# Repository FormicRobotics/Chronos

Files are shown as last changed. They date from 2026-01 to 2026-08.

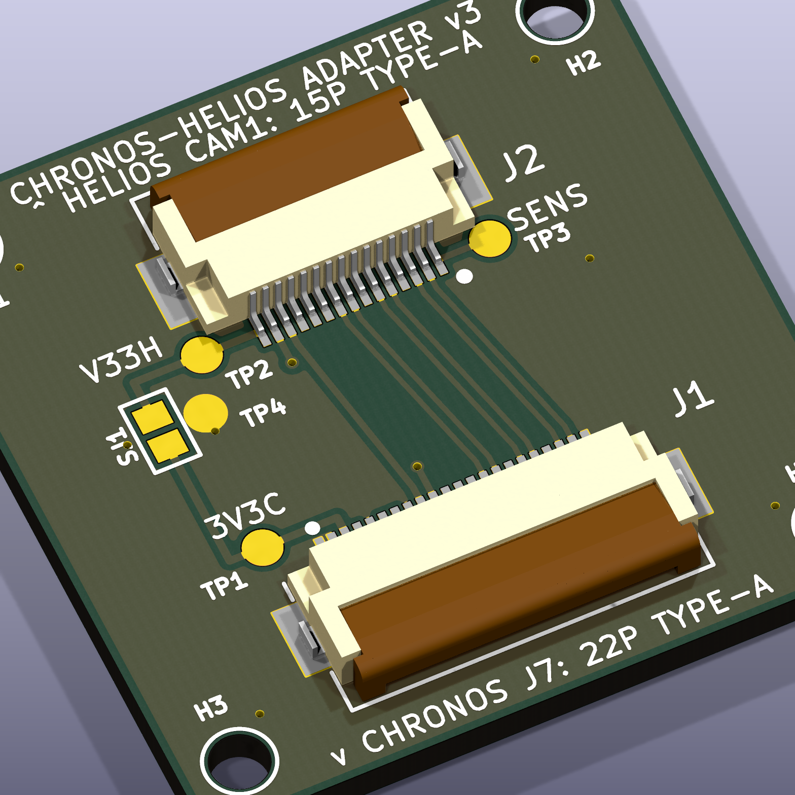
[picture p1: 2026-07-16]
hardware/adapter_chronos_helios/render_3d.png

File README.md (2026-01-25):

<p align="center">
  
  
  
  
</p>

<h1 align="center">⏱️ Chronos</h1>

<p align="center">
  <strong>Multi-Camera MIPI Synchronization System</strong><br>
  <em>Sub-microsecond synchronized capture for computer vision</em>
</p>

<p align="center">
  <a href="#-features">Features</a> •
  <a href="#-architecture">Architecture</a> •
  <a href="#-quick-start">Quick Start</a> •
  <a href="#-documentation">Documentation</a> •
  <a href="#-hardware">Hardware</a>
</p>

---

## ✨ Features

<table>
<tr>
<td width="50%">

### 🎯 Precision Synchronization
- **< 100ns** inter-camera trigger skew
- Hardware-triggered global shutter capture
- PLL-based timing generation
- Per-camera delay calibration

</td>
<td width="50%">

### 🚀 Zero-Copy GPU Pipeline
- Direct DMA to CUDA memory
- NvBuffer + EGL interop
- Triple-buffered capture
- No CPU memcpy overhead

</td>
</tr>
<tr>
<td width="50%">

### 📷 4-Camera Aggregation
- Single CSI-2 port for all cameras
- FPGA virtual channel multiplexing
- 1280×800 @ 120fps per camera
- 10-bit RAW global shutter

</td>
<td width="50%">

### 🔄 Integrated IMU
- BMI088 6-axis IMU
- Synchronized with cameras
- SPI @ 10MHz
- Timestamp correlation

</td>
</tr>
</table>

---

## 🏗️ Architecture

```
┌─────────────────────────────────────────────────────────────────────────┐
│                           CHRONOS SYSTEM                                 │
├─────────────────────────────────────────────────────────────────────────┤
│                                                                          │
│   ┌─────────┐ ┌─────────┐ ┌─────────┐ ┌─────────┐                       │
│   │  CAM 0  │ │  CAM 1  │ │  CAM 2  │ │  CAM 3  │     4× OV9281         │
│   │ OV9281  │ │ OV9281  │ │ OV9281  │ │ OV9281  │     Global Shutter    │
│   └────┬────┘ └────┬────┘ └────┬────┘ └────┬────┘                       │
│        │ CSI-2     │           │           │                             │
│        └───────────┴─────┬─────┴───────────┘                             │
│                          ▼                                               │
│   ┌──────────────────────────────────────────────┐                      │
│   │           CrossLink-NX FPGA                   │     Virtual Channel  │
│   │  ┌────────┐  ┌────────┐  ┌────────────────┐  │     Aggregation      │
│   │  │ 4× RX  │→ │ Buffer │→ │ TX + VC Tag    │  │                      │
│   │  └────────┘  └────────┘  └───────┬────────┘  │                      │
│   │  ┌─────────────────────────────┐ │           │                      │
│   │  │    Trigger Generator (PLL)  │─┼──────────────→ FSIN + IMU        │
│   │  └─────────────────────────────┘ │           │                      │
│   └──────────────────────────────────┼───────────┘                      │
│                                      │ Single 2-lane CSI-2              │
│                                      ▼                                   │
│   ┌──────────────────────────────────────────────────────────────┐      │
│   │                    Jetson Orin NX                             │      │
│   │  ┌─────────┐  ┌─────────┐  ┌─────────┐  ┌─────────────────┐  │      │
│   │  │  NVCSI  │→ │   VI    │→ │ Driver  │→ │   GPU Memory    │  │      │
│   │  │  D-PHY  │  │  DMA    │  │ Demux   │  │   (Zero-Copy)   │  │      │
│   │  └─────────┘  └─────────┘  └─────────┘  └─────────────────┘  │      │
│   └──────────────────────────────────────────────────────────────┘      │
│                                                                          │
└─────────────────────────────────────────────────────────────────────────┘
```

---

## 🚀 Quick Start

### Prerequisites

- NVIDIA Jetson Orin NX with JetPack 5.x
- Chronos PCB (CrossLink-NX FPGA board)
- 4× OV9281 camera modules
- CUDA Toolkit, CMake 3.18+

### Build & Install

```bash
# Clone the repository
git clone https://github.com/your-org/chronos.git
cd chronos

# Build kernel drivers
cd drivers
make all
sudo make install

# Build user-space applications
cd ../app
mkdir build && cd build
cmake ..
make -j$(nproc)
sudo make install
```

### Run Demo

```bash
# Load drivers
sudo modprobe ov9281
sudo modprobe chronos_csi

# Run synchronized capture demo
chronos_demo --rate 60 --exposure 5000

# Run synchronization validation
sync_test -n 1000 -r 120
```

### Example Output

```
Chronos Demo - 4-Camera Synchronized Capture
=============================================
Frame Rate: 60 fps
Exposure: 5000 us

FPS: 60.0  Sync: 1234
  IMU: Accel[  0.02,  -0.01,   9.81] m/s²  Gyro[  0.00,   0.00,   0.00] rad/s
  Frame Sync: Cam0:1234 Cam1:1234 Cam2:1234 Cam3:1234 [SYNC OK]
```

---

## 📁 Project Structure

```
chronos/
├── 📂 fpga/                    # FPGA Firmware
│   ├── 📂 rtl/                 # SystemVerilog sources
│   │   ├── chronos_top.sv      # Top-level module
│   │   ├── csi2_rx.sv          # CSI-2 receivers (×4)
│   │   ├── csi2_tx.sv          # CSI-2 transmitter
│   │   ├── frame_buffer.sv     # SRAM line buffers
│   │   ├── tx_arbiter.sv       # VC multiplexer
│   │   ├── trigger_generator.sv # Sync pulse generator
│   │   └── config_regs.sv      # I2C register bank
│   └── 📂 constraints/         # Timing/pin constraints
│
├── 📂 drivers/                 # Linux Kernel Modules
│   ├── 📂 ov9281/              # OV9281 V4L2 driver
│   ├── 📂 chronos_csi/         # CSI demux driver
│   ├── 📂 imu/                 # BMI088 IIO driver
│   └── chronos-orin-nx.dts     # Device tree overlay
│
├── 📂 app/                     # User-Space Applications
│   └── 📂 src/
│       ├── chronos_capture.h   # Capture library API
│       ├── chronos_capture.c   # Library implementation
│       ├── demo_app.cpp        # Demo application
│       └── sync_test.cpp       # Sync validation tool
│
└── 📂 docs/                    # Documentation
    ├── architecture.md         # System design
    ├── api_reference.md        # API documentation
    └── user_guide.md           # User manual
```

---

## 📖 Documentation

| Document | Description |
|---|---|
| [📐 Architecture](docs/architecture.md) | System design, block diagrams, data flow |
| [📚 API Reference](docs/api_reference.md) | Complete C API documentation |
| [📘 User Guide](docs/user_guide.md) | Installation, usage, troubleshooting |
| [🤝 Contributing](CONTRIBUTING.md) | Development guidelines |

---

## 🔧 Hardware Specifications

| Component | Specification |
|---|---|
| **FPGA** | Lattice CrossLink-NX (LIFCL-40) |
| **Cameras** | 4× OV9281 (1280×800, global shutter) |
| **Interface** | MIPI CSI-2, 2-lane @ 800 Mbps/lane |
| **Output** | Single 2-lane CSI-2 (4 virtual channels) |
| **Sync Accuracy** | < 100 ns trigger skew |
| **Frame Rate** | 1–120 fps (configurable) |
| **IMU** | BMI088 / ICM-42688-P (6-axis) |
| **Power** | ~2.5W total |
| **Temperature** | -10°C to +55°C (commercial) |

---

## 📊 Performance

<table>
<tr>
<th>Metric</th>
<th>Value</th>
<th>Notes</th>
</tr>
<tr>
<td>Inter-camera sync</td>
<td><strong>< 100 ns</strong></td>
<td>99th percentile</td>
</tr>
<tr>
<td>Capture-to-GPU latency</td>
<td><strong>< 5 ms</strong></td>
<td>Zero-copy path</td>
</tr>
<tr>
<td>Max frame rate</td>
<td><strong>120 fps</strong></td>
<td>All 4 cameras</td>
</tr>
<tr>
<td>Aggregate throughput</td>
<td><strong>1.2 Gbps</strong></td>
<td>4× RAW10 streams</td>
</tr>
<tr>
<td>Frame drop rate</td>
<td><strong>< 0.01%</strong></td>
<td>Triple-buffered</td>
</tr>
</table>

---

## 🛠️ API Example

```c
#include <chronos_capture.h>

int main() {
    // Initialize
    chronos_init();
    
    // Configure synchronized capture
    chronos_config_t config = {
        .frame_rate = 60,
        .exposure_us = 5000,
        .external_trigger = true,
        .enable_imu = true,
    };
    chronos_configure(&config);
    
    // Capture loop
    chronos_start_capture();
    while (running) {
        chronos_sync_frame_set_t frames;
        
        if (chronos_get_frame_set(&frames, 1000) == CHRONOS_OK) {
            // Get CUDA pointer (zero-copy!)
            void *gpu_ptr;
            chronos_get_cuda_ptr(&frames.frames[0], &gpu_ptr);
            
            // Run your CUDA kernels here...
            
            chronos_release_frame_set(&frames);
        }
    }
    
    chronos_shutdown();
    return 0;
}
```

---

## 📜 License

| Component | License |
|---|---|
| FPGA Firmware | Proprietary |
| Linux Drivers | GPL v2 |
| User Applications | MIT |

---

## 👥 Authors

**Umit Kayacik** — *Senior Electronics Engineer*

---

<p align="center">
  <em>Built with ❤️ for computer vision applications</em>
</p>

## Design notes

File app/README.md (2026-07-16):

# 📱 Chronos Applications

<p align="center">
  
  
  
</p>

## Overview

User-space capture library and demo applications for the Chronos multi-camera system.

Capture uses plain V4L2 MMAP buffers: every delivered frame exposes a CPU
pointer directly into the driver's buffer, and buffers are only re-queued when
the consumer releases the frame set (so held frames are never overwritten).
An optional CUDA path copies frames into device memory on demand
(`chronos_get_cuda_ptr()`); there is no EGL/NvBuffer dependency.

## 📁 Contents

```
app/
├── src/
│   ├── chronos_capture.h       # Library API header
│   ├── chronos_capture.c       # Library implementation
│   ├── demo_app.cpp            # 4-camera demo with IMU
│   └── sync_test.cpp           # Synchronization validator
│
└── CMakeLists.txt              # Build configuration
```

## 🏗️ Building

### Prerequisites

- CMake 3.18+
- JetPack 5.x or 6.x (V4L2 camera stack)
- CUDA Toolkit (optional — enables the GPU copy path and the demo app)

### Build Steps

```bash
mkdir build && cd build
cmake ..
make -j$(nproc)
```

CUDA is controlled by the `CHRONOS_WITH_CUDA` option (default `ON`; it is
disabled automatically when no CUDA compiler is found). Without CUDA only
the library and `sync_test` are built — `chronos_demo` needs CUDA for its
processing kernels.

```bash
cmake -DCHRONOS_WITH_CUDA=OFF ..
```

### Install

```bash
sudo make install
```

## 📚 Library API

### Quick Example

```c
#include <chronos_capture.h>

// Initialize
chronos_init();

// Configure
chronos_config_t config = {
    .frame_rate = 30,
    .exposure_us = 5000,
    .external_trigger = true,
};
chronos_configure(&config);

// Capture
chronos_start_capture();
while (running) {
    chronos_sync_frame_set_t frames;
    if (chronos_get_frame_set(&frames, 1000) == CHRONOS_OK) {
        // CPU access (mmap'd V4L2 buffer, valid until release)
        uint16_t *pixels = frames.frames[0].data;

        // Optional GPU access (copies the frame to device memory)
        void *gpu;
        chronos_get_cuda_ptr(&frames.frames[0], &gpu);

        // Process...

        chronos_release_frame_set(&frames);
    }
}
chronos_shutdown();
```

### Key Functions

| Function | Description |
|---|---|
| `chronos_init()` | Initialize capture system |
| `chronos_configure()` | Set capture parameters |
| `chronos_start_capture()` | Begin synchronized capture (enables FSIN trigger) |
| `chronos_get_frame_set()` | Get next frame set (blocking) |
| `chronos_get_cuda_ptr()` | Copy frame to GPU, get device pointer |
| `chronos_release_frame_set()` | Re-queue buffers to the drivers |
| `chronos_get_stats()` | Capture statistics + FPGA STATUS/ERROR registers |
| `chronos_shutdown()` | Cleanup and shutdown |

### Notes

- Frame data (`frames[i].data`) points into the driver's MMAP buffer; honor
  `frames[i].pitch` (bytesperline) when walking rows. The CUDA copy is
  tightly packed (pitch = width × 2 bytes).
- `buffer_count` is fixed at `chronos_init()`; passing a different value to
  `chronos_configure()` afterwards returns an error (0 keeps the current value).
- Exposure is programmed in the sensors by the FPGA; the FSIN pulse width can
  be overridden via `config.fsin_pulse_width_cycles` (0 = default 2000 cycles
  of the 192 MHz FPGA clock, ~10.4 µs).
- If the consumer never releases a frame set, capture stalls gracefully and
  drops are counted in the statistics — held frames are never corrupted.

## 🎮 Demo Application

### Usage

```bash
chronos_demo [options]

Options:
  -r, --rate <fps>      Frame rate (1-120, default: 30)
  -e, --exposure <us>   Exposure time (default: 5000)
  -g, --gain <dB>       Analog gain (default: 0.0)
  -d, --duration <sec>  Run duration (0=infinite)
  -n, --no-imu          Disable IMU display
  -H, --headless        No display output
  -h, --help            Show help
```

When built with OpenCV and not running headless, the demo shows a live 2×2
mosaic of all four cameras.

### Examples

```bash
# Basic 30fps capture (design point)
chronos_demo --rate 30

# Headless benchmark
chronos_demo --rate 30 --headless --duration 60
```

## 🧪 Sync Test

### Usage

```bash
sync_test [options]

Options:
  -n <count>    Number of frames to test (default: 1000)
  -r <fps>      Frame rate (default: 30; 120 = stress mode)
  -v            Verbose output
  -h            Show help
```

The default 30 fps matches the system design point (4 cameras aggregated
onto a 2-lane CSI-2 link). `-r 120` is a stress mode that exceeds the
aggregate TX bandwidth with all four cameras active — expect drops.

### Example Output

```
=== SYNCHRONIZATION TEST RESULTS ===

Inter-Camera Skew (all 4 cameras):
  Mean:       42.1 us
  Max:        89.2 us
  99th %ile:  76.4 us
  RESULT:     PASS (requirement: <100 us)

Frame Interval:
  Expected:   33333.3 us
  Mean:       33334.1 us
  Error:      0.01%
  RESULT:     PASS (requirement: <1% error)

=== OVERALL: ALL TESTS PASSED ===
```

## ⚡ Usage Tips

1. **Release Promptly**: Call `chronos_release_frame_set()` ASAP — buffers are
   not re-queued until then, so holding sets stalls capture
2. **CPU First**: The CPU pointer is free; only call `chronos_get_cuda_ptr()`
   when you actually process on the GPU (it performs a host-to-device copy)
3. **Batch Processing**: Process all 4 frames together in CUDA
4. **Async Mode**: Use callbacks for lowest latency
5. **Triple Buffering**: Default setting prevents drops

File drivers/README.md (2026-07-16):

# Chronos Linux Drivers

Jetson-side kernel modules for the Chronos multi-camera synchronization
system. Target: **NVIDIA Jetson Orin NX**, L4T r35/r36 (kernel 5.10/5.15),
Tegra camera stack. License: GPL v2.

## Architecture (what the Jetson actually sees)

A Lattice CrossLink-NX FPGA aggregates four OV9281 cameras (1280x800 RAW10
monochrome, FSIN hardware-triggered, 30 fps design point) into **one 2-lane
MIPI CSI-2 link** with virtual channels VC0..VC3 (VC = camera index).

- The Jetson **cannot** reach the sensors over I2C — the FPGA owns
  per-camera private SCCB buses and configures the sensors itself. There is
  no I2C mux.
- The ICM-42688-P IMU is wired to the FPGA only. The Jetson has no path
  to it.
- The **only** Jetson-visible control interface is the FPGA I2C slave at
  7-bit address `0x3C` (CTRL, FRAME_RATE, PULSE_WIDTH, CAM_ENABLE, STATUS,
  ERROR, per-camera FRAME_CNT, VERSION `0x10`, ID `0xC405`).

```
4x OV9281 --SCCB/CSI--> CrossLink-NX FPGA --2-lane CSI-2 (VC0..3)--> Jetson NVCSI/VI
                              ^
                              | I2C 0x3C (control only)
                           Jetson i2c2
```

## Components

```
drivers/
├── Makefile                    # Top level: builds chronos_fpga + chronos_csi
├── chronos_fpga/               # FPGA control driver (i2c, "chronos,fpga-ctrl")
│   ├── chronos_fpga.c          # regmap + sysfs + exported in-kernel API
│   ├── chronos_fpga.h          # register map + API for consumers
│   ├── Makefile / Kconfig
├── chronos_csi/                # Aggregated CSI-2 source bridge
│   ├── chronos_csi.c           # V4L2 subdev ("chronos,csi-bridge"), no video nodes
│   ├── Makefile / Kconfig
├── chronos-orin-nx.dts         # DT overlay: FPGA node, bridge, NVCSI, VI (4 VCs)
├── ov9281/                     # NOT USED on Chronos (FPGA owns the sensors)
└── imu/                        # NOT USED on Chronos (IMU is FPGA-attached)
```

### chronos_fpga

I2C driver for the FPGA control interface. Verifies ID/VERSION at probe
(warns on mismatch), exposes sysfs attributes under the device
(`/sys/bus/i2c/devices/<bus>-003c/`):

| Attribute | Access | Meaning |
|---|---|---|
| `trigger_enable` | rw | FSIN trigger generator on/off |
| `frame_rate` | rw | fps, 1..120 (design point 30) |
| `pulse_width` | rw | FSIN pulse width, 16-bit |
| `cam_enable` | rw | camera enable bitmask, bits 3:0 |
| `soft_reset` | wo | write 1 to soft-reset (self-clearing) |
| `status` | ro | decoded: pll_locked + cam_sync bits |
| `error` | ro | decoded: rx_error + buf_overflow bits |
| `frame_count_0..3` | ro | per-camera 16-bit frame counter |
| `version`, `id` | ro | bitstream version / device ID |

It also exports an in-kernel API (`chronos_fpga_trigger_enable`,
`chronos_fpga_set_frame_rate`, `chronos_fpga_read_status`,
`chronos_fpga_get_client`) used by the bridge.

### chronos_csi

A media-controller **V4L2 subdevice** — not a video-node driver. It
represents the FPGA's aggregated CSI-2 source toward NVCSI: fixed
1280x800 `MEDIA_BUS_FMT_Y10_1X10`, one source pad, async-registered so the
Tegra VI/NVCSI graph binds it through the DT endpoint. Its `s_stream`
starts/stops the FPGA FSIN trigger (first stream on / last stream off).
The Tegra VI creates the `/dev/video*` nodes and handles all DMA.

### chronos-orin-nx.dts

Overlay with the real topology: FPGA control node on `i2c2`, one bridge
node whose single source port carries four endpoints (one per VC, all on
the same physical 2-lane link into NVCSI port A), four NVCSI channels and
a VI with `num-channels = <4>` - paired strictly 1:1 (bridge endpoint N ->
NVCSI channel N -> VI port N) with `vc-id = <0..3>` on every endpoint, the
mechanism L4T uses for multi-VC GMSL. Four minimal `tegra-camera-platform`
module entries reference the bridge subdev and size the bandwidth budget.

## Building

Per directory (or use the top-level Makefile which handles the ordering):

```bash
# Cross-compilation environment (or build on the Jetson with
# nvidia-l4t-kernel-headers installed)
export CROSS_COMPILE=aarch64-linux-gnu-
export ARCH=arm64
export KDIR=/path/to/jetson/kernel/build

cd drivers
make            # builds chronos_fpga.ko, then chronos_csi.ko
sudo make install && sudo depmod -a
```

`chronos_csi` uses symbols exported by `chronos_fpga`, so the top-level
Makefile builds `chronos_fpga` first and passes its `Module.symvers` via
`KBUILD_EXTRA_SYMBOLS`.

Compile the overlay:

```bash
dtc -@ -I dts -O dtb -o chronos-orin-nx.dtbo chronos-orin-nx.dts
sudo cp chronos-orin-nx.dtbo /boot/
# then register it via /boot/extlinux/extlinux.conf (FDT/OVERLAYS) or
# /opt/nvidia/jetson-io/jetson-io.py
```

## What works vs. what needs L4T integration

Works with just these modules:

- FPGA register access, sysfs control/status, FSIN trigger start/stop.
- The bridge subdev appearing in the media graph as the CSI source.

Requires L4T-side integration (kernel DT merge on the flashed system):

- **VI/NVCSI channel setup**: the overlay's `vi`/`nvcsi` fragments must
  apply on top of the platform DT; verify the resulting channels with
  `media-ctl -p`. Multi-VC capture needs an L4T release where the VI
  honors `vc-id` (r35+).
- **Argus / nvarguscamerasrc**: needs full per-mode tables (`mode0` etc.)
  in the tegra-camera-platform modules matching the FPGA's timing. The
  entries shipped here are minimal; plain V4L2 capture does not need them.

## Bring-up sequence

```bash
# 1. Load the FPGA control driver and verify the FPGA answers
sudo modprobe chronos_fpga
cat /sys/bus/i2c/devices/2-003c/id        # expect 0xc405
cat /sys/bus/i2c/devices/2-003c/version   # expect 0x10
cat /sys/bus/i2c/devices/2-003c/status    # expect pll_locked=1

# 2. Apply the overlay (reboot) so the bridge/NVCSI/VI graph exists,
#    then load the bridge
sudo modprobe chronos_csi
media-ctl -p                              # bridge entity linked to NVCSI

# 3. Capture per virtual channel (VC n -> /dev/video n)
v4l2-ctl -d /dev/video0 --set-fmt-video=width=1280,height=800,pixelformat=Y10 \
         --stream-mmap --stream-count=30
```

Useful raw I2C checks (bus 2 assumed):

```bash
i2cget -y 2 0x3c 0xf0   # VERSION = 0x10
i2cget -y 2 0x3c 0x20   # STATUS (bit0 = pll_locked)
i2cset -y 2 0x3c 0x00 0x01   # manually enable the FSIN trigger
```

## Not used on this board

- `ov9281/` — full sensor driver; the sensors are unreachable from the
  Jetson and FPGA-configured. Kept as reference only. Do not load.
- `imu/` — Jetson SPI driver for the ICM-42688-P; the IMU is FPGA-attached.
  Kept for a future hardware revision or FPGA proxy. Do not load.
  See `imu/README.md`.

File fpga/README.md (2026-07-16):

# 🔧 Chronos FPGA Firmware

<p align="center">
  
  
  
</p>

## Overview

This directory contains the FPGA firmware for the Chronos multi-camera synchronization system. The design aggregates four MIPI CSI-2 camera streams into a single output using virtual channel multiplexing.

## 📁 Directory Structure

```
fpga/
├── rtl/                        # RTL Source Files
│   ├── chronos_top.sv          # Top-level integration
│   ├── csi2_rx.sv              # CSI-2 receiver (×4 instances)
│   ├── csi2_tx.sv              # CSI-2 transmitter
│   ├── frame_buffer.sv         # SRAM line buffers
│   ├── tx_arbiter.sv           # Virtual channel multiplexer
│   ├── trigger_generator.sv    # Precision sync pulse generator
│   ├── chronos_pll.sv          # Clock generation
│   ├── i2c_slave.sv            # Configuration interface
│   └── config_regs.sv          # Register bank
│
├── constraints/                # Design Constraints
│   └── chronos_pinout.pdc      # Pin assignments & timing
│
└── tb/                         # Testbenches
    └── (simulation files)
```

## 🏗️ Architecture

```
        ┌─────────────────────────────────────────────────────┐
        │              CrossLink-NX FPGA                       │
        │                                                      │
CSI-2   │  ┌────────┐   ┌──────────┐   ┌────────────┐        │  CSI-2
Cam0 ───┼─▶│ RX[0]  │──▶│          │   │            │        │  Output
Cam1 ───┼─▶│ RX[1]  │──▶│  Frame   │──▶│    TX      │────────┼──▶
Cam2 ───┼─▶│ RX[2]  │──▶│  Buffers │   │  Arbiter   │        │  (VC0-3)
Cam3 ───┼─▶│ RX[3]  │──▶│          │   │            │        │
        │  └────────┘   └──────────┘   └────────────┘        │
        │                                                      │
        │  ┌────────────────┐     ┌─────────────────────────┐ │
        │  │    Trigger     │────▶│  To FSIN (×4) + IMU     │ │
        │  │   Generator    │     └─────────────────────────┘ │
        │  └───────┬────────┘                                 │
        │          │                                          │
        │  ┌───────▼────────┐     ┌──────────────┐           │
        │  │  Config Regs   │◀───▶│  I2C Slave   │◀──────────┼── I2C
        │  └────────────────┘     └──────────────┘           │
        │                                                      │
        └─────────────────────────────────────────────────────┘
```

## 🔑 Key Modules

| Module | Description | Resources |
|---|---|---|
| `csi2_rx` | MIPI CSI-2 receiver with D-PHY | Hard IP |
| `frame_buffer` | 4K-entry SRAM FIFO | ~16KB SRAM |
| `tx_arbiter` | Round-robin VC mux | ~500 LUTs |
| `csi2_tx` | MIPI CSI-2 transmitter | Hard IP |
| `trigger_generator` | PLL-based sync pulse | ~200 LUTs |
| `config_regs` | 256-byte register bank | ~300 LUTs |

## 📋 Register Map

| Address | Name | Access | Description |
|---|---|---|---|
| `0x00` | CTRL | R/W | Control (enable, reset) |
| `0x01` | FRAME_RATE | R/W | Target fps (1-120) |
| `0x02-03` | PULSE_WIDTH | R/W | Trigger width |
| `0x04` | CAM_ENABLE | R/W | Camera enable mask |
| `0x10-13` | TRIG_DELAY[0-3] | R/W | Per-camera delays |
| `0x20` | STATUS | R | PLL lock, sync status |
| `0x21` | ERROR | R | Error flags |
| `0x30-37` | FRAME_CNT[0-3] | R | Frame counters |
| `0xF0` | VERSION | R | Firmware version |
| `0xFE-FF` | DEVICE_ID | R | Device ID (0xC405) |

## 🛠️ Building

### Prerequisites

- Lattice Radiant 3.2 or later
- CrossLink-NX device support package

### Build Steps

```bash
# Open project in Radiant GUI
radiantc chronos.rdf

# Or command-line synthesis
radiantc -t "CrossLink-NX" -d "LIFCL-40" \
         -p "QFN72" -s "7" \
         chronos_top.sv

# Generate bitstream
radiantc --bitstream chronos.bit
```

### Programming

```bash
# Program via JTAG
pgrcmd -infile chronos.bit
```

## 📊 Resource Utilization

| Resource | Used | Available | Utilization |
|---|---|---|---|
| LUTs | ~8,000 | 39,000 | 21% |
| Registers | ~4,000 | 39,000 | 10% |
| SRAM | 64 KB | 200 KB | 32% |
| D-PHY | 5 | 8 | 63% |
| PLL | 1 | 4 | 25% |

## ⚡ Timing

- System clock: 192 MHz (12 MHz ref x 16; see chronos_pll.sv)
- MIPI data rate: 800 Mbps/lane
- Trigger skew: < 100 ns (20 cycles)

## 🧪 Simulation

Three self-checking testbenches live in `sim/` (all PASS with Icarus Verilog):

- `tb_chronos_csi2.sv` - CSI-2 datapath loopback (RX -> frame_buffer -> arbiter -> TX)
- `tb_i2c_slave.sv` - I2C master BFM against `i2c_slave` + `config_regs`
- `tb_trigger_generator.sv` - phase-accumulator rate engine (exact fps, clamping)

```powershell
cd sim
powershell -File run_sims.ps1     # requires iverilog/vvp (OSS CAD Suite)
```

## 📝 Notes

- D-PHY IP is hardened in CrossLink-NX (no soft implementation)
- Use Radiant IP Catalog for DPHY_RX and DPHY_TX instantiation
- PLL configuration via IP Catalog (PLL_CORE primitive)

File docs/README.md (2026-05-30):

# 📖 Chronos Documentation

Welcome to the Chronos documentation! This directory contains technical documentation for the multi-camera synchronization system.

## 📚 Available Documents

| Document | Description |
|---|---|
| [🏗️ Architecture](architecture.md) | System design, block diagrams, data flow |
| [📚 API Reference](api_reference.md) | Complete C API documentation with examples |
| [📘 User Guide](user_guide.md) | Installation, configuration, troubleshooting |
| [🔬 Hardware ↔ Firmware Audit](hardware_firmware_audit.md) | Pinout map, mismatches found, fixes applied |

## 🗺️ Quick Navigation

### Getting Started
→ Start with the [User Guide](user_guide.md) for installation and basic usage.

### Understanding the System
→ Read [Architecture](architecture.md) for system design and data flow.

### Programming
→ See [API Reference](api_reference.md) for library functions and examples.

### Development
→ Check [CONTRIBUTING.md](../CONTRIBUTING.md) for coding standards and guidelines.

## 🔗 External Resources

- [NVIDIA Jetson Documentation](https://docs.nvidia.com/jetson/)
- [V4L2 API Documentation](https://www.kernel.org/doc/html/latest/userspace-api/media/v4l/v4l2.html)
- [MIPI CSI-2 Specification](https://www.mipi.org/specifications/csi-2)
- [Lattice Radiant Documentation](https://www.latticesemi.com/Products/DesignSoftwareAndIP/FPGAandLDS/Radiant)

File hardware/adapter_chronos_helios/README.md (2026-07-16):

# Chronos J7 <-> Aerium Helios CAM1 adapter PCB (v3)

Small (28 x 28 mm, 4-layer) adapter that safely connects the Chronos board's
custom 22-pin CSI output (J7) to the Aerium Helios carrier's standard
Raspberry-Pi-style 15-pin CAM1 port. A direct cable between the two is **not**
possible: J7 uses a custom pinout (SDA/SCL order reversed, 3.3V on pins 19/20,
GND on pin 15) that would short Helios 3.3V to GND and put 3.3V on I2C lines.

**v3 change (pin-1 orientation verified on hardware):** with the two boards
face to face and flat cables, **both pin 1s sit on the same absolute side**
(user-verified on the physical boards, 2026-07). The Chronos link mirrors
through its cable as normal facing FH12s do (J7 pin i lands on J1 pad 23-i),
but the Helios CAM1 connector is opposite-handed, so its link maps **straight**
(CAM1 pin j lands on J2 pad j). The two effects nearly cancel: v3 routes all
six CSI conductors as identical straight diagonals on the top layer with
**zero vias**, and only the I2C SDA/SCL swap needs one inner-layer crossing.

Open `chronos_helios_adapter.kicad_pcb` in KiCad 10 (board file is the source
of truth; there is no schematic - the netlist lives in the board).
DRC: 0 errors / 0 unconnected items; only informational "library footprint
mismatch" warnings remain (universal mounting-tab pads, see `drc_report.txt`).

## Connections

```
CHRONOS J7                      ADAPTER                       HELIOS CAM1
(22p custom)  straight 22p   J1 <- remap -> J2     straight 15p   (15p RPi std)
    [J7] ==== Type-A FFC ==== [J1]          [J2] ==== Type-A FFC ==== [CAM1]
              (mirrors i->23-i)              (straight j->j)
```

- **J1** (22P 0.5 mm bottom contact, FH12-22S / XUNPU FPC-05F-22PH20): to
  Chronos J7 with a **straight 22-pin 0.5 mm Type-A (same-side contacts) FFC**.
  Facing receptacles mirror the mapping through the cable (J7 pin i lands on
  J1 pad 23-i); the netlist accounts for this.
- **J2** (15P 0.5 mm bottom contact, FH12-15S / XFCN F0502-B-15-15T-R): to
  Helios CAM1 with a **straight 15-pin 0.5 mm Type-A FFC**. The Helios CAM
  connector is opposite-handed (pin 1 on the same absolute side as J7's, as
  verified on the hardware), so this link maps **straight**: CAM1 pin j lands
  on J2 pad j, baked into the netlist.
- Net result on the board: every CSI net leaves J1 and reaches J2 shifted a
  constant 1.75 mm sideways - all six conductors are equal-length top-layer
  diagonals (no vias, no skew). Only SDA crosses SCL once, on inner layer
  In2.Cu over the solid B.Cu ground plane.

### Signal map

| Function | Chronos J7 | Adapter J1 pad | Adapter J2 pad | Helios CAM1 (15p) |
|---|---|---|---|---|
| CSI D0- / D0+ | 2 / 3 | 21 / 20 | 2 / 3 | 2 / 3 |
| CSI D1- / D1+ | 5 / 6 | 18 / 17 | 5 / 6 | 5 / 6 |
| CSI CLK- / CLK+ | 8 / 9 | 15 / 14 | 8 / 9 | 8 / 9 |
| I2C SDA | 13 | 10 | 14 | 14 |
| I2C SCL | 14 | 9 | 13 | 13 |
| Chronos 3.3V | 19, 20 | 3, 4 | - (TP1 / SJ1 only) | - |
| Helios 3.3V | - | - | 15 (TP2 / SJ1 only) | 15 |
| SENSE (orientation check) | - | - | 1 (TP3 only) | 1 (GND) |
| GND | 1,4,7,10,12,15,18,21,22 | 1,2,5,8,11,13,16,22 | 4,7,10 | 4,7,10 |

The I2C swap (Chronos has SDA=13/SCL=14, RPi standard has SCL=13/SDA=14) is
done on the adapter. The two 3.3V rails are **never** connected to each other:
SJ1 solder jumper stays **OPEN** (each board powers itself). J1 pad 19 is left
unconnected on purpose (safety if a wrong cable type is used), and J2 pad 1
is the SENSE_H net (TP3 only) - in the correct orientation it sees CAM1 GND;
with a wrong/mirror cable it would see CAM1 3.3V harmlessly.

## Bring-up / polarity verification (do this BEFORE full hookup)

FFC orientation mistakes are the only real risk; the board is designed so a
wrong cable type causes no damage and is detectable:

1. **Chronos side**: power Chronos (USB), connect only J7 -> J1 with the 22p
   cable. Measure **TP1 (3V3C)**: must read **3.3 V** (and TP4 = GND beeps to
   Chronos ground). If TP1 does not read 3.3 V, the cable is the wrong
   contact type - swap the 22p cable between Type-A (same-side) and Type-B
   (reverse/opposite-side). Keep this wrong-state power-on brief.
2. **Helios side**: with Chronos disconnected, power Helios, connect CAM1 ->
   J2 with the 15p cable. Measure **TP2 (V33H)**: must read **3.3 V**, and
   **TP3 (SENS)** must beep to ground. If instead TP3 shows 3.3 V and TP2
   reads 0, the cable is the wrong contact type - swap the 15p cable between
   Type-A and Type-B.
3. Only after both checks pass, connect everything together (SJ1 open).

Cables must lie **flat** between the boards (no folds or twists) - a folded
FFC flips the mapping and will show up in the TP checks above.

## Differential pair design (100 ohm, MIPI D-PHY)

Stackup: **4-layer 1.6 mm, JLCPCB JLC04161H-7628** (or equivalent):
L1 signal / L2 GND plane / L3 (SDA crossing only) / L4 GND plane.
Outer prepreg 7628 = 0.21 mm on both sides, Er ~ 4.4/4.6.

- All six CSI conductors run on **L1 over the L2 plane** for their entire
  length: w = 0.20 mm, pair pitch 0.5 mm at the pads (Zdiff ~ 105-117 ohm,
  within the 80-125 ohm D-PHY tolerance), total length ~9.6 mm (~65 ps),
  **zero vias**, and all six diagonals are geometrically identical so
  intra-pair and inter-pair skew are both zero by construction.
- I2C: SCL runs on L1; SDA dives to **In2.Cu (L3)** through two 0.5/0.3 mm
  vias to cross SCL (no impedance requirement at 400 kHz).
- In2.Cu carries nothing else and has no copper pour; In1.Cu and B.Cu are
  solid GND zones stitched with 0.6/0.3 mm vias.

**When ordering choose "Impedance control: JLC04161H-7628"** and keep L2/L4
as the solid GND planes.

## Mechanical

- 4x M2 mounting holes (H1-H4, 2.2 mm NPTH) in the corners, centers 2.3 mm
  from each edge - fits M2 screws + standoffs.
- Both connectors have 3D models assigned (KiCad standard lib FH12 models),
  so the 3D viewer (Alt+3) shows the assembled board.
- Cable exits: J2 opening faces the top edge (toward Helios), J1 opening
  faces the bottom edge (toward Chronos).

## Fabrication at JLCPCB (verified 2026-07)

Ready-to-upload outputs are in `fab/`:

- `chronos_helios_adapter_gerbers.zip` - Gerbers + Excellon drills (upload as-is)
- `jlc_bom.csv` / `jlc_cpl.csv` - BOM and CPL in JLC assembly format

Order options:

- **Layers 4, thickness 1.6 mm**, and set **Impedance Control: yes ->
  JLC04161H-7628**. Layer order in the zip: `.gtl` = L1, `.g1` = L2 (GND),
  `.g2` = L3 (SDA crossing), `.gbl` = L4 (GND).
- Everything is inside standard capabilities (checked against JLC 4-layer
  rules): min track/gap used 0.20/0.15 mm (cap. 0.09/0.09), signal vias
  0.5/0.3 mm and GND vias 0.6/0.3 mm (cap. 0.45/0.2), NPTH 2.2 mm,
  copper-to-edge >= 0.3 mm outer / 0.4 mm inner, silkscreen >= 0.8 mm text.
- LeadFree/HASL either is fine; ENIG is nicer for the 0.5 mm pads but not
  required.

### Connectors (BOM check)

Genuine Hirose FH12 parts are out of stock at LCSC, so the BOM uses
pin-compatible clones (both in stock, JLC "Extended" parts):

- **J1: XUNPU FPC-05F-22PH20, LCSC C2856804** - 22P 0.5 mm bottom-contact,
  hinged-lid ZIF for 0.3 mm FFC (~$0.10/pc, MOQ 5).
- **J2: XFCN F0502-B-15-15T-R, LCSC C2844857** - 15P 0.5 mm bottom-contact,
  hinged-lid ZIF for 0.3 mm FFC (in stock ~2.4k pcs).
- Mounting-tab pads on both footprints are **enlarged to 2.1 x 2.9 mm** to
  cover the tab positions of both the Hirose originals and the clones - so
  either brand solders onto this board.
- If you prefer genuine Hirose (FH12-22S-0.5SH(55) / FH12-15S-0.5SH(55)),
  buy from Mouser/DigiKey and hand-solder; nothing changes on the PCB.
- In the JLC assembly preview, verify the connector **opening faces the board
  edge** (cable exits outward) on both J1 and J2; fix rotation in their tool
  if their part library orientation differs.

TPs, SJ1 and H1-H4 are bare copper/holes - no other parts to source.

### Cables (both plain, no special Aerium cable)

- 1x **22-pin 0.5 mm Type-A** (same-side contacts) FFC, ~50-100 mm.
- 1x **15-pin 0.5 mm Type-A** (same-side contacts) FFC, ~50-100 mm.
- Order one Type-B (reverse) of each as insurance - they cost cents (LCSC
  custom cables, MOQ 1). The TP checks above tell you which type is right
  without risking damage.

## Files

- `chronos_helios_adapter.kicad_pcb` - the board (open in KiCad 10)
- `chronos_helios_adapter.kicad_pro` - project file (incl. CSI_100R netclass)
- `drc_report.txt` - last DRC run (0 errors, footprint-lib warnings only)
- `render_top.png` / `render_3d.png` - previews
- `fab/` - JLCPCB-ready Gerber zip, drills, BOM (`jlc_bom.csv`),
  CPL (`jlc_cpl.csv`)
- `_gen_v3.py` / `_fill_zones.py` - generator scripts used to build the board
- `_check_map.py` - end-to-end J7 -> CAM1 signal-map verification (PASS)

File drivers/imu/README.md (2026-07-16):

# ICM-42688-P IMU driver — NOT used on Chronos R1

On the Chronos board (HW_CHRONOS_R1) the ICM-42688-P IMU (IC1) is wired
**only to the FPGA**:

- SPI (CS / SCLK / SDI / SO) goes to CrossLink-NX pins.
- INT1 goes to FPGA pin Y7.
- FSYNC is driven by the FPGA with the same edge that triggers the cameras.

The Jetson has **no SPI or GPIO path** to this device. This Jetson-side SPI
driver therefore cannot bind to real hardware on Chronos R1, there is no IMU
node in `drivers/chronos-orin-nx.dts`, and the module **must not be loaded**
on this board.

## Why is the code still here?

It is retained for two possible futures:

1. A hardware revision that routes the IMU SPI/INT to the Jetson — this
   driver would then work as-is with a proper `spi` DT node.
2. An FPGA-side SPI master (currently future work in the RTL) that proxies
   IMU samples through the FPGA's I2C register file at 0x3C. In that case
   the register access layer here serves as a reference for the sample
   decoding and FSYNC-tag handling, but the transport would have to be
   rewritten against the `chronos_fpga` driver.

## Building

Excluded from the top-level `drivers/Makefile` on purpose. If you need it
for a future board revision:

```bash
cd drivers/imu
make KDIR=/path/to/kernel/build
```

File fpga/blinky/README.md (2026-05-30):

# Chronos Blinky — FPGA Bring-up Sanity Check

Bu klasör, HW_CHRONOS_R1 kartı üzerindeki Lattice **CrossLink-NX (LIFCL-40)** FPGA
için **mümkün olan en küçük bitstream**'i içerir.  Tek amacı: Radiant toolchain'in
bitstream üretebildiğini, FT2232 üzerinden JTAG ile yüklediğimiz bitstream'in
gerçekten FPGA'da çalıştığını, ve dört yeşil LED'in mantıksal kontrol altında
olduğunu kanıtlamak.

## İçerik

| Dosya | Açıklama |
|---|---|
| `chronos_blinky.sv` | RTL — internal HFOSC + 28-bit sayaç + LED çıkışları |
| `chronos_blinky.pdc` | Pin constraint — 4 LED + GSRN reset |
| `build_blinky.tcl` | Radiant otomatik build scripti |

## Beklenen sonuç

Bitstream yüklendiğinde:
- **D14, D15, D16, D17** yeşil LED'leri bir ikili sayım deseninde yanıp söner
- En hızlısı ~0.4 s, en yavaşı ~3 s'de bir toggle yapar
- **SW4** (GSRN) butonuna basınca sayaç sıfırlanır → tüm LED'ler söner
- Bırakınca sayım yeniden başlar

## Çalıştırma — iki yol

### Yol 1: Otomatik (önerilen)

PowerShell veya cmd:

```powershell
cd C:\Projects\Github\Chronos\fpga\blinky
& "C:\lscc\radiant\<sürüm>\bin\nt64\pnmainc.exe" build_blinky.tcl
```

`<sürüm>` yerine kurulu Radiant sürümünü yaz (örn. `2024.2`).
Script bitince `impl1\chronos_blinky_impl1.bit` üretilmiş olur.

### Yol 2: GUI üzerinden

1. **Radiant Design Tool**'u (Programmer değil) aç.
2. **File → New → Project**:
   - Project name: `chronos_blinky`
   - Location: `C:\Projects\Github\Chronos\fpga\blinky`
   - Implementation: `impl1`
3. Device:
   - Family: **LIFCL (CrossLink-NX)**
   - Device: **LIFCL-40**
   - Package: **CABGA400** (BG400)
   - Speed: any (e.g. `-9`)
   - Operating: Industrial veya Commercial
4. Add Source:
   - `chronos_blinky.sv`
5. Add Constraint:
   - `chronos_blinky.pdc`
6. Sol panelde **Process** sekmesi → şu sırada çalıştır:
   - Synthesize Design
   - Map Design
   - Place & Route Design
   - Export Files → Bitstream File

## Bitstream'i yükleme — KRİTİK ES (Engineering Sample) AYARLARI

Chronos R1 kartındaki LIFCL-40 chip **Engineering Sample** (ES) — JTAG IDCODE
`0x010F1043`.  Radiant Design Tool ise bitstream'i her zaman üretim IDCODE'u
(`0x110F1043`) ile üretir — bu **normaldir**.  Programmer'ı doğru aileye
ayarlarsanız, üretim-IDCODE bitstream'i ES chip'i üzerinde sorunsuz çalışır.

### Programmer ayarları (sırayla)

1. **Radiant Programmer**'ı kapat, tekrar aç. **Detect Cable** → `HW-USBN-2B (FTDI)`,
   Port `FTUSB-0`.
2. Cihaz satırını çift tıkla → **Device Properties** aç.
3. **Device** sekmesinde:
   - **Device Family**: `LIFCL_ENG`        ← **MUTLAKA bu**, asla `LIFCL` değil!
   - **Device**: `LIFCL-40-ES`
4. **General** sekmesinde:
   - **Access Mode**: `Direct Programming`
   - **Operation**: `Fast Configuration`   (SRAM'e yükler, test için ideal)
   - **Port Interface**: `JTAG`            ← **NOT** `Slave SPI`
   - **File Name**: `impl1\chronos_blinky_impl1.bit`
5. **OK** → tabloda satır güncellensin.
6. Üst menü → **Edit → Cable and I/O Port Settings** (veya cable settings ikonu):
   - **TCK Divider**: `8`  (ya da daha yüksek — ES için daha güvenli)
7. **Run → Program** (yeşil ok).

Beklenen log:

```
INFO  - Operation: SRAM Erase, Program, Verify
INFO  - Device1 LIFCL-40-ES: Operation Done.
INFO  - Elapsed Time = ...
INFO  - All Operation Done. No errors.
```

Aynı anda:
- **D17 (kırmızı INITN)** söner
- **D18 (yeşil DONE)** yanar  ← config başarılı sinyali
- **D14..D17 yeşil LED'ler** ikili sayım yapmaya başlar

> Lattice resmi FAQ (FPGA-AN-02048): _"How to solve error in programming ES?
> Use 'LIFCL_ENG' as the device family instead of 'LIFCL'. This solves any
> programming issue. Also, vary the TCK divider to slow down the programming
> speed."_

## Sorun giderme

| Belirti | Olası neden | Çözüm |
|---|---|---|
| `Mismatch to the device ID code. Current: 0x010F1043, Expected: 0x110F1043` | Programmer'da Family `LIFCL` seçili | Family'i **`LIFCL_ENG`** yap |
| `Failed to read the Device's IDCODE` | JTAG TAP stuck | 12 V'yi çek-tak (USB'yi de) → Programmer'ı yeniden aç → Detect Cable |
| `File is invalid for the expected device` | .bit dosyası manuel modifiye edilmiş / yanlış part | Fresh build üret (build_blinky.tcl), patched veya eski .bit kullanma |
| `Programming failed` (uzun süre takılır) | TCK çok hızlı | TCK Divider'ı 8 → 16 → 30 dene |
| DONE LED yanmıyor, INITN açık kalıyor | Bitstream config tamamlanamadı | TCK Divider artır, Port Interface JTAG mı kontrol et, J44 jumper 1-2 pinde mi |
| Tüm LED'ler statik (sayım yok) | OSC_CORE primitive hatası | Radiant log'da synth uyarılarına bak, OSC çalıştığını HFOSC log'unda doğrula |
| `OSC_CORE` undefined | Eski Radiant sürümü | IP Catalog'tan PMI_OSC üret veya OSCA primitive'ini dene |
| Program başarılı ama LED yanmıyor | LED polarite ters / yanlış pin | PDC'de E17/F13/G13/F14 doğru, `IO_TYPE=LVCMOS33` ayarı doğru mu |

## Sonraki adım

Blinky çalıştığında:
1. Tam Chronos tasarımına geç (`fpga/rtl/`)
2. PLL'i Radiant IP Catalog'tan üret (PLL_CORE wrapper)
3. D-PHY hard IP'sini IP Catalog'tan üret
4. PDC SDC clock path'lerini düzelt
5. Sentez → P&R → Bitstream
6. Aynı şekilde yükle

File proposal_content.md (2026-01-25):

PROJECT PROPOSAL
Multi-Camera MIPI Synchronization System
for NVIDIA Jetson Orin NX Platform
Prepared For:
Dov Katz
Prepared By:
Umit Kayacik
Date:
December 11, 2025
Version:
2.0
1. Executive Summary
This proposal outlines the development of a custom PCB system designed to synchronize four MIPI cameras and aggregate their image streams into a single 2-lane MIPI CSI-2 output for delivery to an NVIDIA Jetson Orin NX platform. The system utilizes a Lattice CrossLink-NX FPGA for camera stream aggregation via virtual channels, enabling all four synchronized cameras to share a single CSI port. Hardware-triggered synchronization ensures sub-microsecond accuracy, with zero-copy transfer of synchronized frames directly into GPU memory for computer vision processing.
2. Project Overview
2.1 Objectives
Design and fabricate a custom PCB to interface 4x OV9281 MIPI cameras
Implement hardware-level synchronization via trigger signals
Aggregate 4 camera streams into single 2-lane MIPI output using Lattice CrossLink-NX FPGA
Develop kernel-level driver for zero-copy GPU memory transfer
Integrate IMU with synchronized trigger signal
Design for commercial-grade components to optimize cost for mass production
2.2 System Constraints
Available Jetson Interface: Single 2-lane MIPI CSI-2 port (other ports occupied by existing sensors)
Solution: Lattice CrossLink-NX FPGA for 4-to-1 MIPI virtual channel aggregation
Component Grade: Commercial temperature range (-10°C to +55°C) - no extreme environment requirements
2.3 Camera Specifications
Parameter
Specification
Camera Module
KLT-Z6MF-OV9281 V3.0
Sensor
OmniVision OV9281 (Global Shutter)
Resolution
1MP (1280 x 800)
Interface
MIPI CSI-2 (2-lane per camera)
Quantity
4 units
Cable Length
10-15cm (MIPI direct connection)
3. Technical Architecture
3.1 System Block Diagram
The proposed system architecture:
4x OV9281 Camera Modules → MIPI CSI-2 (2-lane each) → 
Lattice CrossLink-NX FPGA (4:1 aggregation with VC tagging) → 
Single 2-Lane MIPI CSI-2 Output → Jetson Orin NX
Hardware Trigger Generator → Simultaneous sync to all cameras + IMU
3.2 Hardware Design
PCB Design Tool: Altium Designer
3.2.1 Lattice CrossLink-NX FPGA Solution
The CrossLink-NX is selected as the mandatory aggregation solution due to single available CSI port constraint:
Device: Lattice CrossLink-NX (LIFCL-40 or LIFCL-17) - latest generation with improved performance
MIPI D-PHY: Hardened D-PHY IP supporting up to 2.5 Gbps/lane
Input Configuration: 4x CSI-2 RX interfaces (2-lane each) for camera inputs
Output Configuration: 1x CSI-2 TX interface (2-lane) to Jetson Orin NX
Virtual Channel Mapping: Camera 1→VC0, Camera 2→VC1, Camera 3→VC2, Camera 4→VC3
Sync Integration: FPGA generates precision trigger signal distributed to all cameras simultaneously
Future Expansion: FPGA can output additional sync signals for external sensors if needed in V2
3.2.2 MIPI CSI-2 Interface Design
Differential Pair Routing: 100Ω differential impedance with tight length matching (±0.1mm within pairs)
Lane Configuration: Each camera uses 2 data lanes + 1 clock lane (D0±, D1±, CLK±)
Data Rate: Up to 800 Mbps/lane per camera input
ESD Protection: Low-capacitance TVS diodes (<0.5pF) on all MIPI lines
Connectors: Commercial-grade 15-pin FPC connectors
3.2.3 Synchronization Trigger Circuit
Trigger Source: FPGA-generated precision timing signal (CrossLink-NX internal PLL)
Distribution: Low-skew buffer for simultaneous trigger to all 4 cameras and IMU
Camera Interface: OV9281 FSIN (Frame Sync Input) for external trigger mode
Skew Specification: <100ns between all trigger outputs
Frame Rate: Configurable up to 120fps
3.2.4 IMU Integration
Recommended IMU: BMI088 or ICM-42688-P (6-axis, commercial grade)
Sync Method: Same FPGA trigger pulse routed to IMU interrupt pin
Interface: SPI (up to 10 MHz)
3.2.5 Power Management
Camera Power: 1.8V/2.8V/1.2V rails (~150mW per camera)
FPGA Power: 1.0V core, 1.8V I/O, 2.5V PLL
Total Power Budget: ~2.5W for entire board
3.3 Software/Firmware Development
3.3.1 FPGA Firmware
Development Tool: Lattice Radiant Software
CSI-2 RX Controllers: 4x receivers with packet parsing and VC extraction
Frame Buffer: Internal SRAM for line buffering during aggregation
CSI-2 TX Controller: Packet reconstruction with VC tagging
Trigger Generator: Precision timing with configurable frame rate
3.3.2 Kernel Driver Architecture
V4L2 Subdevice Driver: OV9281 sensor control (exposure, gain, trigger mode)
NVCSI Integration: Interface with NVIDIA camera subsystem
VC Demultiplexing: Separate VC0-VC3 streams into /dev/video0-3
Device Tree: Custom DTS overlay for Orin NX
3.3.3 Zero-Copy GPU Memory Transfer
NvBuffer API: DMA-capable memory allocation
CUDA-EGL Interop: Direct mapping to CUDA memory without CPU copy
Buffer Queue: Triple-buffering to prevent frame drops
4. Scope of Work
Requirements Analysis: System requirements and interface specifications
Schematic Design: Complete circuit design with CrossLink-NX FPGA
PCB Layout: High-speed design with proper MIPI impedance control
Fabrication: PCB manufacturing and component procurement
Assembly: Board assembly and hardware testing
FPGA Firmware: CrossLink-NX firmware development
Kernel Driver: Linux driver and zero-copy implementation
Integration & Testing: Full system validation
Documentation: Technical documentation package
5. Deliverables
Complete schematic design files (Altium Designer)
PCB layout files with Gerber outputs
Bill of Materials (BOM)
3x Working prototype boards (assembled and tested)
FPGA firmware source code (Lattice Radiant project)
Kernel driver source code
Sample application demonstrating zero-copy GPU memory access
Technical documentation package
6. Project Timeline Options
6.1 Standard Timeline (10-12 Weeks)
Phase
Task
Duration
1
Requirements & Architecture
Week 1
2
Schematic Design
Weeks 2-3
3
PCB Layout & Review
Weeks 3-4
4
PCB Fabrication & Procurement
Weeks 5-6
5
Assembly & Hardware Testing
Week 7
6
FPGA Firmware + Kernel Driver
Weeks 7-9
7
Integration & Testing
Weeks 10-11
8
Documentation & Delivery
Week 12
6.2 Expedited Timeline (4-5 Weeks)
Accelerated delivery with dedicated priority focus:
Phase
Task
Duration
1
Requirements + Schematic (parallel)
Days 1-5
2
PCB Layout (expedited review)
Days 6-10
3
PCB Fab (express) + FPGA dev (parallel)
Days 11-18
4
Assembly + Driver dev (parallel)
Days 19-25
5
Integration, Testing & Delivery
Days 26-35
Expedited option includes: Express PCB fabrication, parallel development tracks, dedicated priority scheduling, daily progress updates.
7. Budget Estimate
7.1 Development Cost (NRE)
Item
Standard
Expedited
Hardware Design (Schematic + PCB)
$6,000
$10,800
PCB Fabrication (3 boards)
$800
$1,800
Components & Assembly (3 units)
$1,500
$2,200
FPGA Firmware Development
$3,000
$4,800
Kernel Driver & Software
$2,500
$3,800
Integration, Testing & Docs
$1,200
$1,800
TOTAL NRE
$15,000
$25,200
7.2 Mass Production Cost Estimate (Per Board, Excluding Cameras)
Production Volume
Estimated Unit Cost
Prototype (5 units)
~$400/unit
Small batch (10-50 units)
~$150-200/unit
Medium volume (100-500 units)
~$100-120/unit
High volume (1000+ units)
$70-90/unit
Note: Mass production estimates based on commercial-grade components, China-based manufacturing partners. Final pricing depends on component availability and exact BOM. Camera modules (KLT-Z6MF-OV9281) and Jetson Orin NX not included.
8. Assumptions & Clarifications
Single 2-lane MIPI CSI-2 port available on Jetson (CrossLink-NX aggregation required)
Camera-to-board distance: 10-15cm (MIPI direct, no serializer needed)
Commercial-grade components (-10°C to +55°C operating range)
Client provides camera modules and Jetson Orin NX for development
IMU selection finalized during requirements phase
No display output - GPU memory processing for computer vision
Future V2 may include additional sync outputs for external sensors
9. Payment Terms
30% upon project kickoff
30% upon schematic and PCB design approval
40% upon final delivery and acceptance
10. Contact Information
Umit Kayacik
Senior Electronics Engineer
I look forward to working with you on this project. Please don't hesitate to reach out if you have any questions or require additional information.

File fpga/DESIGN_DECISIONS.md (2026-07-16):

# Chronos FPGA - Design Decisions (rebuild)

Decisions locked for the MIPI subsystem rebuild. See `.cursor/plans/chronos_mipi_rebuild_*.plan.md`.

## Sensor / data point
- Sensor: SincereFirst SF-AOV9281 (OV9281 CSP). 1280x800, 10-bit RAW mono, 2 data lanes.
  Connector AXT624124 mates the board AXT524124 socket DIRECTLY (no adapter); FSIN on
  conn pin 16, RESET on pin 21, SCCB/IO at 1.8 V. See docs/sf_aov9281_direct_connect.md.
- XCLK = 27 MHz, GENERATED BY THE FPGA: oscillator X2 -> FPGA L5 (clk_27m), forwarded to
  cam_mclk[3:0] on M3..M6 -> J3..J6 pin 19 (netlist). The module has no oscillator; no
  MCLK => no SCCB response. The OV9281 PLL init must target a 27 MHz input (not 24 MHz).
- SCCB address per port (SID strap, netlist): cam0/2 = 0x60 (SID=GND), cam1/3 = 0x10
  (SID pulled to VCCIO6). chronos_top sets DEV_ADDR per ov9281_init instance.
- Link rate: 800 Mbps/lane (GEAR=8 -> byte clock 100 MHz). Confirmed by datasheet (up to 120fps).
- Design fps target: CONFIRMED 30 fps per camera (4 cams @ 30 fps). Comfortable on the 2-lane TX
  (~1.6 Gbps aggregate, see bandwidth note). The RTL is rate-agnostic; the ceiling is the 2-lane TX,
  not the fabric.
- Frame rate is set by the FPGA FSIN trigger, NOT by the sensor free-running. All 4 cameras run in
  external-trigger (slave) mode and expose on each FSIN pulse, so the FPGA's trigger period defines the
  synchronized 30 fps. Defaults are wired for this:
    * `config_regs` powers up `frame_rate = 30` (REG 0x01) and `pulse_width = 2000` cyc (~10.4 us @192 MHz).
    * `trigger_generator` resets to 30 fps. Rate engine is a PHASE ACCUMULATOR (adds fps per clk, fires
      on wrap of CLK_FREQ_HZ) - exact average rate, no runtime divider. Single physical FSIN pin
      (R9) fanned out on the PCB to all cameras + IMU + sync header.

## System clock (12 MHz ref -> PLL)
- clk_sys = 192 MHz, NOT 200: with FEEDBK_PATH=CLKOP the CLKOP frequency must be an integer
  multiple of the 12 MHz phase-detector frequency, and 200/12 is not an integer (dividing the PD
  below 10 MHz is out of spec). 192 = 12 x 16; VCO = 192 x 6 = 1152 MHz (in the 800-1600 range).
  The original CLKFB_DIV=50/CLKOP_DIV=3 set implied VCO=1800 MHz - the PLL could never lock.
- Everything that counts cycles is parameterized: trigger_generator/ov9281_init/i2c_master take
  CLK_HZ=192_000_000 from chronos_top; csi2_tx REF_CLOCK_FREQ=192 (regenerate D-PHY TX CM/CN/CO
  for a 192 MHz CLKREF in the IP Catalog).
  => 30 fps needs no RTL change; the OV9281 init table just has to put the sensor in external-trigger
  mode with VTS large enough for the 30 fps exposure window.

## Bandwidth ceiling (hard limit)
- Input at 120fps: 4 x 2 lanes x 800 Mbps = 6.4 Gbps.
- TX to Jetson = 2 lanes; D-PHY ~2.5 Gbps/lane => ~5 Gbps ceiling.
- => 4 cams @ 120fps simultaneously does NOT fit a 2-lane TX. Chosen design point 4 cams @ 30 fps
  (~1.6 Gbps total) sits comfortably below the ceiling with ample margin. Not a firmware bug; a physical
  link limit that the 30 fps target avoids entirely.

## D-PHY allocation (2 hard blocks available)
- Cameras (4x RX): SOFT MIPI D-PHY (lscc_mipi_dphy_soft_rx, GDDR/ECLK based). Uniform, no hard-DPHY
  scarcity. 800 Mbps/lane, GEAR=8.
- TX to Jetson (1x): HARD MIPI D-PHY (lscc DPHY primitive). Highest, most timing-critical link.
- Leaves 1 hard D-PHY spare.
- ACTION (hardware): confirm camera pin pairs are on soft-DPHY-capable (true LVDS/generic-DDR) banks
  and the TX pair on a hard-DPHY site, against the LIFCL-40 datasheet. The PDC currently tags all as
  MIPI_DPHY (hard); soft camera lanes must use the soft I/O type the IP emits (LVDS + IDDRX4).

## Camera configuration ownership
- FPGA-driven OV9281 init over per-camera SCCB (I2C master in fabric), triggered after cam reset release.
- Rationale: each camera has its own dedicated I2C bus to the FPGA (cam_scl/sda[3:0]); the Jetson host
  bus is separate (host_i2c). FPGA owning camera init keeps cameras streaming independent of host driver
  bring-up. Init table lives in `ov9281_init_rom` (editable).

## Word alignment (soft RX)
- The soft RX IP does not provide SoT/byte-enable; IDDRX4 ALIGNWD is tied low. Therefore fabric must do
  per-lane byte alignment by detecting the CSI-2 sync byte 0xB8 across bit offsets, then lock the offset.
  Implemented in `csi2_rx` / `dphy_word_aligner`.

## Toolchain note
- Build in Radiant 2.0 SP1 (ES silicon). The design is SystemVerilog; use Synplify Pro synthesis in
  Radiant 2.0 SP1 (LSE in 2.0 SP1 lacks full SV). The Lattice MIPI IP RTL is Verilog and works with both.

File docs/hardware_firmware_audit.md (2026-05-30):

# Chronos R1 — Hardware vs. Firmware Audit

This document is the result of a deep, schematic-driven review of the
`HW_CHRONOS_R1` board against the firmware/driver/application source tree.
It records both the **board facts** (extracted from `hardware/Chronos.net`,
the Altium netlist) and the **firmware deviations** that were found and
fixed.

The intent is that anyone bringing the board up — synth-fitting the FPGA,
flashing JetPack, or wiring host code — has a single sheet of paper that
maps every important hardware net to the corresponding piece of source.

---

## 1. Board summary (HW_CHRONOS_R1)

| Block | Reference designator | Part number | Notes |
|---|---|---|---|
| FPGA aggregator | **U3** | **Lattice LIFCL-40 BG400** (`LIFCL-40-BG400`) | 40 k LUT, 5 MIPI D-PHY pairs available, single 12 MHz reference clock route through JP2 |
| IMU | **IC1** | **TDK InvenSense ICM-42688-P** | 14-pin LGA, SPI 4-wire, 1.8 V VDD/VDDIO, FSYNC tagged |
| USB bridge | U1 | FTDI FT2232HL | Provides JTAG (ch A) + UART (ch B) toward FPGA; X1 = 12 MHz crystal |
| Config flash | U6 | Macronix MX25L12833F | 16 MiB SPI NOR for FPGA bitstream |
| Quad buffer | U5 | TI SN74LVC125A | Quad 3-state, used to fan FSIN out to four cameras |
| Dual buffer | U9 | TI SN74LVC2G125 | Fans FSIN out to IMU + external sync header |
| Cam connectors | J3..J6 | Panasonic AXT524124 | 24-pin board-to-board, one per camera |
| Jetson CSI FFC | J7 | Hirose FH12-22S-0.5SH | 22-pin, 2-lane MIPI + sideband |
| Ext-sync header | P1 | Würth 620003111 21 | 3-pin, accepts external FSIN |
| Crystals | X2..X5 | 27 MHz, ASE3-27.000 | **One per camera, drives the camera's own MCLK directly — NOT routed to the FPGA** |
| Power rails on board | — | LT3508 ×2, NCP110AMX280, NCP110AMX120, TLV73310, BD00IC0WHFV | Generates +12V, +5V, +3V3, +2V8, +1V8, +1V8 LDO, +1V2, +1V0 LDO, +1V0 FPGA core |

### Critical signal map (FPGA U3 ⇄ board)

Derived directly from the netlist `Chronos.net`.

| Function | FPGA pin | Net |
|---|---|---|
| 12 MHz reference (FT_OSCO → JP2 → FPGA) | **L13** | `12MHZ` |
| Global reset / SW4 button | **G19** | `GSRN` |
| Camera-0 MIPI clock pair | **A2 / B1** | `CAM0_CLK_P / CAM0_CLK_N` |
| Camera-0 MIPI D0 pair | **B2 / C1** | `CAM0_0_P / CAM0_0_N` |
| Camera-0 MIPI D1 pair | **A3 / B3** | `CAM0_1_P / CAM0_1_N` |
| Camera-1 MIPI clock pair | **W11 / Y11** | `CAM1_CLK_P / CAM1_CLK_N` |
| Camera-1 MIPI D0 pair | **V11 / U11** | `CAM1_0_P / CAM1_0_N` |
| Camera-1 MIPI D1 pair | **W13 / V12** | `CAM1_1_P / CAM1_1_N` |
| Camera-2 MIPI clock pair | **A8 / B8** | `CAM2_CLK_P / CAM2_CLK_N` |
| Camera-2 MIPI D0 pair | **A7 / B7** | `CAM2_0_P / CAM2_0_N` |
| Camera-2 MIPI D1 pair | **A9 / B9** | `CAM2_1_P / CAM2_1_N` |
| Camera-3 MIPI clock pair | **T13 / T14** | `CAM3_CLK_P / CAM3_CLK_N` |
| Camera-3 MIPI D0 pair | **Y15 / Y16** | `CAM3_0_P / CAM3_0_N` |
| Camera-3 MIPI D1 pair | **U15 / V16** | `CAM3_1_P / CAM3_1_N` |
| CSI-2 TX clock pair (Jetson) | **T6 / U6** | `CSI_TX_CLK_P / CSI_TX_CLK_N` |
| CSI-2 TX D0 pair | **R7 / T7** | `CSI_TX_D0_P / CSI_TX_D0_N` |
| CSI-2 TX D1 pair | **V6 / U7** | `CSI_TX_D1_P / CSI_TX_D1_N` |
| FSIN out (single, feeds U5+U9) | **R9** | `FSIN_FPGA` |
| CAM_RESET (shared all 4 cams) | **W18** | `CAM_RESET` |
| Cam-0 I²C (SDA / SCL) | **N4 / N5** | `CAM0_SDA / CAM0_SCL` |
| Cam-1 I²C (SDA / SCL) | **P5 / P6** | `CAM1_SDA / CAM1_SCL` |
| Cam-2 I²C (SDA / SCL) | **P1 / P2** | `CAM2_SDA / CAM2_SCL` |
| Cam-3 I²C (SDA / SCL) | **N6 / N7** | `CAM3_SDA / CAM3_SCL` |
| Host config I²C (Jetson side) | **G14 / G15** | `I2C_CON_SDA / I2C_CON_SCL` |
| IMU SPI CS / SCLK | **R8 / P8** | `IMU_CS / IMU_SCLK` |
| IMU SPI MISO / MOSI | **T8 / P7** | `IMU_MISO / IMU_MOSI` |
| IMU INT1 (DRDY) | **Y7** | `IMU_INT1` |
| LED0..LED3 | **E17 / F13 / G13 / F14** | `LED0..LED3` |
| Debug UART RX / TX | **F18 / F16** | `RXD_UART / TXD_UART` |

Camera connector pinout (per AXT524124, identical on J3–J6):

```
1  SDA (per-cam I2C)
2  SCL (per-cam I2C)
3  VCCIO5  (cam I/O power, supplies the 27 MHz xtal too)
4  CAM_CLK_P    \  MIPI clock pair
5  CAM_CLK_N    /
6,9,12,17,24..28  GND
7  CAM_D0_P     \  MIPI data lane 0
8  CAM_D0_N     /
10 CAM_D1_P     \  MIPI data lane 1
11 CAM_D1_N     /
15 1V8 (via ferrite FBx, separate per camera)
16 FSIN (from external buffer U5)
18 V1P2  (camera DVDD)
19 MCLK  (27 MHz, dedicated on-board crystal)
21 CAM_RESET (shared with all 4 cameras)
22 V2P8  (camera AVDD)
```

---

## 2. Findings & fixes

### 🔴 Critical mismatches (firmware would not have worked as-is)

| # | What was wrong | Where | Why it matters | Fix |
|---|---|---|---|---|
| 1 | FPGA pinout constraints used placeholder sites (`A2/A3`, `D2/D3`, … `M3`, `L5`, …) | `fpga/constraints/chronos_pinout.pdc` | Bitstream would have shorted MIPI nets, lost the JP2 12 MHz route, missed the GSR pin, and used non-DPHY-capable sites. | Rewrote PDC with the actual `LIFCL-40-BG400` sites taken from the netlist (see Section 1). |
| 2 | IMU driver was for **Bosch BMI088** but the board has **TDK ICM-42688-P** (different die, different SPI command set, different number of CS lines) | `drivers/imu/bmi088_chronos.c` | Driver would have failed WHO_AM_I, attempted writes to the wrong addresses, and never produced samples. | Replaced with `drivers/imu/icm42688_chronos.c` — full IIO driver with FSYNC tagging, INT1 IRQ, proper scales, and a sync-count sysfs surface for the user-space lib. |
| 3 | Device tree referenced `bosch,bmi088`, declared a single `ov9281@60`, and described a synthetic 24 MHz `chronos_clk` driving every camera's `xvclk` | `drivers/chronos-orin-nx.dts` | Wrong compatible string → no driver bound. Single sensor node → other three cameras invisible. The cameras get MCLK from their own 27 MHz crystals; the kernel does not drive the clock at all. | Rewrote DTS: four `ov9281` nodes under an FPGA `i2c-mux`, ICM-42688-P SPI node with INT1 mapped to GPIO-H-6, virtual 27 MHz fixed-clock provider, proper `tegra-camera-platform` modules list. |
| 4 | `chronos_top.sv` exposed **four** separate `cam_trigger[3:0]` pins and a fifth `imu_trigger` | `fpga/rtl/chronos_top.sv` | The board only routes **one** FSIN pin from the FPGA (`R9`) which is fanned out by external buffers `U5`/`U9`. Five outputs cannot be assigned because the sites don't exist on the board. | Single `fsin_fpga` port; instances of `cam_trigger`/`imu_trigger` removed and the on-board buffer chain documented. |
| 5 | `config_regs` had ports for `pulse_width`, `trigger_delay [4]`, `soft_reset`, `cam_enable`, `output_data_type`, `cam_sync_status`, `frame_count [4]` that were left **unconnected** in `chronos_top.sv` | `chronos_top.sv` ↔ `config_regs.sv` | Elaboration would have failed (or required black-box overrides); the host-visible register bank would have been functionally read-only. | All ports wired in `chronos_top.sv`. Frame counters now increment on each `frame_start` per camera; `cam_sync_status[i]` is asserted when there is no current RX/overflow error. |
| 6 | `trigger_generator` declared `trigger_delay[4]` while the generate loop iterated `i = 0 .. NUM_OUTPUTS-1` with `NUM_OUTPUTS = 5` | `fpga/rtl/trigger_generator.sv` | Out-of-bounds array access, undefined synthesis result. | Array sized by the `NUM_OUTPUTS` parameter; loop and connections rewritten. |
| 7 | `trigger_generator`'s "delayed trigger" logic deasserted the output mid-pulse if `trigger_delay > 0` | same | Cameras would have received pulses shorter than the configured width, breaking the OV9281's minimum-FSIN-width spec. | Replaced delay-counter scheme with a `DELAY_SR_DEPTH`-deep shift register fed by the master pulse — pulse width preserved by construction. |
| 8 | `chronos_pll.sv` synthesised to `clk_200m = clk_ref` and `clk_byte = clk_ref` (placeholder) | `fpga/rtl/chronos_pll.sv` | All "200 MHz" logic, CSI byte clock, and frame-period math would have run at the 25 MHz (assumed) input rate; in reality the reference is **12 MHz**. | Instantiated `PLL_CORE` with `CLKI_DIV=1`, `CLKFB_DIV=50`, `CLKOP_DIV=3`, `CLKOS_DIV=6` → 200 MHz / 100 MHz. Simulation path generates the same rates behaviourally. |

### 🟠 High-impact bugs

| # | What was wrong | Where | Fix |
|---|---|---|---|
| 9 | `chronos_configure()` was a `TODO` — nothing was ever pushed to the FPGA | `app/src/chronos_capture.c` | Implemented `push_config_to_fpga()` that talks to `/dev/i2c-1` (configurable) and writes `FRAME_RATE`, `PULSE_WIDTH_{L,H}`, `CAM_ENABLE`, `DATA_TYPE`, and per-camera `TRIG_DELAY_x`. Also pokes per-sensor `V4L2_CID_EXPOSURE`. |
| 10 | Capture thread's `select()` referenced `cam->fd` even for cameras that failed to open (fd = 0) and re-queued the wrong buffer indices | `chronos_capture.c` (`capture_thread_func`) | Active-camera count tracked at thread start; re-queue uses the exact indices that were dequeued this iteration. |
| 11 | IMU sysfs reader used `atoi()` (cannot parse negative numbers) and hard-coded scales | `chronos_capture.c` (`read_imu_data`) | Reworked to `strtol` + read `in_*_scale` from sysfs; also pulls `sync_count` / `last_sync_time` attrs from the new ICM-42688 driver. |
| 12 | Kernel driver disabled the FPGA trigger when VC0 stopped streaming, regardless of whether VC1..VC3 were still active (and only enabled it when VC0 started) | `drivers/chronos_csi/chronos_csi.c` | `chronos_count_streaming()` helper; trigger gated on "any channel streaming". Also down-graded the `i2c_client == NULL` path to an info-level message because the user-space lib already programs the FPGA. |

### 🟡 Smaller cleanups

* All `Makefile` references to BMI088 retargeted to the ICM-42688 module (`CONFIG_IIO_ICM42688_CHRONOS`).
* Removed the dangling `gpio-hog` entry that pinned `H,3` low forever (the cameras' shared reset is owned by the FPGA, not by a Jetson GPIO).
* `chronos_top.sv` now also exposes the debug UART, host I²C, per-camera I²C, IMU SPI, and `cam_resetn` ports so the constraint file's nets actually resolve.

### 🟢 Things that were already fine

* OV9281 V4L2 subdev driver (`drivers/ov9281/ov9281.c`) — register map, mode table, controls, and PM ops are correct for the OV9281 datasheet. The only behavioural concern is the lack of `reset-gpios` (now intentional — there's no per-camera reset to bind to), which is handled by the FPGA.
* CSI-2 RX/TX RTL is a behavioural skeleton, but is consistent across `csi2_rx.sv`, `csi2_tx.sv`, `frame_buffer.sv`, `tx_arbiter.sv`, and `i2c_slave.sv` — they all share a common 32-bit packet interface. The hardened D-PHY hard-IP still has to be instantiated through Lattice Radiant's IP catalog; the wrappers (`dphy_rx_wrapper`, `dphy_tx_wrapper`) leave the right hooks.

---

## 3. Bring-up checklist (post-fix)

1. **JP2 jumper installed** so 12 MHz from FT_OSCO reaches FPGA pin L13.
2. **FPGA bit-stream** built with the new `chronos_pinout.pdc`; PLL primitive
   wired exactly as in `chronos_pll.sv`.
3. **JTAG via FT2232HL** — flash `Chronos.bit` into `U6` (MX25L12833F);
   first power-cycle should leave `LED0` (PLL locked) lit within ~1 ms.
4. **Jetson Orin NX** boots JetPack 5.x. Build & load drivers:
   ```bash
   sudo make -C drivers/ov9281
   sudo make -C drivers/chronos_csi
   sudo make -C drivers/imu
   sudo cp drivers/chronos-orin-nx.dtbo /boot/dtb/overlays/
   sudo modprobe ov9281 chronos-csi icm42688-chronos
   ```
5. **Sanity over I²C-2** (default bus on the Jetson devkit):
   ```bash
   i2cdump -y 1 0x3C b
   ```
   Should expose firmware version `0x10`, device ID `0xC405` at `0xFE/0xFF`.
6. **Sensors over the FPGA I²C-mux** — each `/dev/i2c-N` child should show
   `ov9281` at address `0x60`. WHO_AM_I returns `0x9281`.
7. **IMU** — `cat /sys/bus/iio/devices/iio:device0/name` →
   `icm42688-chronos`. `dmesg` should show `ICM-42688-P detected
   (WHO_AM_I=0x47)`.
8. **Streaming**:
   ```bash
   chronos_demo --rate 60 --exposure 5000
   sync_test  -n 1000 -r 120
   ```
   `sync_test` exercises the `<100 ns` skew claim end-to-end.

---

## 4. Remaining work (not part of this fix-up pass)

The items below are needed for *full* functional bring-up but are outside
the scope of a hardware/firmware reconciliation; they are flagged here so
they don't get lost.

1. **CSI-2 D-PHY hard IP** — instantiate `DPHY` / `DPHY_RX` / `DPHY_TX`
   atoms from Radiant's IP catalog inside `dphy_rx_wrapper` and
   `dphy_tx_wrapper`. The current files are deliberate behavioural stubs.
2. **Per-camera FPGA I²C master cores** — the design currently tri-states
   the four camera I²C buses; the Jetson speaks to the cameras over those
   buses through the FPGA. A small I²C master (4 instances) selected by
   the host-side register bank is required.
3. **NVCSI/VI integration** — `chronos_csi.c` currently exposes four
   `videoX` nodes but has no DMA path to NVCSI. The right path on Orin is
   either tegracam plumbing (V4L2 sub-device with NVCSI underneath) or a
   custom kernel module that programs `vi5` channels directly with the
   four virtual channels demultiplexed.
4. **Bitstream-time `output_data_type` register** is currently exposed in
   the register bank but unused; pipe it into `csi2_tx.sv`'s packet
   builder so the host can switch between RAW8/RAW10/RAW12.
5. **CAM_RESET timing** — `chronos_top.sv` toggles the shared reset on
   `soft_reset`, but the OV9281 datasheet wants `t_reset >= 1 ms`. The
   200 MHz timer in this file is way too short (256 cycles = 1.28 µs).
   Either widen the counter or pull the reset signal high through a
   millisecond-scale debouncer before deassertion.

---

*This audit was produced on 2026-05-16 using only the files in this
repository — no live measurements taken.  Anything that does not match a
populated board should be verified against the schematic PDF
(`hardware/sch.pdf` / `Schematic/HW_CHRONOS_R1.PDF`).*

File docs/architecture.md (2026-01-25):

# Chronos System Architecture

## Overview

Chronos is a multi-camera MIPI synchronization system designed for the NVIDIA Jetson Orin NX platform. It synchronizes four OV9281 global shutter cameras and an IMU, delivering synchronized frames directly to GPU memory for computer vision applications.

## System Block Diagram

```
┌─────────────┐  ┌─────────────┐  ┌─────────────┐  ┌─────────────┐
│  OV9281 #0  │  │  OV9281 #1  │  │  OV9281 #2  │  │  OV9281 #3  │
│  (Camera)   │  │  (Camera)   │  │  (Camera)   │  │  (Camera)   │
└──────┬──────┘  └──────┬──────┘  └──────┬──────┘  └──────┬──────┘
       │ CSI-2          │ CSI-2          │ CSI-2          │ CSI-2
       │ 2-lane         │ 2-lane         │ 2-lane         │ 2-lane
       ▼                ▼                ▼                ▼
┌──────────────────────────────────────────────────────────────────┐
│                    CrossLink-NX FPGA                              │
│  ┌──────────┐  ┌──────────┐  ┌──────────┐  ┌──────────┐          │
│  │ CSI-2 RX │  │ CSI-2 RX │  │ CSI-2 RX │  │ CSI-2 RX │          │
│  │   VC0    │  │   VC1    │  │   VC2    │  │   VC3    │          │
│  └────┬─────┘  └────┬─────┘  └────┬─────┘  └────┬─────┘          │
│       │             │             │             │                 │
│       └─────────────┴──────┬──────┴─────────────┘                 │
│                            │                                       │
│                    ┌───────▼───────┐      ┌─────────────────┐     │
│                    │ Frame Buffer  │      │ Trigger Gen     │     │
│                    │   (SRAM)      │      │ (PLL-based)     │     │
│                    └───────┬───────┘      └────────┬────────┘     │
│                            │                       │               │
│                    ┌───────▼───────┐               │               │
│                    │  TX Arbiter   │◄──────────────┘               │
│                    │ (VC Tagging)  │                               │
│                    └───────┬───────┘                               │
│                            │                                       │
│                    ┌───────▼───────┐                               │
│                    │   CSI-2 TX    │                               │
│                    │   (2-lane)    │                               │
│                    └───────┬───────┘                               │
└────────────────────────────┼───────────────────────────────────────┘
                             │ CSI-2 2-lane
                             │ (4 Virtual Channels)
                             ▼
┌──────────────────────────────────────────────────────────────────┐
│                     Jetson Orin NX                                │
│                                                                   │
│  ┌─────────────┐    ┌─────────────┐    ┌─────────────────────┐  │
│  │   NVCSI     │───▶│ VI (Video   │───▶│ Chronos CSI Driver  │  │
│  │  (D-PHY)    │    │   Input)    │    │ (VC Demux)          │  │
│  └─────────────┘    └─────────────┘    └─────────┬───────────┘  │
│                                                   │              │
│        ┌──────────────────────────────────────────┼───────────┐  │
│        │                                          ▼           │  │
│        │  ┌───────────┐  ┌───────────┐  ┌───────────────────┐│  │
│        │  │/dev/video0│  │/dev/video1│  │   NvBuffer Pool   ││  │
│        │  │/dev/video1│  │/dev/video2│  │   (DMA-capable)   ││  │
│        │  │/dev/video2│  │/dev/video3│  └─────────┬─────────┘│  │
│        │  │/dev/video3│  │           │            │          │  │
│        │  └───────────┘  └───────────┘            ▼          │  │
│        │                               ┌───────────────────┐ │  │
│        │                               │ CUDA-EGL Interop  │ │  │
│        │                               │ (Zero-Copy)       │ │  │
│        │                               └─────────┬─────────┘ │  │
│        │                                         ▼           │  │
│        │                               ┌───────────────────┐ │  │
│        │                               │    GPU Memory     │ │  │
│        │                               │ (CUDA Processing) │ │  │
│        │                               └───────────────────┘ │  │
│        └─────────────────────────────────────────────────────┘  │
└──────────────────────────────────────────────────────────────────┘

Trigger Signal Distribution:
┌─────────────────────────────────────────────────────────────────┐
│                           FPGA                                   │
│  ┌──────────────┐                                               │
│  │   PLL-based  │──────┬──────┬──────┬──────┬──────────────────▶│ FSIN
│  │   Trigger    │      │      │      │      │                    │ to Cam0
│  │   Generator  │      │      │      │      │                    │
│  └──────────────┘      │      │      │      └──────────────────▶│ FSIN
│                        │      │      │                           │ to Cam1
│                        │      │      └─────────────────────────▶│ FSIN
│                        │      │                                  │ to Cam2
│                        │      └────────────────────────────────▶│ FSIN
│                        │                                         │ to Cam3
│                        └───────────────────────────────────────▶│ INT
│                                                                  │ to IMU
└──────────────────────────────────────────────────────────────────┘
```

## Component Details

### 1. FPGA Firmware (Lattice CrossLink-NX)

**Purpose**: Aggregate 4 camera streams into a single 2-lane MIPI CSI-2 output using virtual channel multiplexing.

**Key Modules**:
- `csi2_rx.sv` - 4x CSI-2 receivers with D-PHY interface
- `frame_buffer.sv` - SRAM-based line buffers for stream aggregation
- `tx_arbiter.sv` - Round-robin arbitration with VC tagging
- `csi2_tx.sv` - CSI-2 transmitter with packet reconstruction
- `trigger_generator.sv` - PLL-based precision trigger (<100ns skew)
- `config_regs.sv` - I2C-accessible configuration registers

**Data Flow**:
1. Each camera sends 2-lane MIPI CSI-2 to its dedicated RX
2. Packets are parsed and stored in line buffers
3. TX arbiter reads from buffers in round-robin order
4. Virtual channel tag is added (Camera N → VC N)
5. Single 2-lane output stream sent to Jetson

### 2. Linux Kernel Drivers

**OV9281 Driver** (`drivers/ov9281/ov9281.c`):
- V4L2 subdevice driver for sensor control
- Exposure and gain adjustment via I2C
- External trigger mode (FSIN) support
- Power management

**Chronos CSI Driver** (`drivers/chronos_csi/chronos_csi.c`):
- Platform driver for multi-camera management
- Virtual channel demultiplexing
- Creates `/dev/video0-3` for each camera
- DMA-BUF buffer management

**BMI088 IMU Driver** (`drivers/imu/bmi088_chronos.c`):
- IIO subsystem driver
- SPI communication at 10MHz
- Synchronized interrupt handling
- Timestamp correlation with camera frames

### 3. Zero-Copy GPU Memory Pipeline

**NvBuffer Integration**:
- Hardware-accelerated buffer management
- DMA-capable memory allocation
- Direct path from VI to GPU memory

**CUDA-EGL Interop**:
- EGLImage creation from DMA-BUF
- CUDA external memory import
- Zero CPU copy path

**Triple Buffering**:
- Prevents frame drops under load
- Producer-consumer synchronization
- Automatic buffer recycling

## Synchronization Architecture

### Trigger Distribution
- FPGA PLL generates master clock
- Configurable frame rate (1-120 fps)
- Sub-100ns skew between all outputs
- Simultaneous trigger to all cameras and IMU

### Timestamp Correlation
1. FPGA sends trigger pulse
2. Cameras capture on rising edge (FSIN)
3. IMU samples on same edge (interrupt)
4. All devices share same timestamp reference
5. Software verifies sync by comparing timestamps

## Memory Map

### FPGA Register Map (I2C Address 0x3C)

| Address | Name | Description |
|---|---|---|
| 0x00 | CTRL | Control register (enable, reset) |
| 0x01 | FRAME_RATE | Target frame rate (1-120) |
| 0x02-03 | PULSE_WIDTH | Trigger pulse width |
| 0x04 | CAM_ENABLE | Camera enable mask |
| 0x10-13 | TRIG_DELAY | Per-camera trigger delay |
| 0x20 | STATUS | PLL lock, sync status |
| 0x21 | ERROR | Error flags |
| 0x30-37 | FRAME_CNT | Per-camera frame counters |
| 0xF0 | VERSION | Firmware version |
| 0xFE-FF | DEVICE_ID | Device identification |

## Performance Specifications

| Parameter | Specification |
|---|---|
| Frame Rate | Up to 120 fps |
| Resolution | 1280 x 800 per camera |
| Bit Depth | 10-bit (RAW10) |
| Sync Accuracy | < 100 ns inter-camera skew |
| Latency | < 5 ms capture-to-GPU |
| Throughput | ~1.2 Gbps aggregate |
| Power | ~2.5W total board power |

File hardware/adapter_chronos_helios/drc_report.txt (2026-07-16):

** Drc report for chronos_helios_adapter.kicad_pcb **
** Created on 2026-07-16T15:18:19 **
** Report includes: Errors **

** Found 0 DRC violations **

** Found 0 unconnected pads **

** Found 0 Footprint errors **

** Ignored checks **
    - Footprint has no courtyard defined
    - Track endpoint not centered on via
    - Tuning profile track geometries
    - Footprint doesn't match symbol's footprint filters
    - Footprint component type doesn't match footprint pads

** End of Report **

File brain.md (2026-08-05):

# CHRONOS — Project Brain (full handoff document)

> Self-contained knowledge base for continuing this project in any IDE / with any
> AI assistant. Read this first. Companion file: `CLAUDE.md` (older memory doc,
> mostly overlapping). Last updated: 2026-08-05, git HEAD `afc7d91`.

---

## 0. What this project is

**Chronos** = custom board (HW_CHRONOS_R1) that aggregates **4x MIPI CSI-2
cameras into one synchronized 2-lane CSI-2 stream** for an NVIDIA **Jetson Orin
NX**, using a **Lattice CrossLink-NX (LIFCL-40) FPGA**. The FPGA:

- receives 4x 2-lane CSI-2 (soft D-PHY RX, one per camera),
- buffers packets per camera and multiplexes them onto one 2-lane CSI-2 TX
  (hard D-PHY) using **virtual channels 0..3**,
- generates a common **FSIN trigger** so all 4 sensors expose simultaneously,
- configures the sensors itself over SCCB/I2C at boot,
- is controlled by the Jetson over I2C (slave addr **0x3C**).

Target: 4 cameras @ **30 fps** aggregate (bandwidth ceiling of the 2-lane TX
makes 4x120fps impossible — see §5.6).

The Jetson sits on an **Aerium "Helios" carrier board**; Chronos connects to the
Helios CAM1 port through a **custom adapter PCB** (see §7 — pinouts are
incompatible, a direct cable would short 3.3V to GND).

### Current overall status (2026-08)

| Area | Status |
|---|---|
| Board bring-up / programming path | PROVEN (blinky runs from SPI flash) |
| FPGA RTL (fpga/rtl/) | Complete after 2 deep reviews; 3 testbenches PASS in Icarus; **not yet synthesized for hardware** (2 placeholders remain, §5.4) |
| Jetson kernel drivers (drivers/) | Rewritten to real architecture; **never compiled** (needs L4T tree) |
| Jetson userspace (app/) | Rewritten (V4L2 MMAP); **never compiled** (needs Jetson) |
| Adapter PCB (hardware/adapter_chronos_helios/) | v3 design DONE, DRC clean, JLC-ready, **not yet ordered** |
| Cameras | 1x SF-AOV9281 in hand, plugged into J3 (CAM0) |

---

## 1. Hardware facts (netlist-verified, do not re-derive)

Netlist source of truth: `hardware/Project Outputs for Chronos/ProtelNetlist/Chronos.NET`.
Always check pin sites there before touching the PDC.

- **FPGA**: U3, marking `LIFCL-40-8BG400C`, CABGA400. **The silicon is ES1**:
  JTAG/SSPI IDCODE = `0x010F1043` (production = `0x110F1043`). The marking lies;
  trust the IDCODE. This cost weeks — see §3.
- **Config flash**: U6 = Macronix **MX25L12833F** 128 Mbit SPI NOR, on FPGA MSPI
  pins (DQ0→D13, DQ1→D15, DQ2→D14, DQ3→D16). J20 breaks out quad-SPI.
- **USB bridge**: FT2232HL wired to FPGA **Slave SPI (SSPI), not JTAG**.
  Channel A = SSPI/config, channel B = UART.
- **Programming jumpers**: JP1 **open**; config-enable jumper fitted → D17 red.
  JP2 closed feeds the 12 MHz reference (FT2232) to FPGA pin **L13**.
- **Buttons**: SW4 = GSRN (active-low reset), SW5 = PROGRAMN.
- **Cameras**: 4x SincereFirst **SF-AOV9281** (OV9281, 1280x800 RAW10 mono,
  2-lane) on J3..J6 (AXT524124 socket — module plugs directly, no adapter).
  - **No oscillator on module.** 27 MHz osc X2 → FPGA **L5** (`clk_27m`); FPGA
    forwards to `cam_mclk[3:0]` = **M3/M4/M5/M6** → J3..J6 pin 19.
    No MCLK = no SCCB = dead camera.
  - **SID strap differs per port**: J3/J5 → SCCB addr **0x60**; J4/J6 → **0x10**.
    Each camera has a dedicated I2C bus; `chronos_top` sets DEV_ADDR per instance.
  - Rails: pin3 = V1P8 (DOVDD), pin18 = V1P2 (DVDD), pin22 = V2P8 (AVDD).
  - FSIN: FPGA **R9** → U5/U9 buffers → J3..J6 pin 16. RESET: FPGA **W18** →
    all J*-21, shared, active-low.
- **IMU**: ICM-42688-P (IC1) on FPGA SPI (NOT wired to the Jetson).
- **User LEDs** LED0..3 = E17/F13/G13/F14, **ACTIVE-LOW** (FPGA sinks cathode).
- **Bank 1 (VCCIO1) is 3.3 V** → PDC uses LVCMOS33 for UART/host-I2C/LEDs/GSRN.
- **Host I2C** (Jetson→FPGA): FPGA slave addr **0x3C**.
- **J7** = 22-pin 0.5 mm FFC (FH12-style, bottom-contact) = the aggregated
  CSI-2 TX output toward the Jetson. **Custom pinout** (see §7).

---

## 2. Toolchain

- **Radiant 2.0 SP1** (`C:\lscc\radiant\2.0`) — ONLY version supporting ES1
  silicon. Newer Radiant (2025.2.1) emits production-IDCODE bitstreams which the
  board rejects ("Mismatch to device ID code").
  - LSE synthesis. 2.0 SP1 has **no full SystemVerilog** support (native SV came
    in 2.1) → the main design in `fpga/rtl/*.sv` must be converted to
    Verilog-2001 OR synthesized with Synplify before it can build here. This is
    an open task (§5.4).
- **Radiant Programmer 2025.2** — use THIS for programming (its FTDI driver
  works; the 2.0 programmer reads 0x7FFFFFFF). Build in 2.0, program with 2025.2.
- **Windows gotcha**: Smart App Control blocks Radiant 2.0's unsigned DLLs →
  run Radiant as Administrator.
- **Simulation**: Icarus Verilog from OSS CAD Suite, portable install at
  `%LOCALAPPDATA%\oss-cad-suite\bin`. Run all sims:
  `powershell fpga/sim/run_sims.ps1` (3 testbenches, all must print PASS).
- **KiCad 10** (`C:\Program Files\KiCad\10.0`) for the adapter PCB.
  `kicad-cli` used for DRC/render/gerbers; zone fill needs KiCad's own python
  (`bin\python.exe _fill_zones.py`).

---

## 3. Programming the FPGA (proven recipe)

Build bitstream in **Radiant 2.0 SP1**, program with the **2025.2 Programmer**.

- **SRAM (volatile test)**: Device family `LIFCL_ENG`, device `LIFCL-40-ES`,
  Target Memory SRAM, Port = Slave SPI, Access = Direct Programming,
  Operation = Fast Configuration.
- **SPI flash (permanent)**: Target = External SPI Flash Memory, Port =
  **SSPI2SPI**, Operation = Erase,Program,Verify. Flash: Macronix MX25L12833F,
  8-pin SOP, start 0x0. Power-cycle after → boots from flash, D17 red goes off.
- Hardware prep: JP1 open, config jumper fitted (D17 red), TCK divider ≥2.
- Bitstream sanity: bytes `01 0F 10 43` near offset ~0x196. If you see
  `11 0F 10 43` it was built by new Radiant and will be rejected. **Never
  hand-patch the IDCODE** (breaks bitstream CRC).
- Blinky already validated end-to-end: `fpga/blinky/chronos_blinky.v` (+ .pdc,
  project in `fpga/blinky/es20/`). LEDs blink from flash after power-cycle.

---

## 4. FPGA design (fpga/rtl/) — architecture

Top `chronos_top.sv`. Data path per camera:

```
cam D-PHY pads → mipi_dphy_rx.v (Lattice soft D-PHY IP wrapper, per-cam byte clk)
  → csi2_rx.sv (word align + packet parse, ECC/CRC via csi2_pkg.sv)
  → frame_buffer.sv (async FIFO, Gray pointers, FWFT, token stream, pkt_avail)
  → tx_arbiter.sv (round-robin 4:1 packet mux, VC = camera index)
  → csi2_tx.sv (packet build + payload prefetch FIFO)
  → mipi_dphy_tx.v (hard D-PHY IP wrapper, 2 lanes)
```

Control plane: `i2c_slave.sv` (Jetson @0x3C) → `config_regs.sv`;
`trigger_generator.sv` (phase-accumulator FSIN rate engine);
`i2c_master.sv` + `ov9281_init.sv` per camera (SCCB init, DEV_ADDR per SID);
`chronos_pll.sv` (12 MHz → **192 MHz clk_sys** + 96 MHz clk_byte);
`cdc.sv` (2FF sync, pulse sync, pulse_stretch ~44 ms for LEDs).
Pinout: `fpga/constraints/chronos_pinout.pdc` (netlist-verified 2026-07).

Key register map (I2C @0x3C, 8-bit regs, pointer auto-increments):
CTRL(0x00: bit0=trigger_enable, bit1=soft-reset self-clearing),
FRAME_RATE, PULSE_WIDTH_L/H, CAM_ENABLE, STATUS, ERROR, FRAME_COUNT*,
VERSION, ID_L/ID_H. (Exact layout in `config_regs.sv` — source of truth.)

### 4.1 Non-obvious design decisions (don't undo these)

- **clk_sys = 192 MHz, not 200**: 200 is unreachable from 12 MHz with integer
  PLL dividers in the legal VCO range (old params → VCO 1800 MHz → never locks).
  CLKFB_DIV=16 / CLKOP_DIV=6 / CLKOS_DIV=12, VCO 1152 MHz. All CLK_HZ params
  in trigger_generator / ov9281_init / i2c_master / csi2_tx follow 192 MHz.
- **i2c_slave was fully rewritten** (old FSM created spurious START by moving
  SDA while SCL high and never held ACK through clock 9 → Jetson could never
  talk to it). Rules baked in: sample on SCL rise, drive only while SCL low,
  ACK spans whole 9th clock, read data prefetched one byte ahead.
- **csi2_rx word aligner hunts combinationally** — with a registered-only lock
  the first packet after every (re)lock was lost (found in simulation).
  A watchdog re-hunts after 3 consecutive header-ECC errors or ~170 ms
  locked-but-idle (false-lock recovery).
- **Deadlock escapes everywhere**: tx_arbiter aborts a packet on unexpected-SOP
  head or ~0.3 ms stall; csi2_tx force-terminates when its payload FIFO starves
  ~40 µs; frame buffers get dual-side (wr+rd) resets gated by cam_enable[i].
- **trigger_generator uses a phase accumulator** (exact average rate for
  non-divisor fps, ≤1 clk jitter, no giant combinational divider).
- **LEDs are inverted in RTL** (active-low hardware).
- **Icarus portability rules** used across the RTL: no `ref` task args, no
  ternaries assigning enum/state types, found-guard instead of `break` in
  `always_comb` for-loops.

### 4.2 Simulation (all passing)

`fpga/sim/run_sims.ps1` runs, via Icarus (`-g2012`):
- `tb_chronos_csi2` — full RX→buffer→arbiter→TX loopback, 3 packets, 0 errors.
- `tb_i2c_slave` — BFM master: addressing, write/readback, auto-inc multi-read/
  write, self-clearing soft reset, foreign-addr NACK.
- `tb_trigger_generator` — scaled clock, exact pulses/sec incl. 7 fps,
  pulse width, >MAX clamp, disable.

---

## 5. FPGA — what is left to do (in order)

1. **Fill `ov9281_init.sv` INIT_ROM** with the production OV9281 register table:
   1280x800 RAW10, 2-lane, PLL configured for **27 MHz XCLK**, external
   trigger/FSIN slave mode, VTS for 30 fps. Marked rows in the file show where.
   (Take values from the SincereFirst spec PDF in repo root + OV9281 datasheet.)
2. **Generate real IP cores in Radiant IP Catalog** (2.0 SP1):
   - `mipi_dphy_tx` CM/CN/CO dividers for clk_ref=192 MHz and the chosen line
     rate (wrapper params are placeholders);
   - regenerate `chronos_pll` for the x16 ratio with tool-blessed settings;
   - soft D-PHY RX instances.
3. **SystemVerilog → LSE problem**: Radiant 2.0 SP1 LSE cannot digest the
   `.sv` files. Either convert RTL to Verilog-2001 or use Synplify Pro inside
   Radiant. Budget real time for this; the RTL uses SV structs/enums/interfaces
   lightly but pervasively.
4. **Synthesize, meet timing** (192 MHz clk_sys; PDC has the clock groups),
   program SRAM first, then flash.
5. **Hardware bring-up phases**: 1 camera (J3, addr 0x60) → verify SCCB init +
   RX lock via STATUS regs/LEDs → TX loopback to Jetson → 4 cameras + VC →
   FSIN sync validation (LED1/LED2 pulse-stretched indicators help).
6. **Bandwidth ceiling** (hard constraint, don't promise more): 4 cams x 2 lanes
   x 800 Mbps = 6.4 Gbps in; TX = 2 lanes ≤ ~2.5 Gbps/lane ≈ 5 Gbps ceiling.
   4x30fps ≈ 1.6 Gbps — comfortable. 4x120fps does NOT fit.

---

## 6. Jetson side (app/ + drivers/)

Both trees rewritten 2026-07 to match the real architecture. **Neither has ever
been compiled** — first task on the Jetson is a build + fix pass.

### drivers/ (Linux kernel, L4T)
- `chronos_fpga/` — I2C driver, compatible `"chronos,fpga-ctrl"`, addr 0x3C,
  regmap_i2c; sysfs: trigger_enable, frame_rate, pulse_width, cam_enable,
  status, error, frame_count, version, id. Exports in-kernel API
  (`chronos_fpga_get_client`, EPROBE_DEFER pattern).
- `chronos_csi/` — V4L2 **async subdev bridge** (`"chronos,csi-bridge"`), one
  source pad, Y10_1X10 1280x800, `s_stream` toggles FSIN via chronos_fpga.
  `MODULE_SOFTDEP("pre: chronos_fpga")`. No /dev/video code — **Tegra VI owns
  the video nodes**.
- `chronos-orin-nx.dts` — overlay: FPGA @0x3C + bridge → NVCSI → VI graph,
  4 VI channels, `vc-id` 0..3, strict 1:1 endpoint pairing (Tegra requires it;
  modeled after L4T GMSL examples). tegra-camera-platform points at the bridge.
- `ov9281/` and `imu/` are **QUARANTINED** (do-not-load headers, excluded from
  the top Makefile): FPGA owns sensor config; IMU is FPGA-wired, not Jetson.
- First-build watchpoint: the 5.10/5.15 `v4l2_subdev` state-arg API switch in
  chronos_csi.c.

### app/ (userspace)
- `chronos_capture.c/.h` — library around **V4L2 MMAP** capture from
  /dev/video0..3 (NvBuffer/EGL deleted; optional CUDA upload via
  `CHRONOS_WITH_CUDA` CMake flag → pitch-aware cudaMemcpy2D).
  Consumer-owned buffers: capture thread never requeues;
  `chronos_release_frame_set()` re-queues via an in-flight table.
  FPGA CTRL written on start/stop; VERSION/ID verified at init (warn-only).
  `get_frame_set` timeout: loops on cond var, -1 = infinite. Stats: fps, skew,
  seq-gap drops, fpga_status/error over a persistent I2C fd.
  sync_valid = timestamp spread + STATUS bits. `fsin_pulse_width_cycles`
  config (0 → 2000-cycle default). Frame data = mmap pointer (no dmabuf fds).
- `demo_app.cpp` (optional OpenCV display), `sync_test.cpp` (defaults 30 fps).

### Jetson bring-up order
1. Build both modules against the L4T kernel tree; fix API drift.
2. Apply/compile the DTS overlay; boot; check `dmesg` for chronos_fpga probe
   (I2C 0x3C ACK proves the rewritten i2c_slave works on real wires).
3. `v4l2-ctl --list-devices` → 4 video nodes from Tegra VI.
4. Stream 1 channel raw (`v4l2-ctl --stream-mmap`), then `sync_test`.

---

## 7. Chronos ↔ Helios physical link (adapter PCB v3)

**Never connect J7 to Helios CAM1 with a plain cable**: J7 is custom
(SDA/SCL swapped vs RPi, 3.3V on pins 19/20, GND on 15) — a direct hookup
shorts Helios 3.3V to GND.

`hardware/adapter_chronos_helios/` contains the finished **v3** adapter
(28x28 mm, 4-layer JLC04161H-7628, DRC clean, JLC-ready):

- J1 = 22p FH12-type (XUNPU FPC-05F-22PH20, LCSC **C2856804**) → Chronos J7,
  **straight 22p 0.5 mm Type-A FFC**.
- J2 = 15p FH12-type (XFCN F0502-B-15-15T-R, LCSC **C2844857**) → Helios CAM1,
  **straight 15p 0.5 mm Type-A FFC**.
- **Pin-1 model (user-verified on the physical boards!)**: boards face to face,
  both pin 1s on the SAME absolute side → Chronos link mirrors through the
  cable (J7.i ↔ J1.23−i), Helios link maps **straight** (CAM.j ↔ J2.j).
  The Helios CAM connector is opposite-handed vs the standard FH12 footprint.
  v2 (one commit earlier) had this wrong; v3 is the corrected board.
- All 6 CSI conductors: identical top-layer diagonals, zero vias, zero skew.
  Only SDA crosses SCL once on In2.Cu. `_check_map.py` verifies the whole
  J7→CAM chain end-to-end (prints PASS).
- **Safety net**: SJ1 solder jumper OPEN = 3.3V rails isolated (each board
  powers itself). J1.19 intentionally NC. Test pads: TP1=Chronos 3V3,
  TP2=Helios 3V3 (V33H), TP3=SENSE (sees CAM GND when correct), TP4=GND.
  **Before full hookup: TP-V33H must read 3.3 V and TP-SENS must beep to GND.**
  Wrong cable type (A vs B) shows up there harmlessly; keep cables FLAT
  (no folds/twists — a fold flips the mapping).
- Ordering: JLC 4-layer 1.6 mm, **Impedance control: JLC04161H-7628**;
  upload `fab/chronos_helios_adapter_gerbers.zip`, BOM/CPL in `fab/`.
  Verify connector rotation in the JLC assembly preview (openings face the
  board edges).
- Regenerating the board: `python _gen_v3.py` → KiCad-python `_fill_zones.py`
  → `kicad-cli pcb drc` → `python _check_map.py`. The .kicad_pcb is generated;
  edit the script, not the board, for systematic changes.

**Helios CAM1 15p pinout (RPi std)**: 1 GND, 2/3 D0∓, 4 GND, 5/6 D1∓, 7 GND,
8/9 CLK∓, 10 GND, 11/12 unused, 13 SCL, 14 SDA, 15 3V3.
**Chronos J7 22p**: 1 GND, 2/3 D0∓, 4 GND, 5/6 D1∓, 7 GND, 8/9 CLK∓, 10 GND,
12 GND, 13 SDA, 14 SCL, 15 GND, 18 GND, 19/20 3V3, 21/22 GND (11/16/17 NC).

---

## 8. Repo map

```
fpga/rtl/            main design (SystemVerilog) — see §4
fpga/constraints/    chronos_pinout.pdc (netlist-verified)
fpga/sim/            3 testbenches + run_sims.ps1 + filelist_sim.f
fpga/blinky/         proven bring-up design (Verilog-2001 + Radiant 2.0 project)
fpga/README.md       build/sim instructions; DESIGN_DECISIONS.md = rationale
drivers/             chronos_fpga/, chronos_csi/, chronos-orin-nx.dts,
                     quarantined ov9281/ + imu/, top Makefile, README
app/                 chronos_capture lib + demo_app + sync_test + CMake
hardware/            Altium project, BOM, Chronos.NET netlist (source of truth),
                     adapter_chronos_helios/ (KiCad v3 + fab/ + scripts)
docs/                audit reports
CLAUDE.md            older memory document (superseded by this file)
SF-AOV9281 ... .pdf  camera module spec (repo root)
```

---

## 9. Gotchas checklist (things that already burned time once)

1. ES1 silicon: build with Radiant 2.0 SP1 only; program with 2025.2 Programmer.
2. Never hand-patch bitstream IDCODE (CRC breaks).
3. SSPI programming, not JTAG. JP1 open + config jumper (D17 red) + JP2 closed.
4. Smart App Control blocks Radiant 2.0 → run as Administrator.
5. Cameras are dead without FPGA-forwarded 27 MHz MCLK.
6. Camera SCCB addr differs per port (0x60 J3/J5, 0x10 J4/J6).
7. LEDs active-low; Bank 1 is 3.3 V (LVCMOS33).
8. clk_sys is 192 MHz — don't "fix" it back to 200.
9. Never cable J7 straight to Helios CAM1; use the adapter, TP-check first,
   SJ1 stays open, FFCs must lie flat.
10. Helios CAM connector numbering is opposite-handed vs standard FH12 — the
    v3 adapter accounts for this (verified with the boards, don't re-mirror).
11. Verify pin sites in Chronos.NET before any PDC change.
12. Icarus quirks: no `ref` ports, no enum ternaries, no `break` in
    always_comb loops.
13. drivers/ + app/ compile status: NEVER built; expect an API-fix pass.
14. `.gitignore` already handles KiCad `.history/`, sim artifacts, Altium noise.

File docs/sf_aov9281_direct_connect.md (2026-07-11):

# Chronos ↔ SincereFirst SF-AOV9281 (direct connect)

The **SincereFirst SF-AOV9281** (OV9281 CSP, mono RAW, 2-lane MIPI) terminates in
a Panasonic **`AXT624124`** header on a flex tail — the exact mating part for the
Chronos `AXT524124` socket (J3=CAM0 … J6=CAM3). It plugs **directly** into the
board. **No adapter PCB, no 3.3 V boost, no I²C level shifter, no FSIN flying
wire.** (Spec: `QR-RD-F002 Rev-A`, V1.0, 2018-02-22.)

This replaces the Waveshare OV9281-120 plan (`waveshare_ov9281_adapter.md`,
obsolete) and **restores hardware FSIN sync**.

## Why it just works
- **Connector**: `AXT624124` header ↔ board `AXT524124` socket (0.4 mm, 24-pin).
- **FSIN on pin 16** → global-shutter hardware sync over the existing FPGA FSIN net.
- **DOVDD/IO = 1.8 V** → matches the board's 1.8 V SCCB and FSIN bank; no shifter.
- **XCLK on pin 19** → externally clocked. The 27 MHz oscillator X2 feeds the
  FPGA (pin L5); the FPGA forwards it to each camera's XCLK pin
  (M3/M4/M5/M6 → J3..J6 pin 19, 33 Ω series). The FPGA MUST drive MCLK or the
  sensor will not even respond on SCCB (no on-module oscillator).
- **RESET on pin 21** → matches the board `CAM_RESET`.
- The board's connector + FSIN@16 + XCLK@19 + RESET@21 + SDA@1/SCL@2 + 2 MIPI
  lanes match the standard OV9281 CSP module pinout — the board was designed for
  exactly this class of module.

## Pin map: SF-AOV9281 vs board J3 (CAM0)

| Pin | SF-AOV9281 | Board J3 (AXT524124) | Note |
|----|---|---|---|
| 1  | SDA | CAM0_SDA (1.8 V) | I²C data |
| 2  | SCL | CAM0_SCL (1.8 V) | I²C clock |
| 3  | DOVDD 1.8 V | 1.8 V rail | **confirmed** |
| 4  | MCP (CLK+) | CAM0_CLK_P | MIPI clock+ |
| 5  | MCN (CLK−) | CAM0_CLK_N | MIPI clock− |
| 6  | DGND | GND | |
| 7  | MDP0 | CAM0_D0_P | MIPI lane0+ |
| 8  | MDN0 | CAM0_D0_N | MIPI lane0− |
| 9  | DGND | GND | |
| 10 | MDP1 | CAM0_D1_P | MIPI lane1+ |
| 11 | MDN1 | CAM0_D1_N | MIPI lane1− |
| 12 | DGND | GND | |
| 13 | LPWM | not connected | floats (netlist: no net on J*-13) |
| 14 | GPIO2 | not connected | floats |
| 15 | AGND | AGND (via ferrite) | FB2/FB3/FB9/FB10 to GND |
| 16 | **FSIN** | **FSIN0 (1.8 V)**  | hardware frame sync (U5 buffer, 33 Ω) |
| 17 | SID | see note below | sets the SCCB address per port |
| 18 | DVDD 1.2 V | 1.2 V rail (V1P2)  | **confirmed (netlist)** |
| 19 | XCLK | CAM0_MCLK (FPGA M3)| FPGA forwards 27 MHz from X2 |
| 20 | STROBE | not connected | floats |
| 21 | RESET | CAM_RESET (W18) | active-low, shared by all 4 |
| 22 | AVDD 2.8 V | 2.8 V rail (V2P8)  | **confirmed (netlist)** |
| 23 | ULPM | not connected | floats |
| 24 | DGND | GND | |

Power rails (pins 3/18/22) verified against the netlist: **V1P8 / V1P2 / V2P8**,
matching the module.

### SID strapping → per-port SCCB address (netlist fact)
| Port | Pin 17 (SID) | 7-bit SCCB address |
|---|---|---|
| J3 (CAM0) | GND | **0x60** |
| J4 (CAM1) | 4.7 k pull-up to VCCIO6 (R36) | **0x10** |
| J5 (CAM2) | GND | **0x60** |
| J6 (CAM3) | 4.7 k pull-up to VCCIO6 (R51) | **0x10** |

Each camera has a dedicated I²C bus, so the mixed addressing is harmless — but
the firmware must use the right address per port (`chronos_top` passes
`DEV_ADDR` accordingly).

## Firmware implications
- **FPGA must generate XCLK**: 27 MHz enters the FPGA at L5 (from X2) and is
  forwarded to `cam_mclk[3:0]` (M3..M6). Implemented in `chronos_top` +
  `chronos_pinout.pdc`. Keep MCLK running whenever cameras may be accessed —
  without it the sensor's SCCB is dead.
- **XCLK = 27 MHz**, not 24 MHz: the OV9281 init table's PLL registers must
  target a 27 MHz input clock.
- **SCCB addresses are mixed**: CAM0/CAM2 = 0x60, CAM1/CAM3 = 0x10 (SID
  strapping above). `chronos_top` parameterizes `ov9281_init` per camera.
- **External-trigger / FSIN snapshot mode** — unchanged requirement: the init ROM
  must put the sensor in slave-strobe mode so each FPGA FSIN pulse exposes a frame.
  The synchronized 30 fps comes from the FPGA trigger period, not free-running.
- FSIN buffer U5 (SN74LVC125A) is powered from V1P8 (netlist) → FSIN swings
  1.8 V at the camera, matching DOVDD. Confirmed, no action needed.

## Mechanical
- The module is a flex-tail camera with the `AXT624124` header at the tail end;
  it seats directly onto the board socket (1.0 mm mated height). Check FFC contact
  side/orientation and that the tail length reaches each of the 4 sockets.
- Optical: 2.3 mm f/2.2 lens, ~85° HFOV, focus 50 cm–∞.

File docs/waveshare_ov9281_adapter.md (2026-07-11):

# Chronos ↔ Waveshare OV9281-120 Camera Adapter

> **OBSOLETE / SUPERSEDED (2026-06-01).** The selected camera is now the
> **SincereFirst SF-AOV9281**, which terminates in an **`AXT624124`** header — the
> direct mate for the board's `AXT524124` socket — and exposes **FSIN on pin 16**.
> No adapter, boost converter, I²C level shifter, or FSIN flying wire is needed.
> See **`docs/sf_aov9281_direct_connect.md`**. This file is kept only as a record
> of the Waveshare (RPi 15-pin FFC) adapter analysis.

Active mezzanine adapter to connect a **Waveshare OV9281-120** (Raspberry Pi
15-pin FFC camera) to a **Chronos HW_CHRONOS_R1** camera port (`AXT524124`).
One adapter is required **per camera** (×4).

> Design point: 4 cameras @ 30 fps, **hardware FSIN sync required**, camera 3.3 V
> generated on the adapter by boosting the 2.8 V camera rail.

## Why an active adapter (not a cable)

| Topic | HW_CHRONOS_R1 side (AXT524124) | Waveshare side (15-pin RPi) | Adapter action |
|---|---|---|---|
| Power | discrete 2.8 / 1.8 / 1.2 V rails, no 3.3 V | single **3.3 V** in, on-board LDOs | **boost 2.8 V → 3.3 V** |
| SCCB | 1.8 V, pulled up to 1.8 V | SCL/SDA pulled up to **3.3 V** | **1.8↔3.3 V I²C translator** |
| Clock | FPGA drives XCLK (MCLK) | self-clocked (on-board 24 MHz) | MCLK **unused** |
| Enable/Reset | active-low `CAM_RESET` (1.8 V) | `POWER-EN` (3.3 V), no reset pin | pull POWER-EN high (opt. sequencing) |
| FSIN | FPGA FSIN on pin 16 (1.8 V) | **not on the connector** | **flying wire to OV9281 FSIN pad** |
| MIPI | 4-lane-capable, lanes 2/3 unused | 2-lane | route 2 lanes + clock, 1:1 |

MIPI is electrically compatible (D-PHY swing is independent of the supply
question); only 2 data lanes + clock are used.

## Connector reference

### Board socket — `AXT524124` (J3=CAM0, J4=CAM1, J5=CAM2, J6=CAM3)
Panasonic F4S, 0.4 mm pitch, 24-pin, 2-row, 1.0 mm mated height.
**Adapter mates it with header `AXT624124`.**

CAM0 (J3) net map as routed on HW_CHRONOS_R1:

| Pin | Net | Pin | Net |
|----|-----|----|-----|
| 1 | CAM0_SDA (1.8 V) | 13 | *not connected* |
| 2 | CAM0_SCL (1.8 V) | 14 | *not connected* |
| 3 | **V1P8 (DOVDD)** | 15 | AGND (via ferrite) |
| 4 | CAM0_CLK_P | 16 | **FSIN0 (1.8 V)** |
| 5 | CAM0_CLK_N | 17 | SID strap (J3: GND) |
| 6 | GND | 18 | **V1P2 (DVDD)** |
| 7 | CAM0_D0_P | 19 | CAM0_MCLK (FPGA M3) |
| 8 | CAM0_D0_N | 20 | *not connected* |
| 9 | GND | 21 | CAM_RESET (shared) |
| 10 | CAM0_D1_P | 22 | **V2P8 (AVDD)** |
| 11 | CAM0_D1_N | 23 | *not connected* |
| 12 | GND | 24 | GND (25–28 GND/MNT) |

> CORRECTED against the netlist (`Chronos.NET`, 2026-07): pins 3/18/22 are
> V1P8/V1P2/V2P8 (this table originally guessed a different order), pin 17 is
> the SID strap (not plain GND on all ports), pin 19 MCLK is FPGA-driven, and
> pins 13/14/20/23 are unconnected (there are no D2/D3 lanes on this board).

### Camera — Raspberry Pi 15-pin FFC, 1.0 mm (PH1.0-15PIN)

| Pin | Name | Pin | Name |
|----|---|----|---|
| 1 | GND | 9 | MCP (CLK+) |
| 2 | MDN0 (D0−) | 10 | GND |
| 3 | MDP0 (D0+) | 11 | POWER-EN |
| 4 | GND | 12 | LED-EN |
| 5 | MDN1 (D1−) | 13 | SCL |
| 6 | MDP1 (D1+) | 14 | SDA |
| 7 | GND | 15 | VCC 3.3 V |
| 8 | MCN (CLK−) | | |

## Adapter schematic (per camera)

```
 AXT624124 header (JA, to board)                 15-pin FFC (JB, to camera)
 ----------------------------------              --------------------------
 JA.18 (2.8V AVDD) --+--> [U1 buck-boost] --3V3--+--> JB.15 VCC
                     |     L=1µH, Cin/Cout=10µF   +--> [10k] --> JB.11 POWER-EN
                     |                            +--> [PCA9306 VREF2 via 200k]
 JA.22 (1.8V) -------|--> PCA9306 VREF1 (200k)
 JA.6/9/12/17/24 GND-+--> GND plane --------------+--> JB.1/4/7/10 GND

 SCCB through U2 = PCA9306 (1.8↔3.3):
   JA.2 SCL(1.8) <-> U2 -> JB.13 SCL(3.3)
   JA.1 SDA(1.8) <-> U2 -> JB.14 SDA(3.3)
   (pull-ups already exist: 1.8V side on board, 3.3V side on camera)

 MIPI (1:1, 100Ω diff, length-matched):
   JA.4/5  CLK_P/N -> JB.9/8  MCP/MCN
   JA.7/8  D0_P/N  -> JB.3/2  MDP0/MDN0
   JA.10/11 D1_P/N -> JB.6/5  MDP1/MDN1

 FSIN (hardware sync) — NOT on the FFC:
   JA.16 FSIN0(1.8) -- [33Ω] --> test pad "FSIN" + GND pad
        -> flying wire to the OV9281 FSIN pad on the Waveshare PCB

 Unused: JA.19 (MCLK), JA.13/14/20/23 (lanes 2/3), JA.21 (CAM_RESET, see note),
         JB.12 (LED-EN) = NC
```

### Power: 2.8 V → 3.3 V boost (U1)
- Use a buck-boost (input 2.8 V is close to 3.3 V out): **TI TPS63802** (adj),
  set `Vout = 0.5·(1+Rt/Rb)` → Rt = 560 k, Rb = 100 k for 3.3 V; L = 1 µH,
  Cin = Cout = 10 µF. Budget ~150–200 mA out (≈250 mA from the 2.8 V rail; the
  board rail/ferrite is rated 500 mA — OK).
- A fixed-3.3 V boost (e.g. TPS61222) also works but margins are tighter when
  Vin≈Vout; the buck-boost is the robust choice.

### SCCB level translation (U2 = PCA9306)
- VREF1 → 1.8 V (JA.22), VREF2 → 3.3 V (U1 out), each via 200 k to its rail.
- Do **not** add extra pull-ups: the board already pulls the 1.8 V side
  (R25/R26 = 4.7 k) and the Waveshare board pulls the 3.3 V side.

### POWER-EN / reset
- Default: `POWER-EN` (JB.11) pulled to 3.3 V via 10 k → camera always enabled
  when the adapter is powered.
- Optional sequencing: gate POWER-EN from `CAM_RESET` (JA.21) via a small load
  switch / level shift so the FPGA reset sequence still powers the module.

### FSIN flying wire (mandatory for hardware sync)
1. The Waveshare 15-pin connector has **no FSIN**. Locate the **OV9281 FSIN pad**
   on the Waveshare module (inspect the PCB / request the pad from Waveshare).
2. Solder a thin wire from the adapter's **FSIN pad** (JA.16 via 33 Ω, 1.8 V CMOS)
   to that pad. The sensor's FSIN input is DOVDD(1.8 V)-referenced, so **no level
   shift is needed** — but confirm the board FSIN buffer rail (P1) is 1.8 V.
3. Keep this wire short and grounded-referenced (use the adjacent GND pad).

## BOM (per adapter, ×4 total)

| Ref | Part | Notes |
|----|---|---|
| JA | Panasonic AXT624124 | AXT6 header, mates board AXT524124 |
| JB | 1.0 mm 15-pos FFC/FPC conn | match Waveshare cable contact side |
| U1 | TI TPS63802 (buck-boost) | 2.8 V→3.3 V; Rt 560k / Rb 100k |
| U2 | NXP/TI PCA9306 | I²C 1.8↔3.3 V translator |
| L1 | 1 µH power inductor | for U1 |
| C | 2× 10 µF, several 0.1 µF | U1 in/out + decoupling |
| R | 10 k (POWER-EN), 33 Ω (FSIN), 2× 200 k (VREF) | |

## Firmware implications (already aligned for 30 fps)
- **XCLK unused**: the FPGA `CAM_MCLK` outputs can be left idle; Waveshare
  self-clocks at 24 MHz.
- **SCCB**: unchanged logic (open-drain). OV9281 default 7-bit address 0x60
  matches `ov9281_init` `DEV_ADDR`.
- **External-trigger mode**: the `ov9281_init` ROM must enable FSIN snapshot mode
  (per OV9281: reg 0x3030 bit2 + 0x3006 + frame-count 0x303F) so a rising FSIN
  edge captures a frame.
- **30 fps is the safe target**: OV9281 FSIN snapshot wake-up costs ≈61 396 XCLK
  (~2.55 ms at 24 MHz), which caps trigger-mode rate near ~90 fps. 30 fps
  (33.3 ms period) has wide margin — another reason the 30 fps design point holds.

## Mechanical notes
- Adapter = small rigid PCB: `AXT624124` on the bottom (mates the board socket,
  1.0 mm stack), FFC connector on top, then FFC cable to the camera.
- 0.4 mm header placement is accuracy-sensitive; follow Panasonic's recommended
  land pattern and solder-paste reduction.
- Route MIPI pairs 100 Ω differential, intra-pair ≤ 0.1 mm, inter-pair ≤ 1.0 mm
  (same rules as the main board camera nets).

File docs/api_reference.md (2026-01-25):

# Chronos API Reference

## Overview

The Chronos Capture Library provides a C API for synchronized multi-camera capture with zero-copy GPU memory access.

## Header File

```c
#include <chronos_capture.h>
```

## Initialization and Configuration

### chronos_init

Initialize the Chronos capture system.

```c
chronos_error_t chronos_init(void);
```

**Returns**: `CHRONOS_OK` on success, error code otherwise.

**Notes**:
- Must be called before any other Chronos functions
- Initializes all 4 cameras, IMU, and CUDA context
- Allocates NvBuffer pools for zero-copy operation

---

### chronos_shutdown

Shutdown the Chronos capture system.

```c
void chronos_shutdown(void);
```

**Notes**:
- Stops any active capture
- Releases all buffers and resources
- Safe to call even if not initialized

---

### chronos_configure

Configure capture parameters.

```c
chronos_error_t chronos_configure(const chronos_config_t *config);
```

**Parameters**:
- `config` - Pointer to configuration structure

**Returns**: `CHRONOS_OK` on success, error code otherwise.

**Configuration Structure**:
```c
typedef struct {
    uint32_t frame_rate;        // Target frame rate (1-120)
    uint32_t exposure_us;       // Exposure time in microseconds
    float gain_db;              // Analog gain in dB
    bool external_trigger;      // Use external trigger mode
    bool enable_imu;            // Enable IMU capture
    uint32_t buffer_count;      // Number of buffers (default 3)
} chronos_config_t;
```

---
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

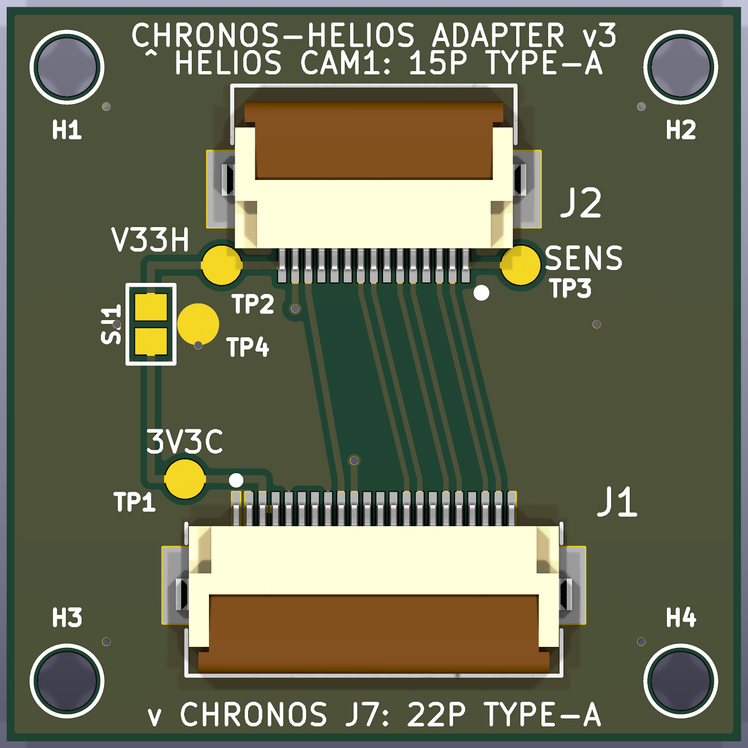
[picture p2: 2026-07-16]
hardware/adapter_chronos_helios/render_top.png

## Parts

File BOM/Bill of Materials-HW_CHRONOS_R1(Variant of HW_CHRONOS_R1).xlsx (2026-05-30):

Name | Description | Designator | Quantity | Footprint | Manufacturer Part Number | Fitted
0.1uF | CAP CER 0.1UF 25V 10% X5R 0201 | C1, C2, C3, C4, C7, C8, C9, C11, C12, C13, C15, C18, C19, C20, C24, C25, C27, C29, C31, C33, C35, C38, C40, C42, C45, C47, C49, C54, C55, C59, C60, C65, C66, C67, C68, C75, C92, C93, C95, C96, C99, C100, C102, C104, C106, C107, C171 | 47 | C0201, C0402 | GRM033R61E104KE14J | Fitted
10uF |  | C5, C14 | 2 | C0603 | CL10A106MO8NQNC | Fitted
4.7uF |  | C6, C10 | 2 | C0603 | CL10A475KA8NQNC | Fitted
18pF | CAP CER 18PF 25V 10% NP0 0402 | C16, C17 | 2 | C0402 | C0402C180K3GACTU | Fitted
1uF | CAP CECAP CER 10UF 10V X5R 20% 0603 | C21, C23, C37, C41, C44, C48, C101, C105 | 8 | C0603 | LMK107BJ106MALTD | Fitted
10uF | CAP CECAP CER 10UF 10V X5R 20% 0603 | C22, C39, C46, C52, C56, C57, C58, C64, C74, C91, C94, C98, C103, C108 | 14 | C0603 | LMK107BJ106MALTD | Fitted
10uF | CAP CER 10UF 10V X5R 0402 | C26, C28, C30, C32, C34, C36 | 6 | C0402 | CL05A106MP8NUB8 | Fitted
10uF | CAP CECAP CER 10UF 10V X5R 20% 0603 | C53 | 1 | C0603 | LMK107BJ106MALTD | Fitted
10nF |  | C63, C76, C77 | 3 | RLP-130-A | GRM155R61C103KA01D | Fitted
10uF | CAP CER 10UF 10V 20% X6S 0603 | C69, C71, C138, C140 | 4 | C0603 | CL10X106MP8NRNC | Fitted
0.1uF | CAP CER 0.1UF 25V 10% X5R 0201 | C70, C72, C118, C119, C120, C130, C131, C132 | 8 | C0201 | GRM033R61E104KE14J | Fitted
0.1uF | CAP CER 0.1UF 25V 10% X5R 0201 | C73, C97, C113, C114, C115, C116, C117, C124, C126, C127, C128, C129 | 12 | C0201 | GRM033R61E104KE14J | Fitted
0.1uF | CAP CER 0.1UF 25V 10% X5R 0402 | C78 | 1 | C0402 | GRM033R61E104KE14J | Fitted
20pF |  | C79, C80, C81 | 0 | C0402 | GJM1555C1H200FB01D | Not Fitted
1.0uF | CAP CER 10UF 10V 20% X6S 0603 | C109, C110, C111, C112 | 4 | C0603 | CL10X106MP8NRNC | Fitted
10uF-16V-0603SMT |  | C121, C122, C123, C125, C133, C134 | 6 | C0603 | CL10A106MO8NQNC | Fitted
1uF | CAP CER 10UF 10V 20% X6S 0603 | C135, C136, C137, C139 | 4 | C0603 | CL10X106MP8NRNC | Fitted
10uF,25V-1206SMT |  | C141, C155 | 2 | RLP-134 | TMK316BJ106KL-T | Fitted
220NF-0402SMT |  | C142, C143, C156, C157 | 4 | RLP-130-A | CL05A224KO5NNNC | Fitted
1000pF-0402SMT |  | C144, C145, C158, C159 | 4 | RLP-130-A | CL05B102KB5NFNC | Fitted
330pF-0402SMT |  | C146, C149, C160, C163 | 4 | RLP-130-A | CL05B331KB5NNNC | Fitted
10pF-0402SMT |  | C147, C148, C164, C167 | 4 | RLP-130-A | CL05C100CB5NNNC | Fitted
22uF,6.3V-0805SMT | CAP CER 22UF 10V X5R 0805 | C150, C151, C152, C153, C154, C165, C166, C168, C169, C170 | 10 | RLP-133 | CL21A226KPCLRNC | Fitted
10pF-0402SMT |  | C161, C162 | 0 | RLP-130-A | CL05C100CB5NNNC | Not Fitted
LED_GREEN_0603 |  | D1, D3, D4, D5, D6, D18, D19, D20, D21, D22, D23, D24, D25, D26, D27 | 15 | APT1608 | 150060GS75000 | Fitted
ESDR0502N-UDFN6 | ESD Protection - SLP2510P8 package 8-PIN | D2 | 1 | UDFN6_040 | ESDR0502NMUTBG | Fitted
LED_RED_0603 |  | D17 | 1 | APT1608 | 150060RS75000 | Fitted
SCHOTTKY/VISHAY-V12P10 |  | D28 | 1 | V12P10 | V12P10-M3/86A | Fitted
1N4448W |  | D29, D30, D33, D34 | 4 | 1N4448W | 1N4448WS | Fitted
DFLS220L |  | D31, D32, D35, D36 | 4 | DFLS220L | DFLS220L-7 | Fitted
F1251CT-ND | 5A Fast-Blo SMT Socketed Fuse | F1 | 1 | 0154010 | 0154010.DR | Fitted
MPZ1005S121CT000 | FERRITE BEAD 120 OHM 0402 1LN | FB1, FB7, FB8 | 3 | FB0402 | MPZ1005S121CT000 | Fitted
BLM15AG601SN1D | Chip Ferrite Bead, 0402, 600Ω @ 100MHz, 0.52Ω, 25%, 300mA | FB2, FB3, FB9, FB10 | 4 | FP-BLM15-0_05-MFG | BLM15AG601SN1D | Fitted
MPZ1005S121CT000 | FERRITE BEAD 120 OHM 0402 1LN | FB5, FB6 | 2 | FB0402 | MPZ1005S121CT000 | Fitted
ICM-42688-P | Integrated Circuit | IC1 | 1 | IIM42352 | ICM-42688-P | Fitted
62130621021 | Conn, Pin Hdr, 6POS, 2ROW, 1.27MM Rohs Compliant: Yes | J1 | 1 | 62130621021 | 62130621021 | Fitted
DX07S016JA3R1500 | CONN RCP USB2.0 TYP C 24P SMD RA | J2 | 1 | FP-DX07S016JA3R1500-MFG | DX07S016JA3R1500 | Fitted
AXT524124 | AXT524124 24 Position 0.4 mm Pitch Dual Row Board to Board Socket Narrow Pitch Connector | J3, J4, J5, J6 | 4 | FP-AXT524124-MFG | AXT524124 | Fitted
FH12-22S-0.5SH_1__98_ | Connector | J7 | 1 | FH1222S05SH198 | FH12-22S-0.5SH(1)(98) | Fitted
62101421021 | Conn, Header, 14Pos, 2Row, 1.27Mm Rohs Compliant: Yes |Wurth Elektronik 62101421021 | J20 | 0 | 62101421021 | 62101421021 | Not Fitted
PJ-002A | Male Power Jack 2.1mm | J39 | 1 | pj_002a_3p | 694106301002 | Fitted
62000311121 | THT Vertical Pin Header WR-PHD, Pitch 2.00 mm, Single Row, 3 pins | J44, P1 | 2 | 62000311121 | 62000311121 | Fitted
JUMPER |  | JP1, JP2 | 2 | R0603, 0603 | RC0603JR-070RL | Fitted
600ohm 500mA | FERRITE CHIP 600 OHM 500MA 0603 | L1, L2, L3 | 3 | FB0603 | BLM18AG601SN1D | Fitted
220ohm 500mA | FERRITE BEAD 600 OHM 0402 1LN | L4, L5, L6, L7, L8, L9 | 6 | FB0402 | BLM15AX601SN1D | Fitted
4.7uH-SPD62R-472M |  | L14, L15, L16, L17 | 4 | SPD62R | SPD62R-472M | Fitted
2N2222/SOT23 |  | Q1, Q2, Q3, Q4, Q5, Q6 | 6 | MMBT2222ALT-1 | MMBT2222ALT1G | Fitted
4.7K | RES 4.70K OHM 1/10W 1% 0603 SMD | R1, R2, R3 | 3 | R0603 | CRCW06034K70FKEA | Fitted
2.2K |  | R4, R9 | 2 | R0603 | CRCW06032K20FKEA | Fitted
33 | RES SMD 33 OHM 1% 1/10W 0402 | R5 | 1 | R0402 | ERJ-2RKF33R0X | Fitted
0 | RES 0.0 OHM 1/10W JUMP 0603 SMD | R6, R7, R8, R20, R21, R22 | 6 | R0603 | RC0603JR-070RL | Fitted
10K | RES 10K OHM 1/10W 5% 0603 | R10, R11, R12, R57 | 4 | R0603, R0402 | RMCF0603JT10K0 | Fitted
12K | RES 12K OHM 1/10W 1% 0603 SMD | R13, R16 | 2 | R0603 | RC0603FR-0712KL | Fitted
2K |  | R14 | 1 | R0402 | ERJ-2GEJ202X | Fitted
0 | Res 1/10W 0.0 Ohm 5% 0603 | R15, R17 | 0 | R0603 | RC0603JR-070RL | Not Fitted
4.7K |  | R18, R19, R53, R54 | 4 | RLP-101, r0402 | CRCW06034K70FKEA | Fitted
100k | RES 100K OHM 1/10W 1% 0402 SMD | R23 | 1 | R0402 | ERJ-2RKF1003X | Fitted
22 | RES SMD 22 OHM 1% 1/10W 0402 | R24 | 1 | R0402 | ERJ-2RKF22R0X | Fitted
4.7k | RES SMD 2.2K OHM 1% 1/10W 0402 | R25, R26, R32, R33, R36, R43, R44, R45, R46, R51 | 10 | R0402 | ERJ-2RKF2201X | Fitted
100 ohm | RES SMD 100 OHM 1% 1/20W 0201 | R27, R28, R29, R30, R31, R37, R38, R39, R40, R41, R42, R52 | 0 | R0201 | RC0201FR-07100RL | Not Fitted
33 | RES SMD 33 OHM 1% 1/10W | R34, R35, R47, R48 | 4 | R0201 | ERJ-2RKF33R0X | Fitted
CR0402-FX-5101GLF | Thick Film Chip Resistors 0402 5.1kΩ 0.0625W 1% 100ppm/°C | R55, R56 | 2 | FP-CR0402-IPC_A | CR0402-FX-5101GLF | Fitted
33 ohm | RES SMD 33 OHM 1% 1/20W 0201 | R58, R59, R60, R61, R62, R63 | 6 | R0402, RLP-100 | RC0402JR-0733RL | Fitted
0 | RES SMD 0.0OHM JUMPER 1/10W 0402 | R64, R65, R66, R67, R68, R70, R88, R89, R90, R91, R92 | 11 | R0201, R0402 | ERJ-2GE0R00X | Fitted
10k | RES SMD 10K OHM 1% 1/16W 0402 | R69, R83 | 2 | R0402 | RC0402FR-0710KL | Fitted
100 | RES SMD 100 OHM 1% 1/16W 0402 | R72, R80 | 2 | R0402 | RC0402FR-07100RL | Fitted
0 | RES SMD 33 OHM 1% 1/10W 0402 | R73, R74 | 2 | R0402 | ERJ-2RKF33R0X | Fitted
1k | RES 100K OHM 1/10W 1% 0402 SMD | R75 | 1 | R0402 | ERJ-2RKF1003X | Fitted
10k | RES SMD 10K OHM 1% 1/16W 0402 | R76, R82 | 2 | R0402 | RC0402FR-0710KL | Fitted
100 | RES SMD 100 OHM 1% 1/16W 0402 | R77 | 1 | R0402 | RC0402FR-07100RL | Fitted
33 | RES SMD 33 OHM 1% 1/10W 0402 | R78 | 1 | R0402 | ERJ-2RKF33R0X | Fitted
2.0k | RES SMD 1K OHM 1% 1/10W 0402 | R79, R81, R115, R117, R118, R119, R125, R126 | 8 | R0402 | ERJ-2RKF1001X | Fitted
4.7k | RES SMD 4.7K OHM 5% 1/10W 0402 | R84, R85, R87 | 3 | R0402 | ERJ-2GEJ472X | Fitted
1k | RES SMD 1K OHM 1% 1/10W 0402 | R86 | 0 | R0402 | ERJ-2RKF1001X | Not Fitted
15k |  | R113 | 1 | RLP-103 | ERJ-8GEYJ153V | Fitted
4.7k | RES SMD 2.2K OHM 1% 1/10W 0402 | R114 | 1 | R0402 | ERJ-2RKF2201X | Fitted
1.0k | RES SMD 1K OHM 1% 1/10W 0402 | R116 | 1 | R0402 | ERJ-2RKF1001X | Fitted
2.0k | RES SMD 1K OHM 1% 1/10W 0402 | R120 | 1 | R0402 | ERJ-2RKF1001X | Fitted
1.5k | RES SMD 750 OHM 5% 1/10W 0402 | R121 | 1 | R0402 | ERJ-2GEJ751X | Fitted
2.2k | RES SMD 4.7K OHM 5% 1/10W 0402 | R122, R123, R133 | 3 | R0402 | ERJ-2GEJ472X | Fitted
4.7k | RES SMD 4.7K OHM 5% 1/10W 0402 | R124, R132 | 2 | R0402 | ERJ-2GEJ472X | Fitted
0.1 |  | R127, R128, R129, R130, R131, R134, R135, R136, R137, R138, R153 | 11 | 0603 | ERJ-3RSFR10V | Fitted
10k | RES SMD 4.7K OHM 5% 1/10W 0402 | R140 | 1 | R0402 | ERJ-2GEJ472X | Fitted
1k | RES SMD 1K OHM 1% 1/10W 0402 | R141, R144 | 2 | R0402 | ERJ-2RKF1001X | Fitted
10k | RES SMD 4.7K OHM 5% 1/10W 0402 | R142 | 1 | R0402 | ERJ-2GEJ472X | Fitted
1.15K-0603SMT |  | R143, R165 | 2 | RLP-101 | RC0603FR-071K15L | Fitted
0 | RES 0.0 OHM 1/10W JUMP 0402 SMD | R145 | 0 | R0402 | RC0603JR-070RL | Not Fitted
0 | RES 0.0 OHM 1/10W JUMP 0603 SMD | R146, R147, R149, R150 | 0 | R0603 | RC0603JR-070RL | Not Fitted
909-0603SMT |  | R148, R170 | 2 | RLP-101 | RC0603FR-07909RL | Fitted
51K-0402SMT |  | R151, R157, R159, R161 | 4 | RLP-100 | RC0402FR-0751KL | Fitted
1.05K-0603SMT |  | R154 | 1 | RLP-101 | RC0603FR-071K05L | Fitted
1.07K-0603SMT |  | R155 | 1 | RLP-101 | RC0603FR-071K07L | Fitted
200 -0603SMT |  | R156 | 1 | RLP-101 | RC0603FR-07200RL | Fitted
34K-0402SMT |  | R158 | 1 | RLP-100 | RC0402FR-0734KL | Fitted
340-0603SMT |  | R160 | 1 | RLP-101 | RC0603FR-07340RL | Fitted
200-0603SMT |  | R164 | 1 | RLP-101 | RC0603FR-07200RL | Fitted
30_1K-0402SMT |  | R166 | 1 | RLP-100 | ERJ-2RKF3012X | Fitted
63_4K-0402SMT |  | R167 | 1 | RLP-100 | ERJ-2RKF6342X | Fitted
20K-0402SMT |  | R168 | 1 | RLP-100 | ERJ-2RKF2002X | Fitted
768-0603SMT |  | R169 | 1 | RLP-101 | RC0603FR-07768RL | Fitted
10K | RES SMD 10K OHM 1% 1/10W 0603 | R172 | 1 | R0603 | RC0603FR-0710KL | Fitted
1.0 K | RES SMD 1K OHM 1% 1/10W 0603 | R173 | 0 | R0603 | RC0603FR-071KL | Not Fitted
2K | RES SMD 2K OHM 5% 1/10W 0402 | R174, R175, R176, R177 | 4 | R0402 | ERJ-2GEJ202X | Fitted
GSRN | SWITCH TACTILE SPST-NO 0.05A 12V | SW4 | 1 | 4psmd_switch | 434153017835 | Fitted
PROGRAMN | SWITCH TACTILE SPST-NO 0.05A 12V | SW5 | 1 | 4psmd_switch | 434153017835 | Fitted
FT2232HL | IC USB HS DUAL UART/FIFO 64-LQFP | U1 | 1 | tqfp64_0p5_12p2x12p2_h1p6 | FT2232HL | Fitted
93LC56C-I/SN | IC EEPROM 2KBIT 3MHZ 8SOIC | U2 | 1 | so8_50_244 | 93LC56C-I/SN | Fitted
LIFCL-40-BG400 |  | U3 | 1 | LIFCL-40-BG400 | LIFCL-40-BG400 | Fitted
SN74LVC125APWR | IC BUF NON-INVERT 3.6V 14TSSOP | U5 | 1 | FP-PW0014A-IPC_B | SN74LVC125APWR | Fitted
MX25L12833FM2I-10G | IC FLASH 128MBIT 104MHZ 8SOP | U6 | 1 | SO8_MX25L12833FM2I10G | MX25L12833FM2I-10G | Fitted
SN74LVC2G125DCUR | IC BUFFER NON-INVERT 5.5V US8 | U9 | 1 | FP-DCU0008A-MFG | SN74LVC2G125DCUR | Fitted
NCP110AMX120TBG |  | U11 | 1 | 4XDFN_NCP110 | NCP110AMX120TBG | Fitted
NCP110AMX280TBG |  | U12 | 1 | 4XDFN_NCP110 | NCP110AMX280TBG | Fitted
BD00IC0WHFV-GTR |  | U13 | 1 | 6HVSOF_BD00IC0WHFV | BD00IC0WHFV-GTR | Fitted
TLV73310PDQNT |  | U14 | 1 | 4X2SON | TLV73310PDQNT | Fitted
LT3508EUF | IC, LINEAR TECH, LTC1563 | U15, U16 | 2 | LT3508EUF | LT3508EUF#PBF | Fitted
7M-12.000MAAJ | CRYSTAL 12MHZ 18PF SMD | X1 | 1 | xtal_4p_7m | 7M-12.000MAAJ-T | Fitted
ASE3-27.000MHz-K-T | Standard Clock Oscillators 27.000M 1.8V 30ppm | X2 | 1 | 27MHZ | ASE3-27.000MHz-K-T | Fitted

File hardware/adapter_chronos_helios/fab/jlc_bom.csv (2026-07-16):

Comment | Designator | Footprint | LCSC
FPC-05F-22PH20 | J1 | FFC 22P 0.5mm bottom-contact horizontal | C2856804
F0502-B-15-15T-R | J2 | FFC 15P 0.5mm bottom-contact horizontal | C2844857

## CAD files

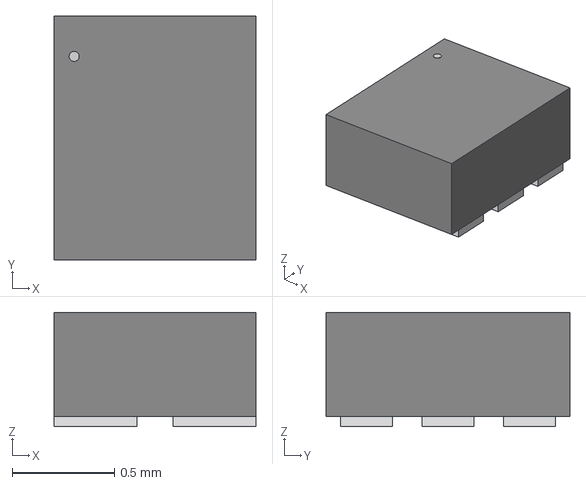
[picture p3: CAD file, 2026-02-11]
hardware/3Ds/UDFN6_1P2X1_ONS.step
0.99 x 1.19 x 0.561 mm

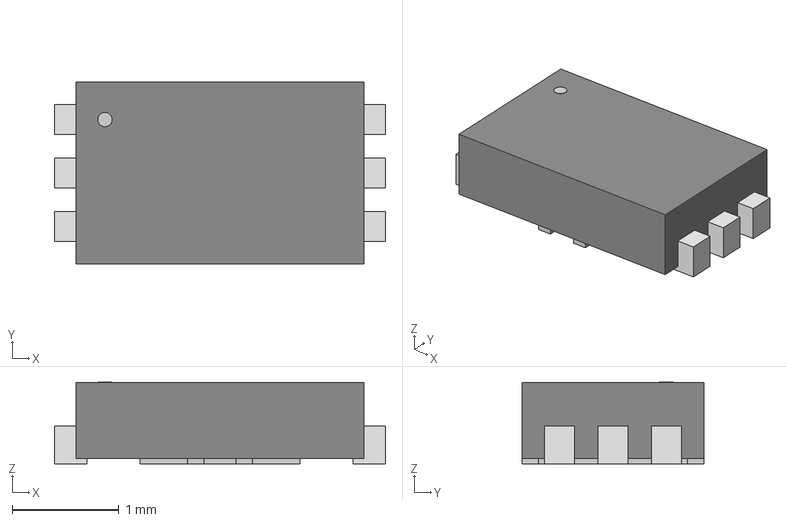
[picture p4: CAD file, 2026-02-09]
hardware/3Ds/HVSOF6_ROM.step
3.10 x 1.70 x 0.765 mm

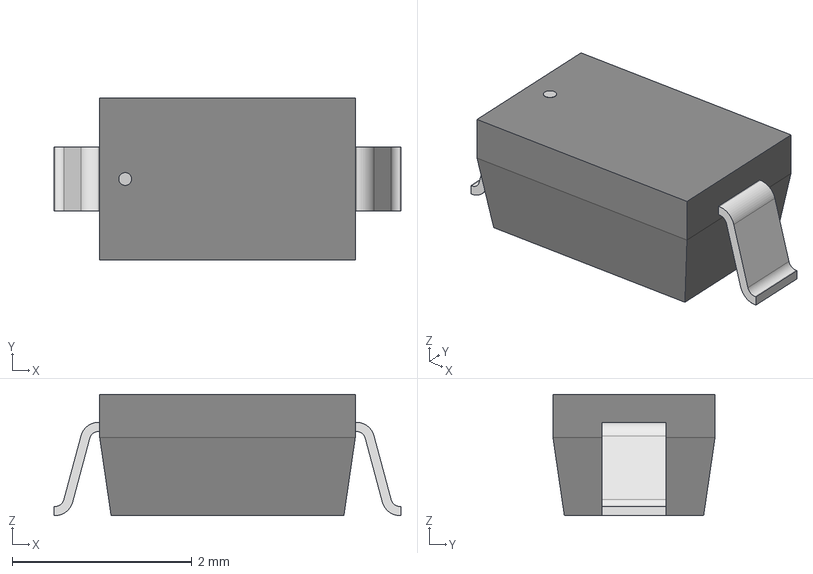
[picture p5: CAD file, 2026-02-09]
hardware/3Ds/SOD-123_ONS.step
3.86 x 1.80 x 1.35 mm

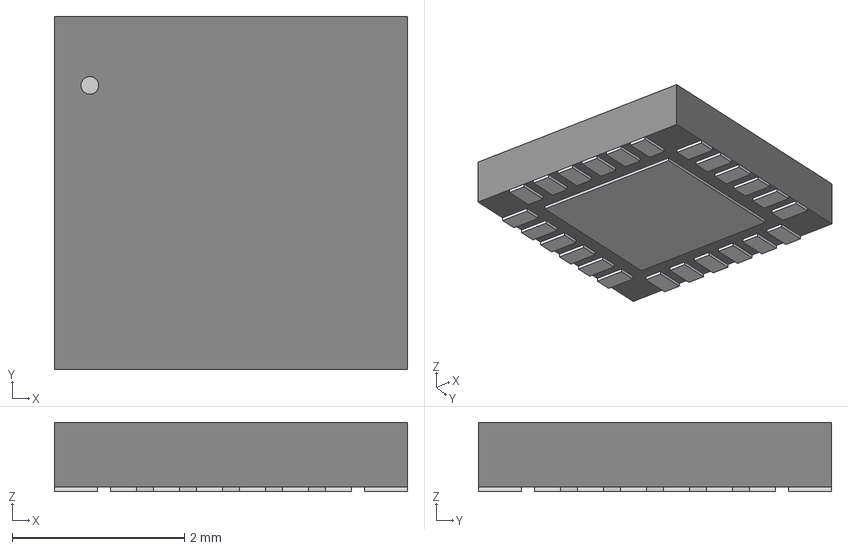
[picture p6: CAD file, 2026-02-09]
hardware/3Ds/QFN-24_UF_LIT.step
4.10 x 4.10 x 0.803 mm

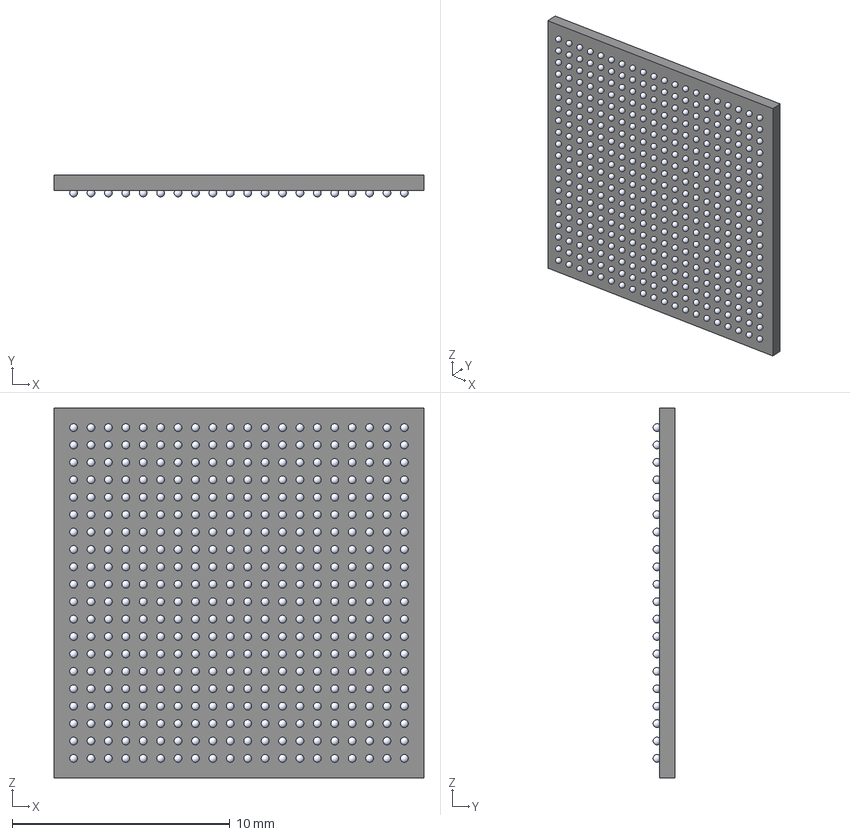
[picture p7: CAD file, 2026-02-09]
hardware/3Ds/BG400C.STEP
17.0 x 1 x 17.0 mm
Body_Solid1
Body002_Solid1
BALL_0001
BALL_0002
BALL_0003
BALL_0004
BALL_0005
BALL_0006
BALL_0007
BALL_0008
BALL_0009
BALL_0010
BALL_0011
BALL_0012
BALL_0013
BALL_0014
BALL_0015
BALL_0016
BALL_0017
BALL_0018
BALL_0019
BALL_0020
BALL_0021
BALL_0022
BALL_0023
BALL_0024
BALL_0025
BALL_0026
BALL_0027
BALL_0028
BALL_0029
BALL_0030
BALL_0031
BALL_0032
BALL_0033
BALL_0034
BALL_0035
BALL_0036
BALL_0037
BALL_0038
BALL_0039
BALL_0040
BALL_0041
BALL_0042
BALL_0043
BALL_0044
BALL_0045
BALL_0046
BALL_0047
BALL_0048
BALL_0049
BALL_0050
BALL_0051
BALL_0052
BALL_0053
BALL_0054
BALL_0055
BALL_0056
BALL_0057
BALL_0058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

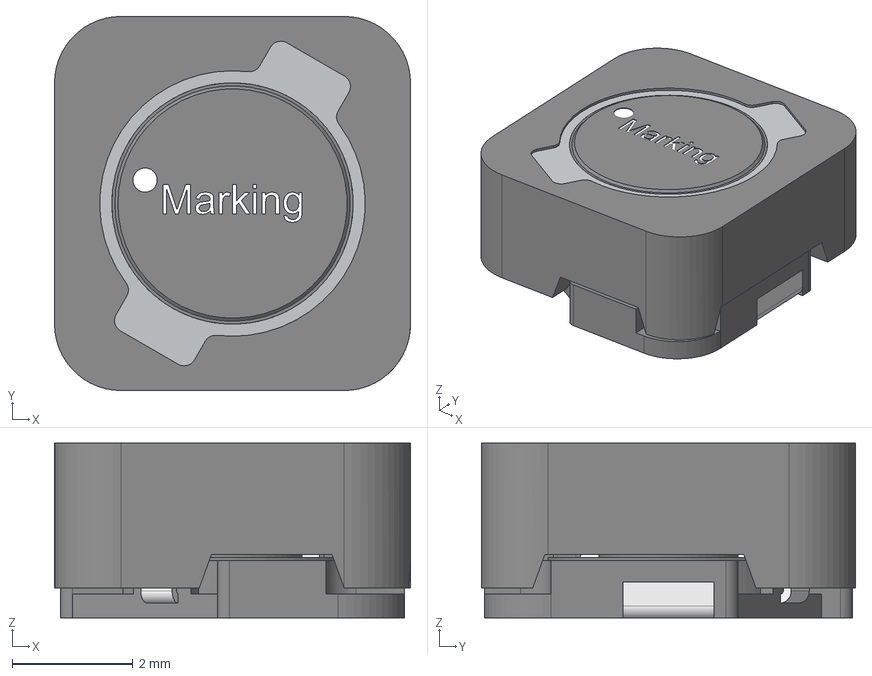
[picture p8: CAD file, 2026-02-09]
hardware/3Ds/Download_WE-PD_6033_STP+(rev1).stp
5.90 x 6.20 x 2.90 mm
Base
Pin x 2
glue
Core
Shielding

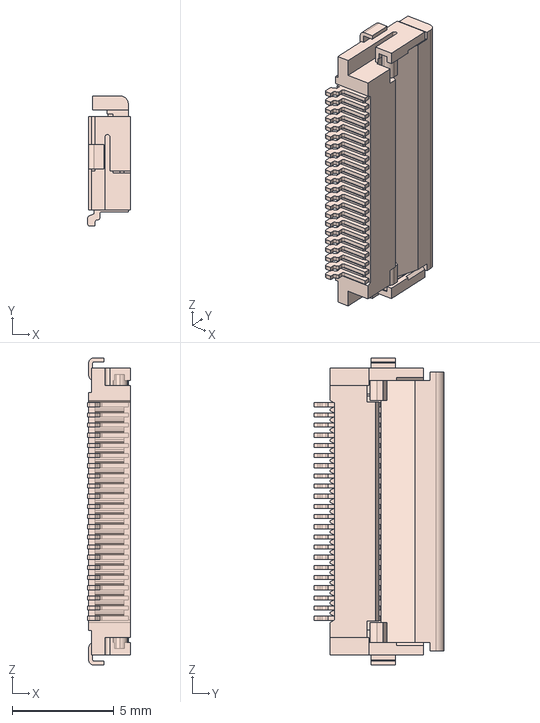
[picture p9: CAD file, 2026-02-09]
hardware/3Ds/FH12-22S-0.5SH-1--98.STEP
2.10 x 6.40 x 15.1 mm

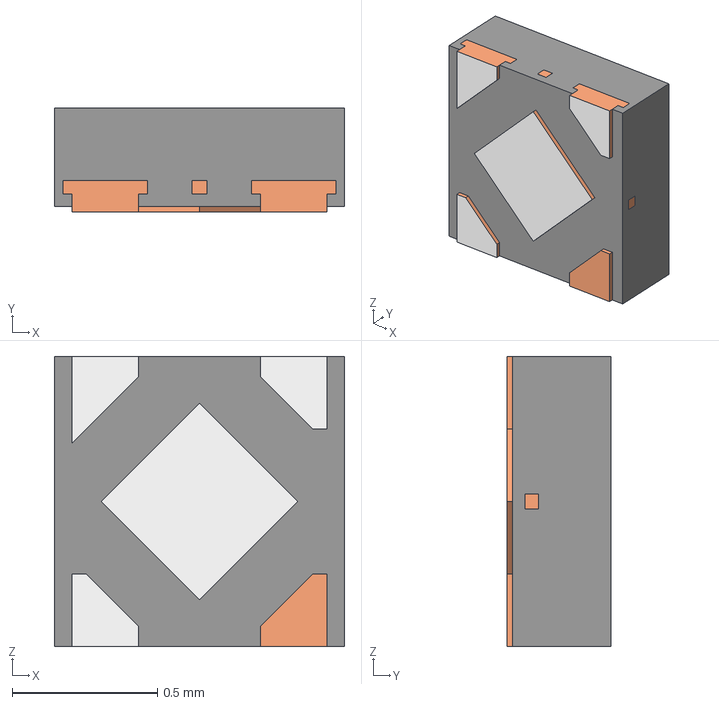
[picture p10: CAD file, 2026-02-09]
hardware/3Ds/DQN0004A.stp
1.00 x 0.36 x 1.00 mm
MOLD-SNB04A
FRAME-SNB04A

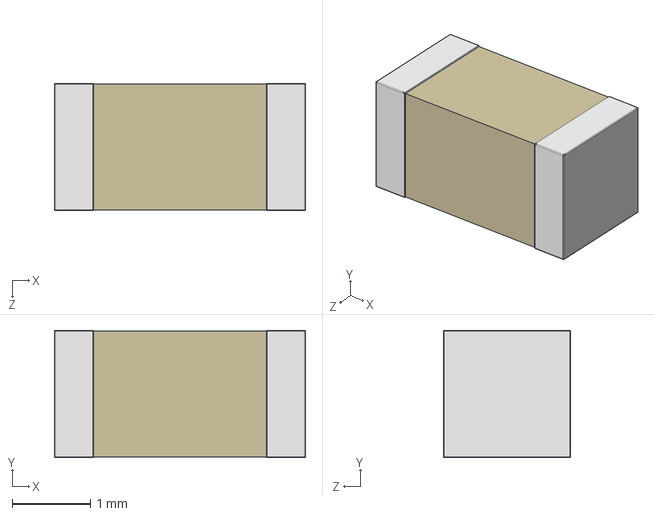
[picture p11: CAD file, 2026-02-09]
hardware/3Ds/CAP 1206.STEP
3.20 x 1.62 x 1.62 mm

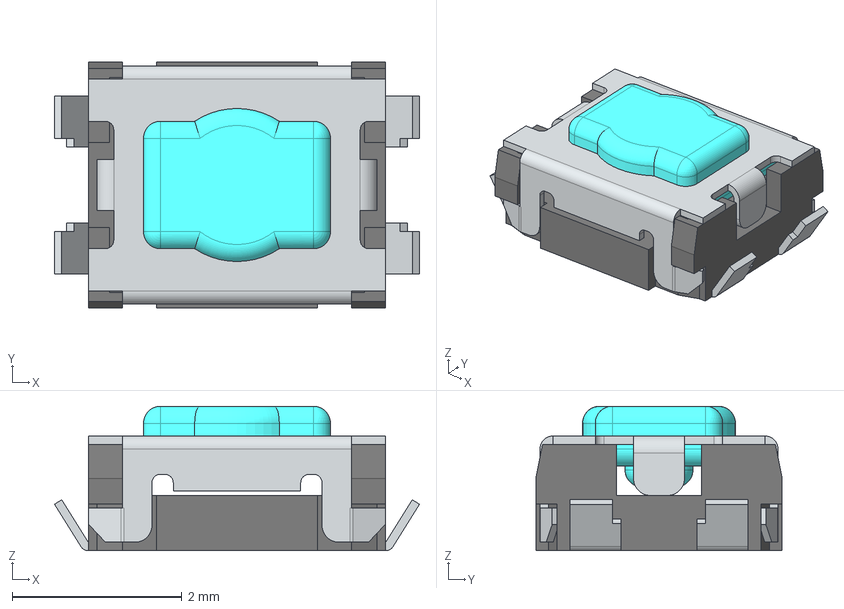
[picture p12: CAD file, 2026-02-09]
hardware/3Ds/434153017835.stp
4.29 x 2.90 x 1.70 mm
Frame
Cover
Stem
Terminal_l x 2
Terminal_r x 2

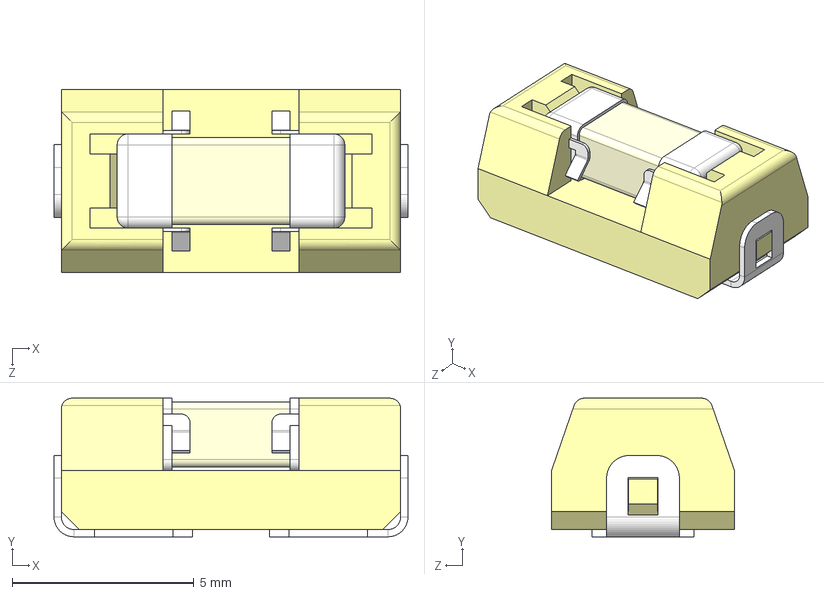
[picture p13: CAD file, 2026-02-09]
hardware/3Ds/0154010.DR.STEP
9.73 x 3.81 x 5.03 mm

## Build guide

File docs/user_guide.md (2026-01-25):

# Chronos User Guide

## Introduction

Chronos is a multi-camera MIPI synchronization system designed for synchronized capture from four OV9281 global shutter cameras on the NVIDIA Jetson Orin NX platform.

## Hardware Setup

### Components

1. **Chronos PCB** - Custom board with CrossLink-NX FPGA
2. **4x OV9281 Camera Modules** (KLT-Z6MF-OV9281 V3.0)
3. **FPC Cables** (10-15cm, 15-pin)
4. **Jetson Orin NX** development kit
5. **Power supply** (5V, 3A minimum)

### Connection Diagram

```
                    ┌─────────────────────────┐
                    │      Chronos PCB        │
                    │                         │
    Camera 0 ──────▶│ CAM0                    │
    Camera 1 ──────▶│ CAM1                    │
    Camera 2 ──────▶│ CAM2           CSI-OUT ─┼──▶ Jetson CSI
    Camera 3 ──────▶│ CAM3                    │
                    │                         │
         IMU ──────▶│ SPI (IMU)       I2C ───┼──▶ Jetson I2C
                    │                         │
                    │ PWR ───────────────────┼──▶ 5V Power
                    └─────────────────────────┘
```

### Installation Steps

1. **Mount cameras** in desired positions
2. **Connect FPC cables** to Chronos PCB (CAM0-CAM3)
3. **Connect CSI cable** from Chronos to Jetson (2-lane CSI port)
4. **Connect I2C cable** for FPGA/sensor configuration
5. **Connect SPI cable** to IMU (if using)
6. **Apply power** (5V)

## Software Installation

### Prerequisites

- JetPack 5.x or later
- CUDA Toolkit
- CMake 3.18+
- GCC/G++ toolchain

### Build Instructions

```bash
# Clone repository
git clone https://github.com/your-org/chronos.git
cd chronos

# Build kernel modules
cd drivers
make all
sudo make install

# Build application
cd ../app
mkdir build && cd build
cmake ..
make -j$(nproc)
sudo make install

# Load modules
sudo modprobe ov9281
sudo modprobe chronos_csi
sudo modprobe bmi088_chronos
```

### Device Tree Installation

```bash
# Compile overlay
dtc -I dts -O dtb -o chronos-orin-nx.dtbo drivers/chronos-orin-nx.dts

# Install overlay
sudo cp chronos-orin-nx.dtbo /boot/

# Add to extlinux.conf
sudo nano /boot/extlinux/extlinux.conf
# Add: FDT /boot/chronos-orin-nx.dtbo

# Reboot
sudo reboot
```

## Running the Demo Application

### Basic Usage

```bash
# Run demo with default settings (30 fps)
chronos_demo

# Run at 120 fps
chronos_demo --rate 120

# Run with custom exposure
chronos_demo --rate 60 --exposure 2000

# Run headless (no display)
chronos_demo --headless --duration 60
```

### Command Line Options

| Option | Description | Default |
|---|---|---|
| `-r, --rate <fps>` | Frame rate (1-120) | 30 |
| `-e, --exposure <us>` | Exposure time (µs) | 5000 |
| `-g, --gain <dB>` | Analog gain | 0.0 |
| `-d, --duration <sec>` | Run duration (0=infinite) | 0 |
| `-n, --no-imu` | Disable IMU | enabled |
| `-H, --headless` | No display | disabled |

### Expected Output

```
Chronos Demo - 4-Camera Synchronized Capture
=============================================
Frame Rate: 60 fps
Exposure: 5000 us
Gain: 0.0 dB

Press Ctrl+C to stop...

FPS: 60.0  Sync: 1234  
  IMU: Accel[  0.02,  -0.01,   9.81] m/s²  Gyro[  0.00,   0.00,   0.00] rad/s
  Frame Sync: Cam0:1234 Cam1:1234 Cam2:1234 Cam3:1234 [SYNC OK]
```

## Synchronization Testing

### Running Sync Test

```bash
# Run sync validation
sync_test -n 1000 -r 120

# Verbose output
sync_test -n 500 -r 60 -v
```

### Expected Results

```
=== SYNCHRONIZATION TEST RESULTS ===

Inter-Camera Skew (all 4 cameras):
  Samples:    1000
  Mean:       42.123 us
  Std Dev:    8.456 us
  Min:        28.100 us
  Max:        89.200 us
  99th %ile:  76.400 us
  RESULT:     PASS (requirement: <100 us)

Frame Interval (frame-to-frame timing):
  Expected:   8333.333 us
  Mean:       8334.125 us
  Std Dev:    12.345 us
  Min:        8310.000 us
  Max:        8360.000 us
  Error:      0.01%
  RESULT:     PASS (requirement: <1% error)

=== OVERALL: ALL TESTS PASSED ===
```

## Troubleshooting

### Common Issues

#### No Video Devices

**Symptom**: `/dev/video*` devices not created

**Solutions**:
1. Check device tree overlay is loaded
2. Verify CSI cable connection
3. Check kernel module is loaded: `lsmod | grep chronos`
4. Check dmesg for errors: `dmesg | grep chronos`

#### Sync Failures

**Symptom**: "SYNC FAIL" messages

**Solutions**:
1. Reduce frame rate
2. Check all camera connections
3. Verify FPGA trigger is enabled
4. Check for I2C communication errors

#### CUDA Errors

**Symptom**: `CHRONOS_ERROR_CUDA`

**Solutions**:
1. Ensure CUDA is properly installed
2. Check GPU memory availability: `nvidia-smi`
3. Reduce buffer count if memory limited

#### Low Frame Rate

**Symptom**: Actual FPS lower than configured

**Solutions**:
1. Reduce exposure time
2. Check for buffer overruns in stats
3. Ensure no other processes using CSI/VI

### Debug Commands

```bash
# Check loaded modules
lsmod | grep -E "ov9281|chronos|bmi088"

# View kernel messages
dmesg | tail -50

# Check video devices
v4l2-ctl --list-devices

# Query camera capabilities
v4l2-ctl -d /dev/video0 --all

# Check FPGA status (via I2C)
i2cget -y 2 0x3c 0x20  # Status register
i2cget -y 2 0x3c 0xf0  # Firmware version

# Monitor IMU
cat /sys/bus/iio/devices/iio:device0/in_accel_x_raw
```

## Performance Tuning

### Optimizing for Low Latency

1. Use callback mode instead of polling
2. Keep exposure time short
3. Use triple buffering (default)
4. Process on GPU immediately

### Optimizing for High Throughput

1. Use maximum frame rate (120 fps)
2. Ensure adequate GPU memory
3. Use batch CUDA processing
4. Monitor buffer overruns

### Power Optimization

1. Reduce frame rate when possible
2. Disable unused cameras
3. Use shorter exposure times

## Calibration

### Camera Synchronization Calibration

The FPGA supports per-camera trigger delay adjustment:

```bash
# Set camera 1 delay (in clock cycles)
i2cset -y 2 0x3c 0x11 0x10

# Verify
i2cget -y 2 0x3c 0x11
```

### IMU Alignment

The IMU mount matrix can be configured in the device tree to match physical orientation.

## Contact and Support

For technical support:
- Email: support@chronos-project.com
- GitHub Issues: https://github.com/your-org/chronos/issues

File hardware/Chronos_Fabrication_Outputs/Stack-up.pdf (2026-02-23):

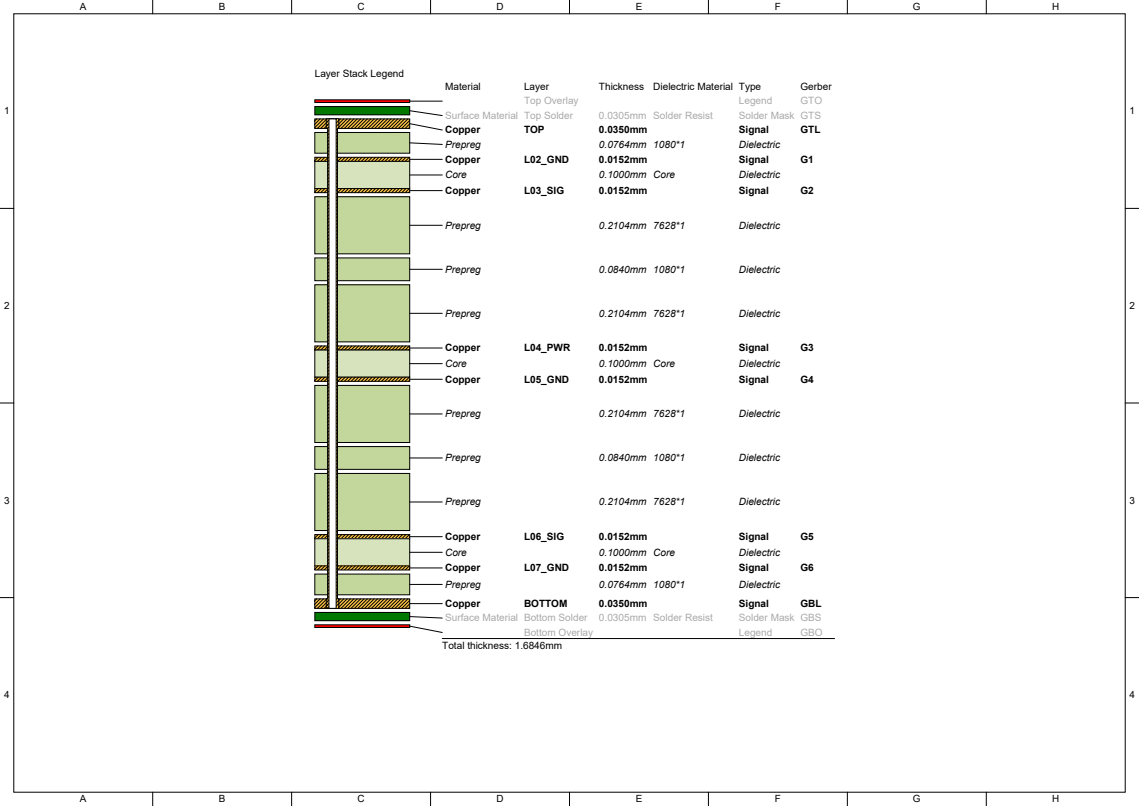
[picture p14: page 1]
Material; Layer; Thickness Dielectric Material Type; Gerber; Top Overlay; Legend; GTO; Surface Material Top Solder; 0.0305mm Solder Resist; Solder Mask GTS; Copper; TOP; Signal; GTL; Prepreg; Dielectric; L02_GND; Core; 0.1000mm Core; L03_SIG; L04_PWR; L05_GND; L06_SIG; L07_GND; BOTTOM; GBL; Surface Material Bottom Solder 0.0305mm Solder Resist; Solder Mask GBS; Bottom Overlay; GBO; Total thickness: 1.6846mm

Layer Stack Legend

1 | 1
2 | 2
3 | 3
4 | 4

Impedance Id
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
Transmission Line
Coated Microstrip
Edge-Coupled Coated Microstrip Edge-Coupled Coated Microstrip Coated Microstrip
Offset Stripline
Edge-Coupled Offset Stripline Edge-Coupled Offset Stripline Offset Stripline
Offset Stripline
Edge-Coupled Offset Stripline Edge-Coupled Offset Stripline Offset Stripline
Offset Stripline
Edge-Coupled Offset Stripline Edge-Coupled Offset Stripline Offset Stripline
Offset Stripline
Edge-Coupled Offset Stripline Edge-Coupled Offset Stripline Offset Stripline
Coated Microstrip
Edge-Coupled Coated Microstrip Edge-Coupled Coated Microstrip Coated Microstrip

Target Impedance
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
Calculated Impedance
50.70
95.73
88.21
46.01
50.98
95.59
88.98
46.52
50.90
95.42
88.84
46.46
50.90
95.42
88.84
46.46
50.98
95.59
88.98
46.52
50.71
95.73
88.21
46.01

Trace layer
TOP
TOP
TOP
TOP
L03_SIG
L03_SIG
L03_SIG
L03_SIG
L04_PWR
L04_PWR
L04_PWR
L04_PWR
L05_GND
L05_GND
L05_GND
L05_GND
L06_SIG
L06_SIG
L06_SIG
L06_SIG
BOTTOM
BOTTOM
BOTTOM
BOTTOM

Wide Trace Width
0.11mm
0.11mm
0.14mm
0.14mm
0.11mm
0.11mm
0.14mm
0.14mm
0.11mm
0.11mm
0.14mm
0.14mm
0.11mm
0.11mm
0.14mm
0.14mm
0.11mm
0.11mm
0.14mm
0.14mm
0.11mm
0.11mm
0.14mm
0.14mm

Narrow Trace Width
0.11mm
0.11mm
0.14mm
0.14mm
0.11mm
0.11mm
0.14mm
0.14mm
0.11mm
0.11mm
0.14mm
0.14mm
0.11mm
0.11mm
0.14mm
0.14mm
0.11mm
0.11mm
0.14mm
0.14mm
0.11mm
0.11mm
0.14mm
0.14mm

Gap

0.25mm
0.30mm

0.25mm
0.30mm

0.25mm
0.30mm

0.25mm
0.30mm

0.25mm
0.30mm

0.25mm
0.30mm

Reference layers
L02_GND
L02_GND
L02_GND
L02_GND
L02_GND,L04_PWR
L02_GND,L04_PWR
L02_GND,L04_PWR
L02_GND,L04_PWR
L03_SIG,L05_GND
L03_SIG,L05_GND
L03_SIG,L05_GND
L03_SIG,L05_GND
L04_PWR,L06_SIG
L04_PWR,L06_SIG
L04_PWR,L06_SIG
L04_PWR,L06_SIG
L05_GND,L07_GND
L05_GND,L07_GND
L05_GND,L07_GND
L05_GND,L07_GND
L07_GND
L07_GND
L07_GND
L07_GND

Substack
Board Layer Stack
Board Layer Stack
Board Layer Stack
Board Layer Stack
Board Layer Stack
Board Layer Stack
Board Layer Stack
Board Layer Stack
Board Layer Stack
Board Layer Stack
Board Layer Stack
Board Layer Stack
Board Layer Stack
Board Layer Stack
Board Layer Stack
Board Layer Stack
Board Layer Stack
Board Layer Stack
Board Layer Stack
Board Layer Stack
Board Layer Stack
Board Layer Stack
Board Layer Stack
Board Layer Stack

Clearance
0.13mm
0.13mm
0.13mm
0.13mm
0.13mm
0.13mm
0.13mm
0.13mm
0.13mm
0.13mm
0.13mm
0.13mm
0.13mm
0.13mm
0.13mm
0.13mm
0.13mm
0.13mm
0.13mm
0.13mm
0.13mm
0.13mm
0.13mm
0.13mm

Target Tolerance
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
Transmission Line Structure Table

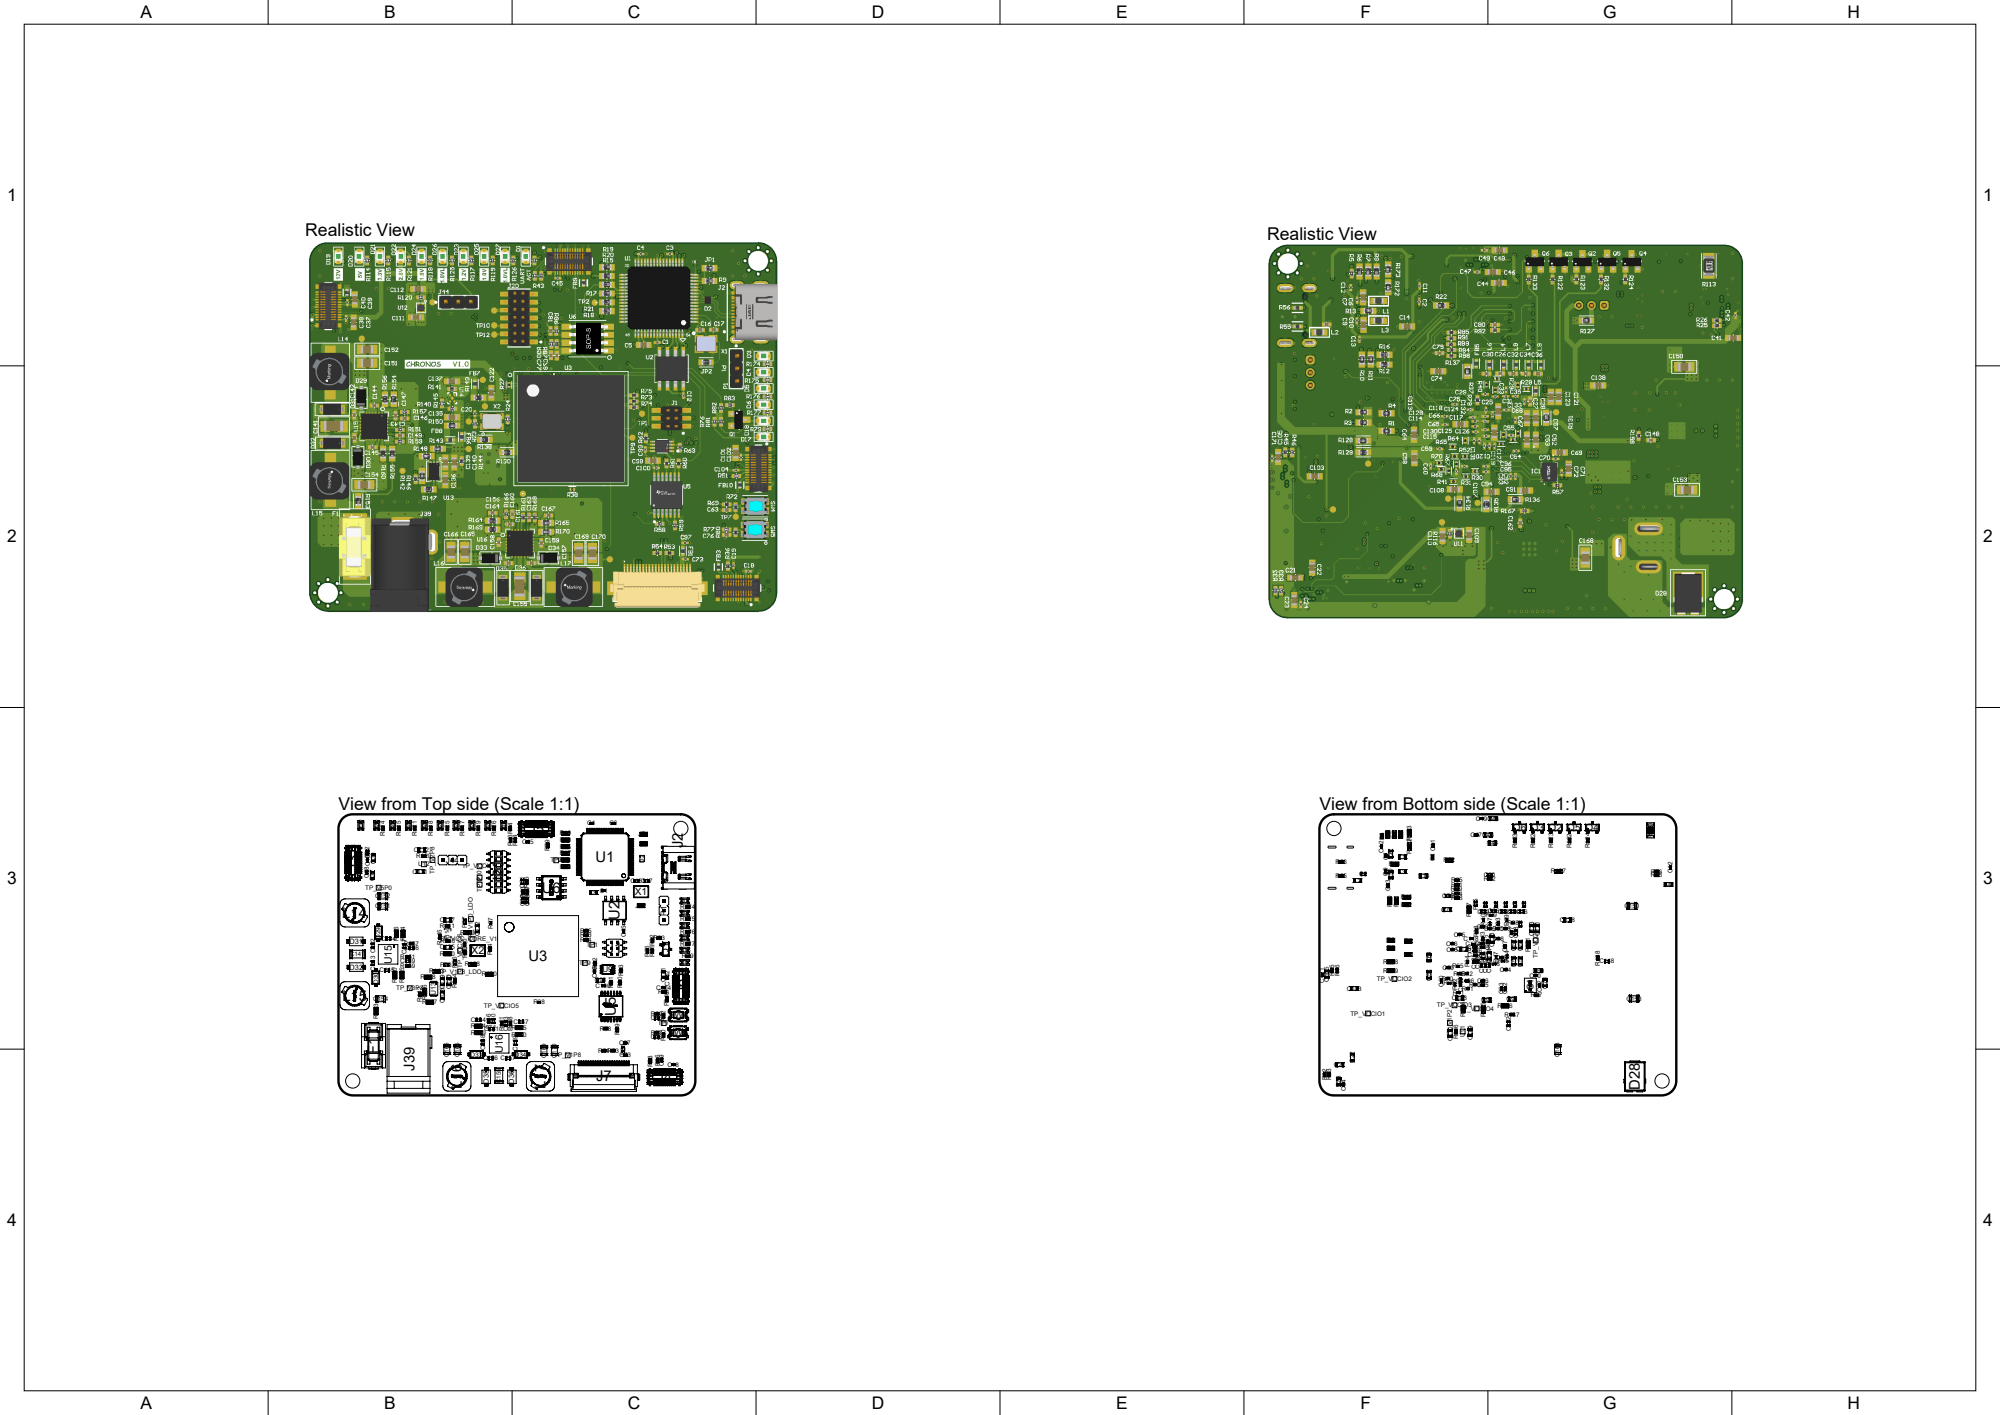
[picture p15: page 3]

View from Top side (Scale 1:1)

View from Bottom side (Scale 1:1)

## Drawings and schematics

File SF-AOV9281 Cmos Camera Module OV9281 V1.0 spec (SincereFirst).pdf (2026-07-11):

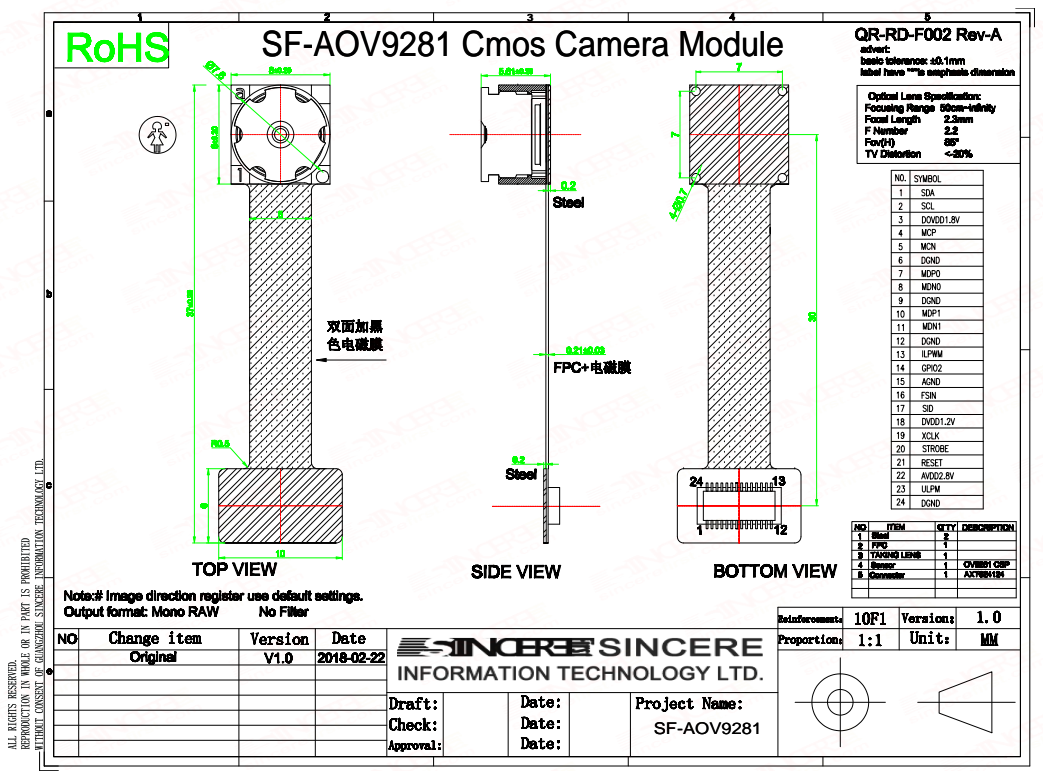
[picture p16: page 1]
SF-AOV9281

SF-AOV9281 Cmos Camera Module

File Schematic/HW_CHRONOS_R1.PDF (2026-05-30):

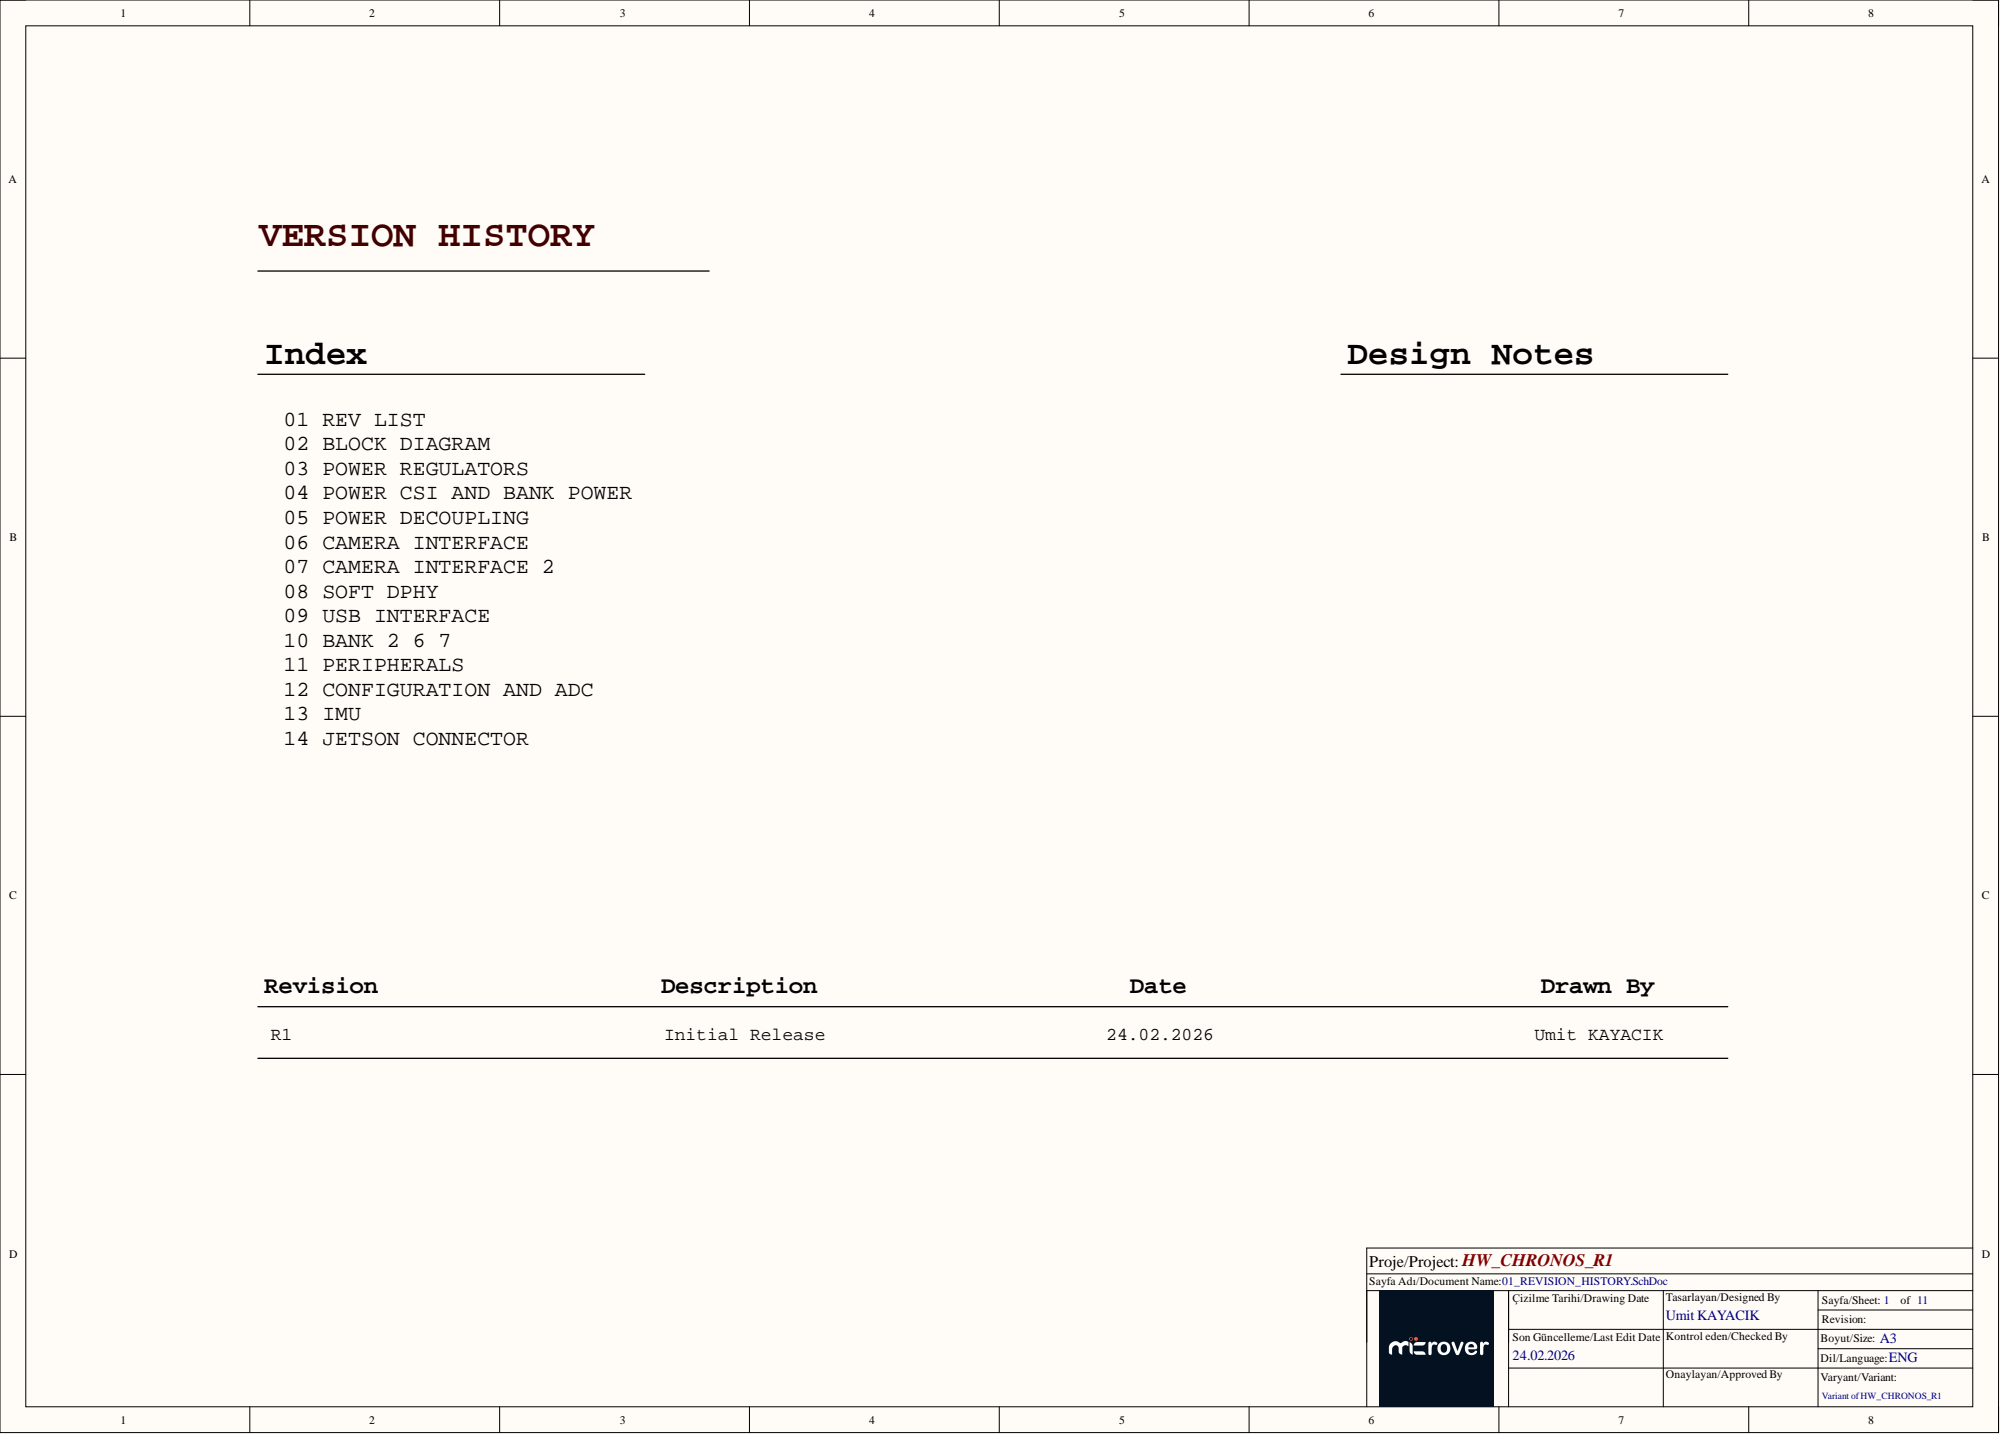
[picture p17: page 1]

01 REV LIST
02 BLOCK DIAGRAM
03 POWER REGULATORS
04 POWER CSI AND BANK POWER
05 POWER DECOUPLING
06 CAMERA INTERFACE
07 CAMERA INTERFACE 2
08 SOFT DPHY
09 USB INTERFACE
10 BANK 2 6 7
11 PERIPHERALS
12 CONFIGURATION AND ADC
13 IMU
14 JETSON CONNECTOR

Sayfa Adı/Document Name:

01_REVISION_HISTORY.SchDoc
Çizilme Tarihi/Drawing Date

Son Güncelleme/Last Edit Date

Kontrol eden/Checked By

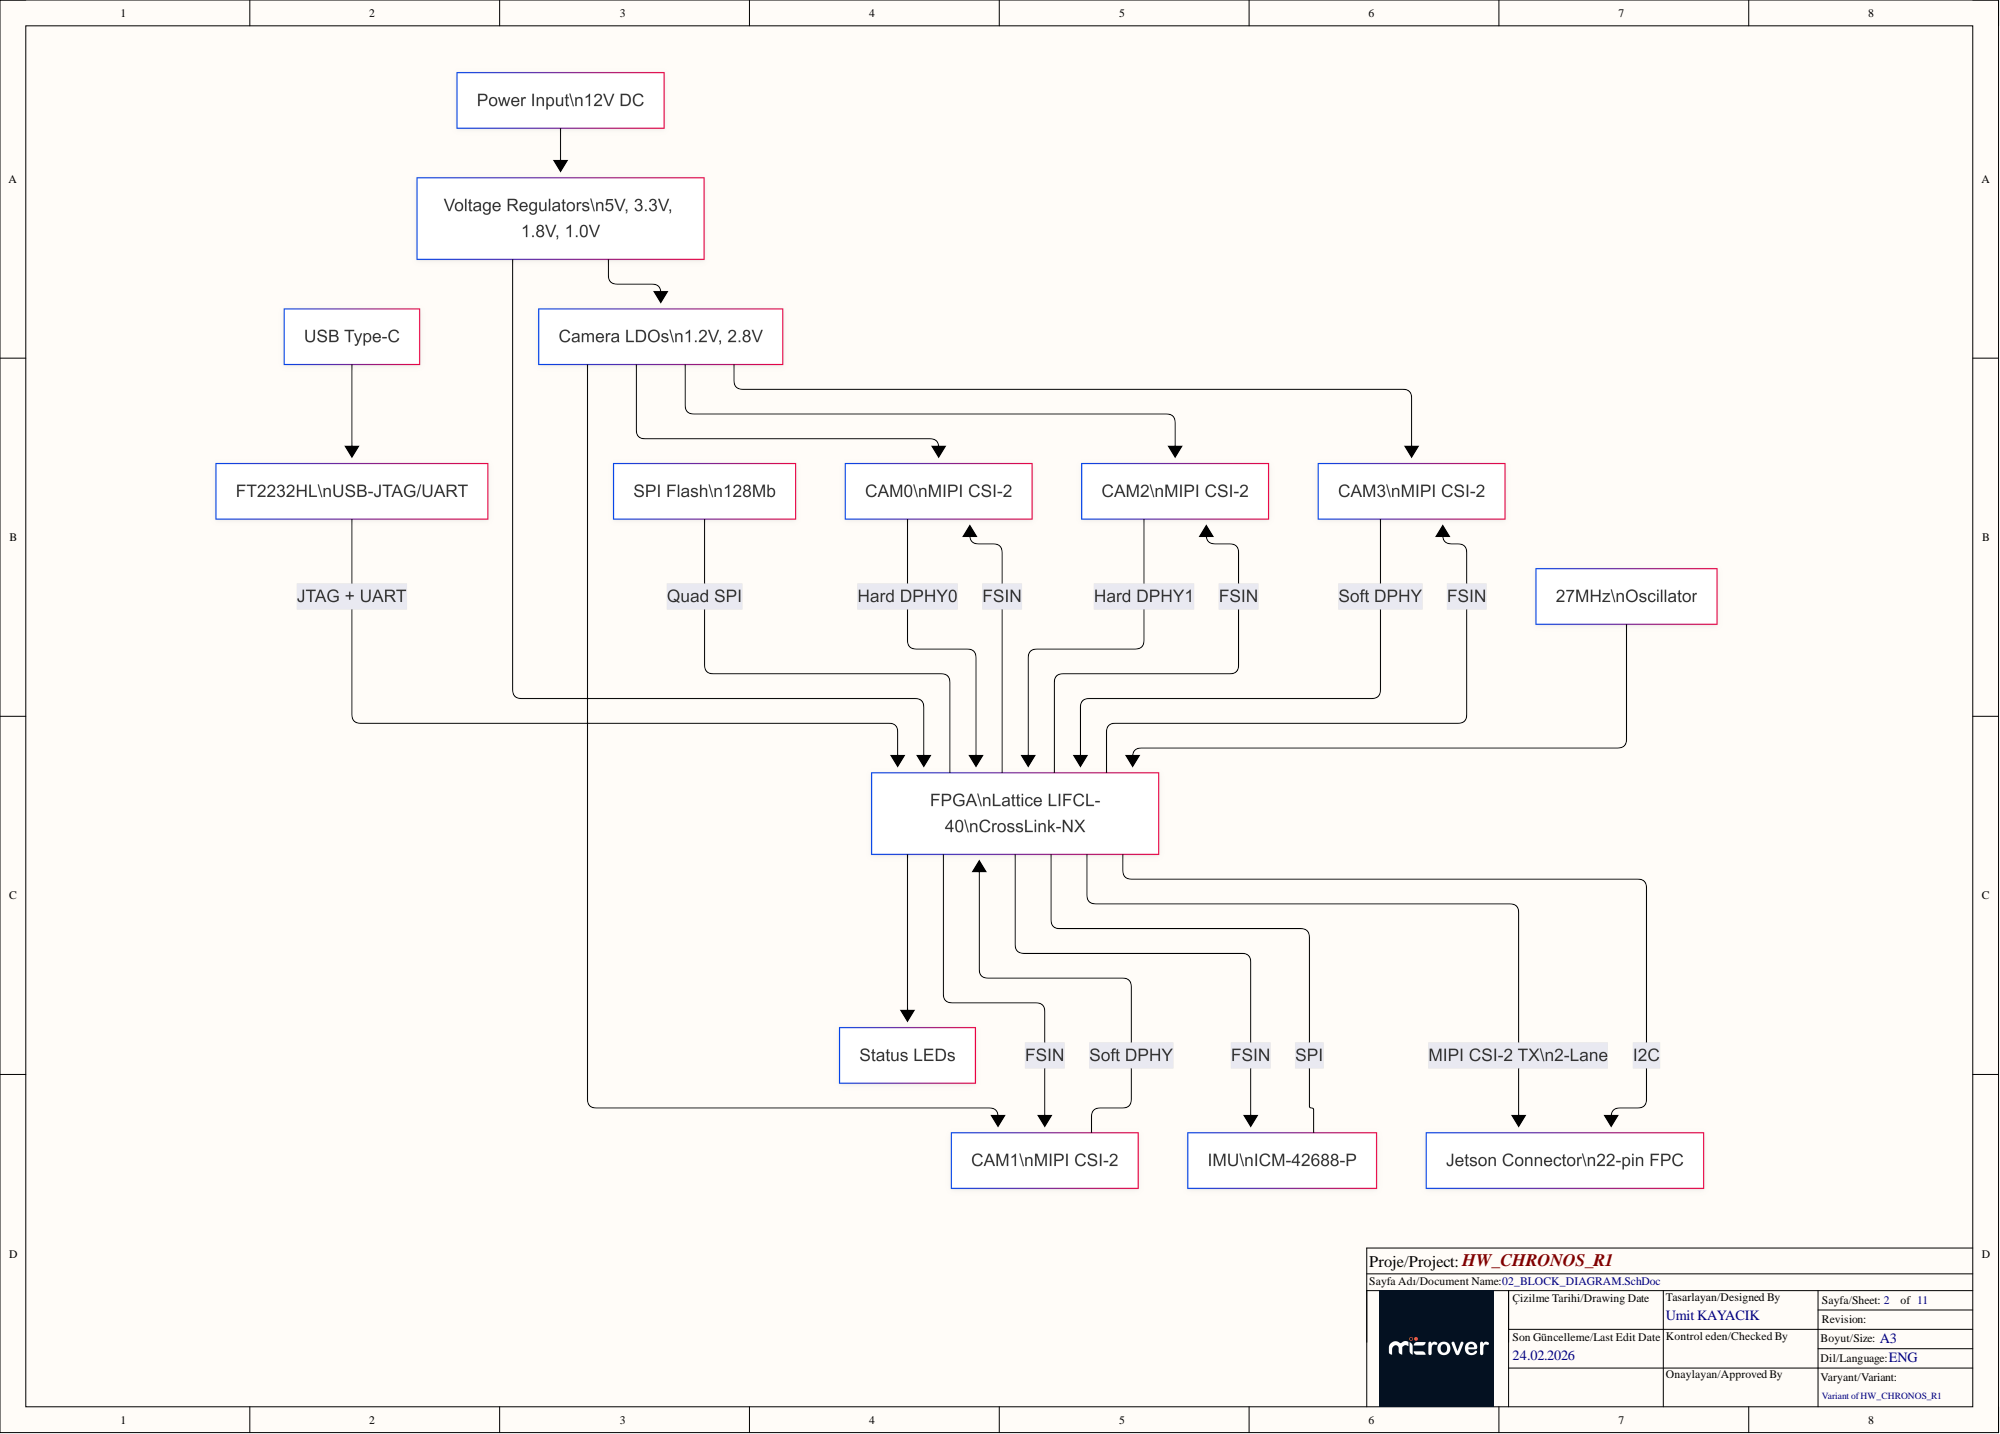
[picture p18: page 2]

Sayfa Adı/Document Name:

02_BLOCK_DIAGRAM.SchDoc
Çizilme Tarihi/Drawing Date

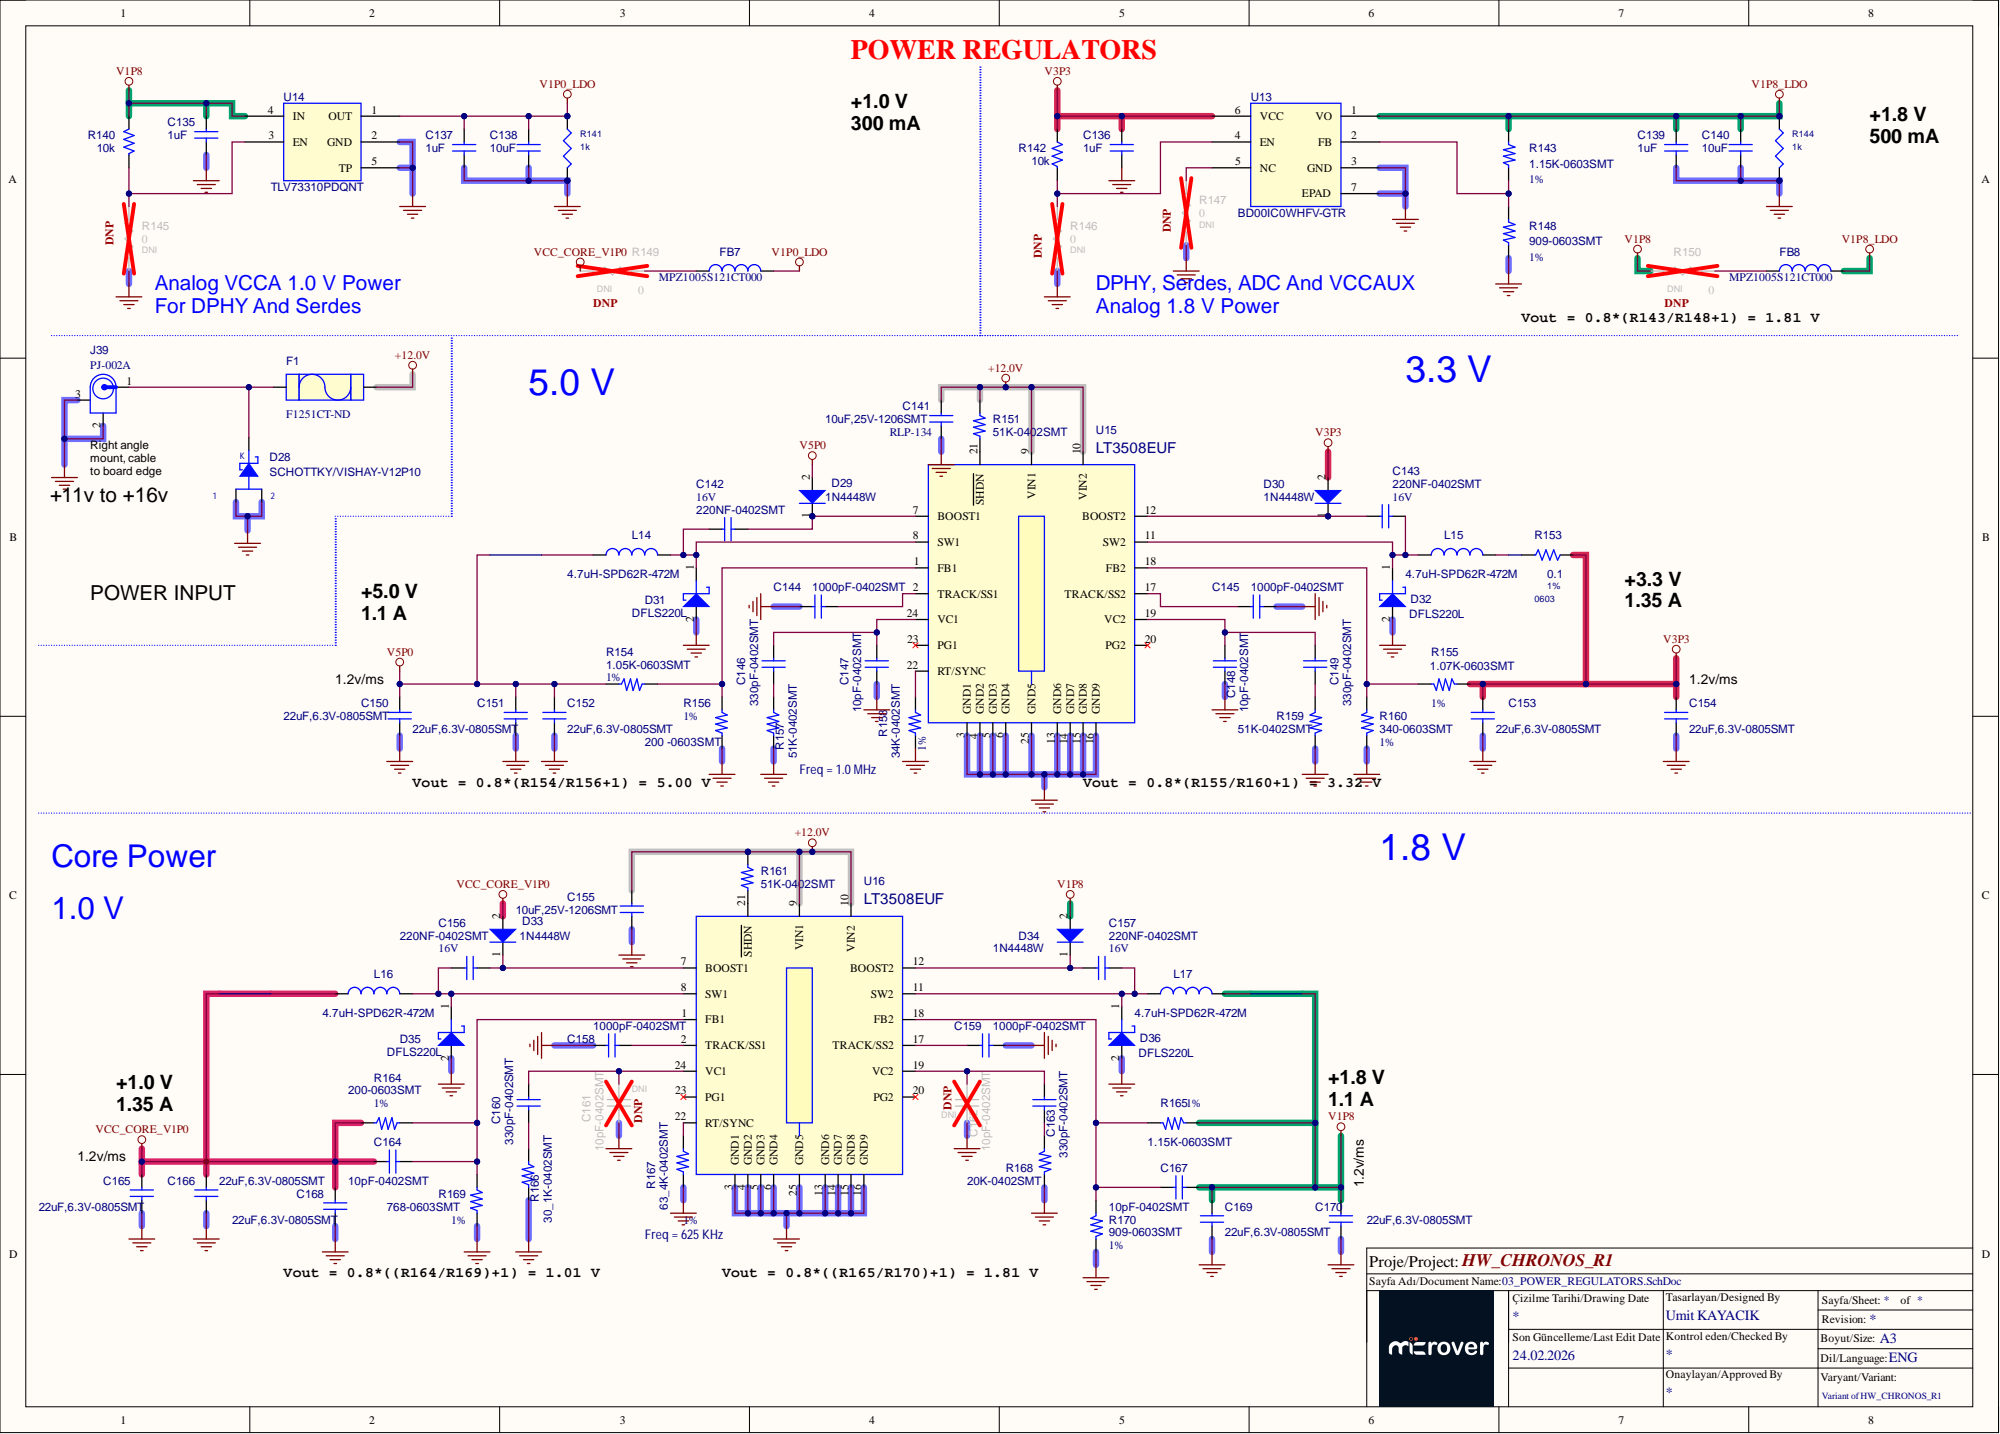
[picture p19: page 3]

Sayfa Adı/Document Name:

03_POWER_REGULATORS.SchDoc
Çizilme Tarihi/Drawing Date

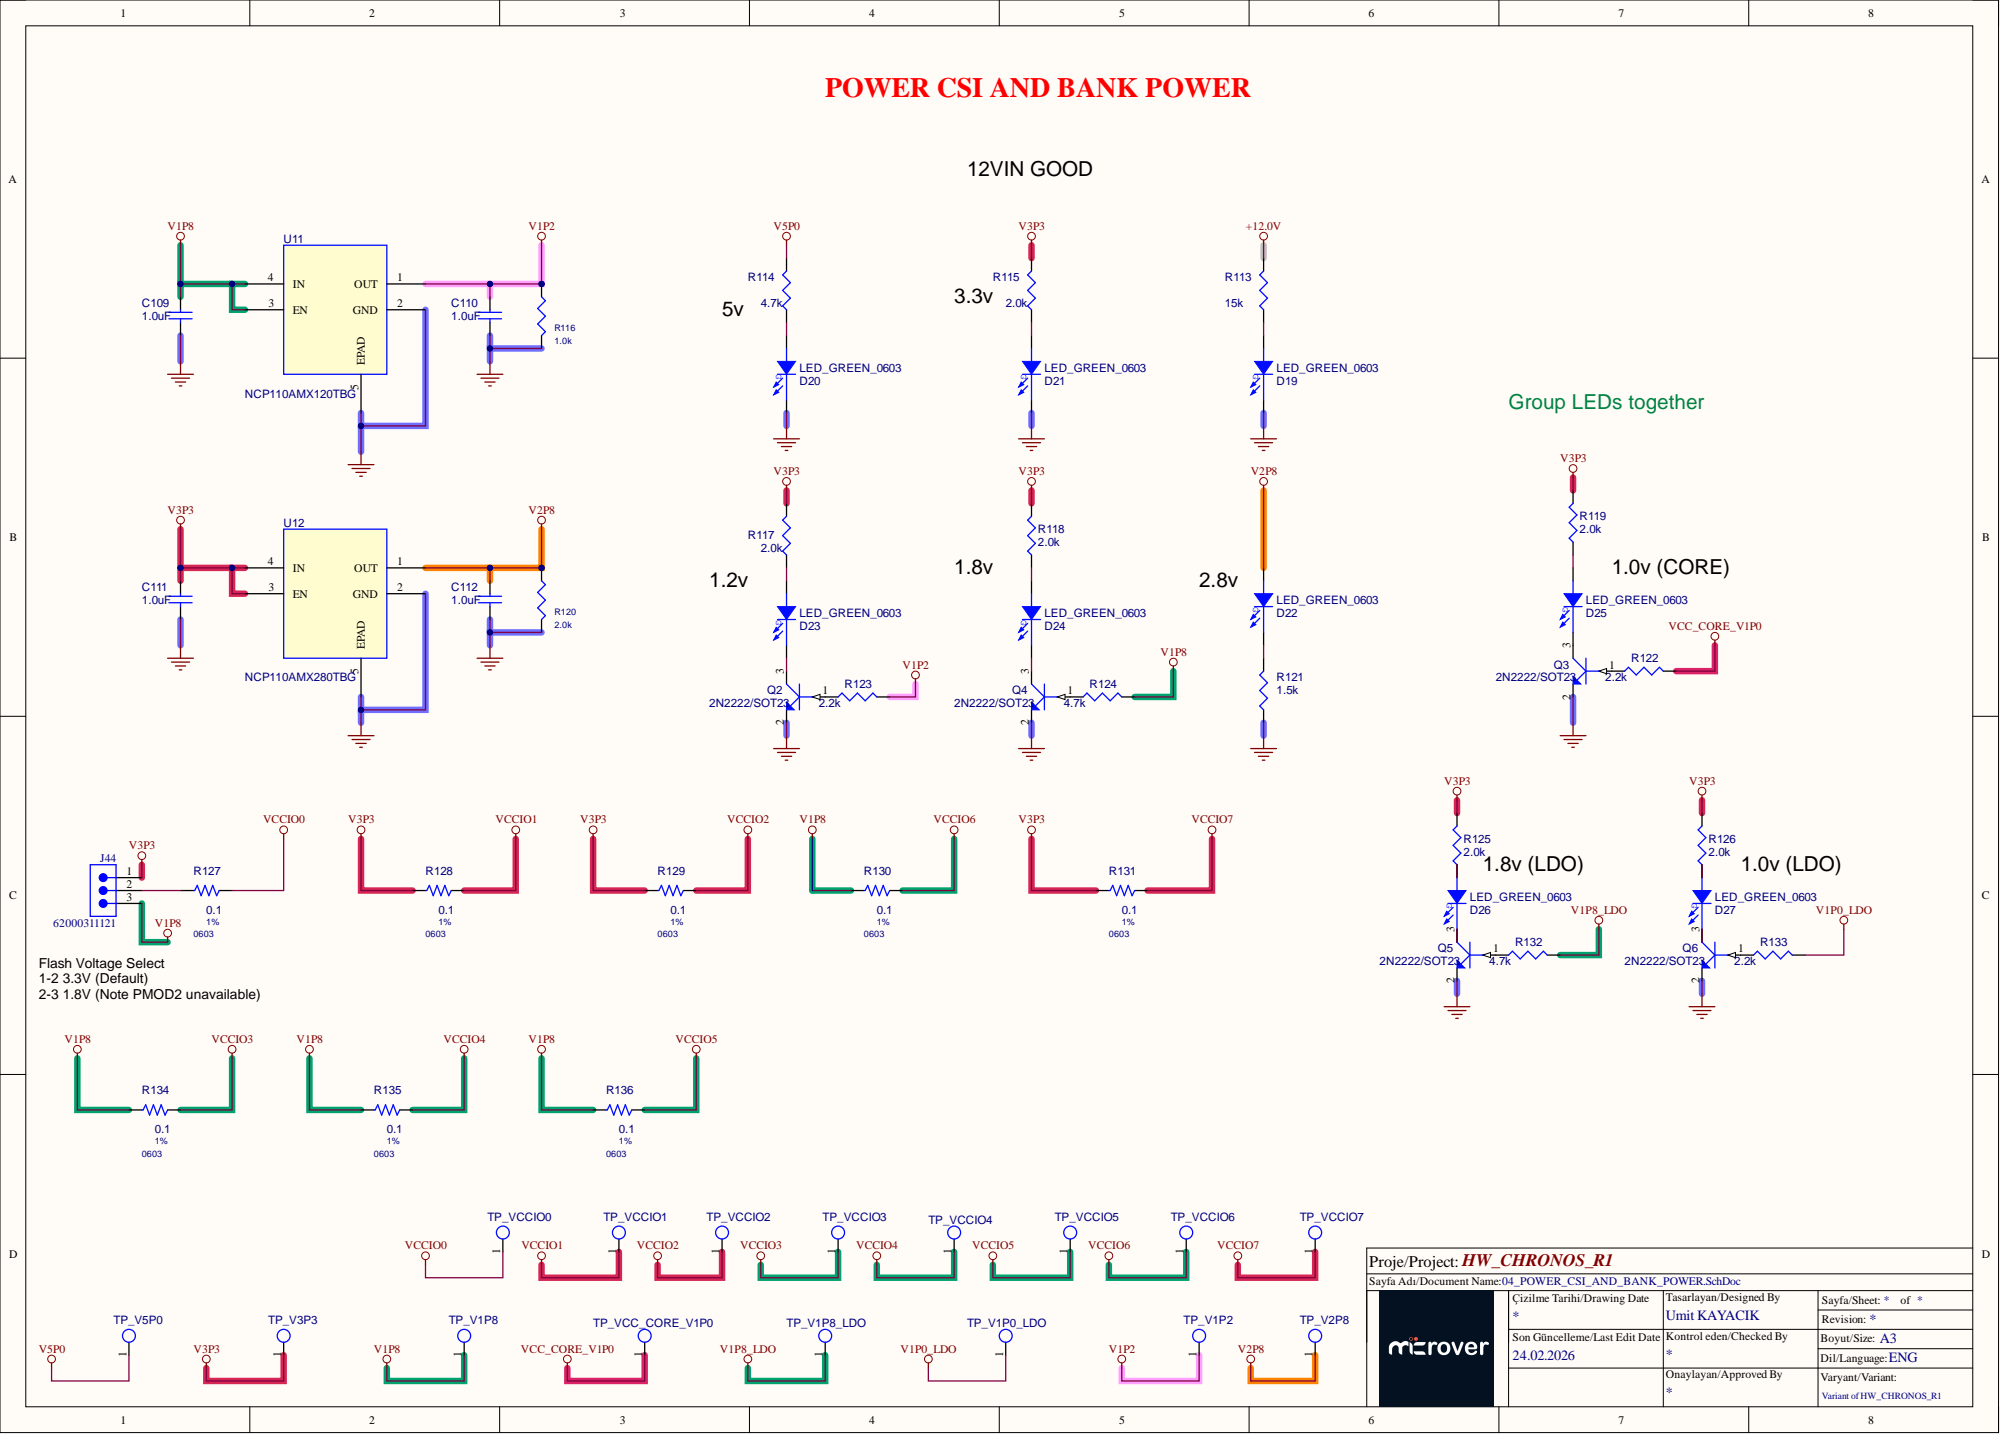
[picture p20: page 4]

POWER CSI AND BANK POWER

Sayfa Adı/Document Name:

04_POWER_CSI_AND_BANK_POWER.SchDoc
Çizilme Tarihi/Drawing Date

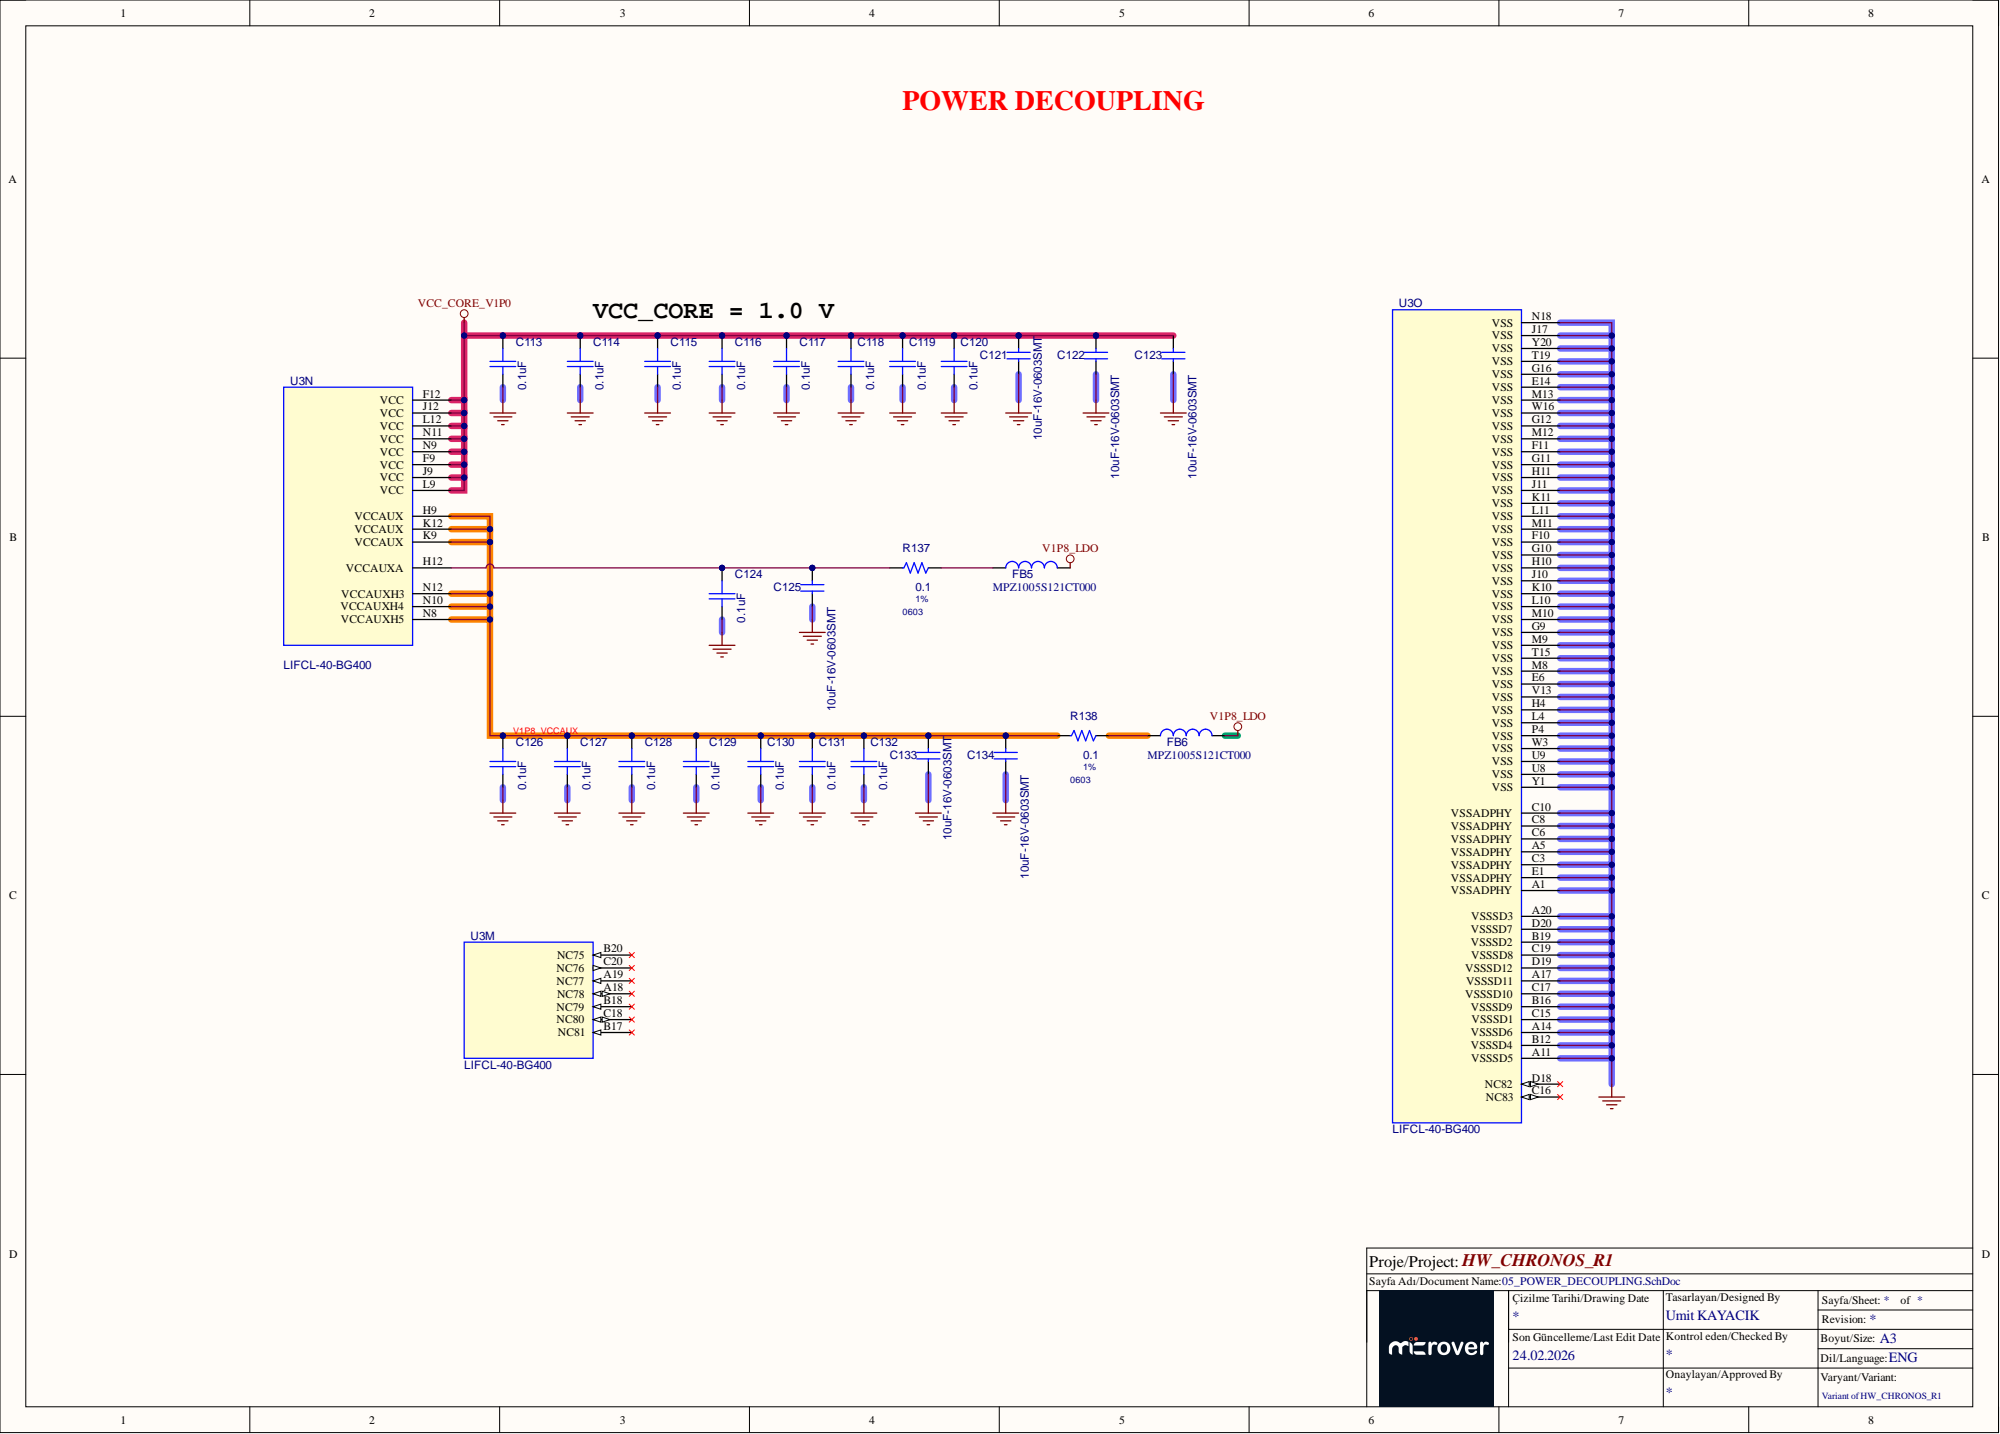
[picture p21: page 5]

Sayfa Adı/Document Name:

05_POWER_DECOUPLING.SchDoc
Çizilme Tarihi/Drawing Date

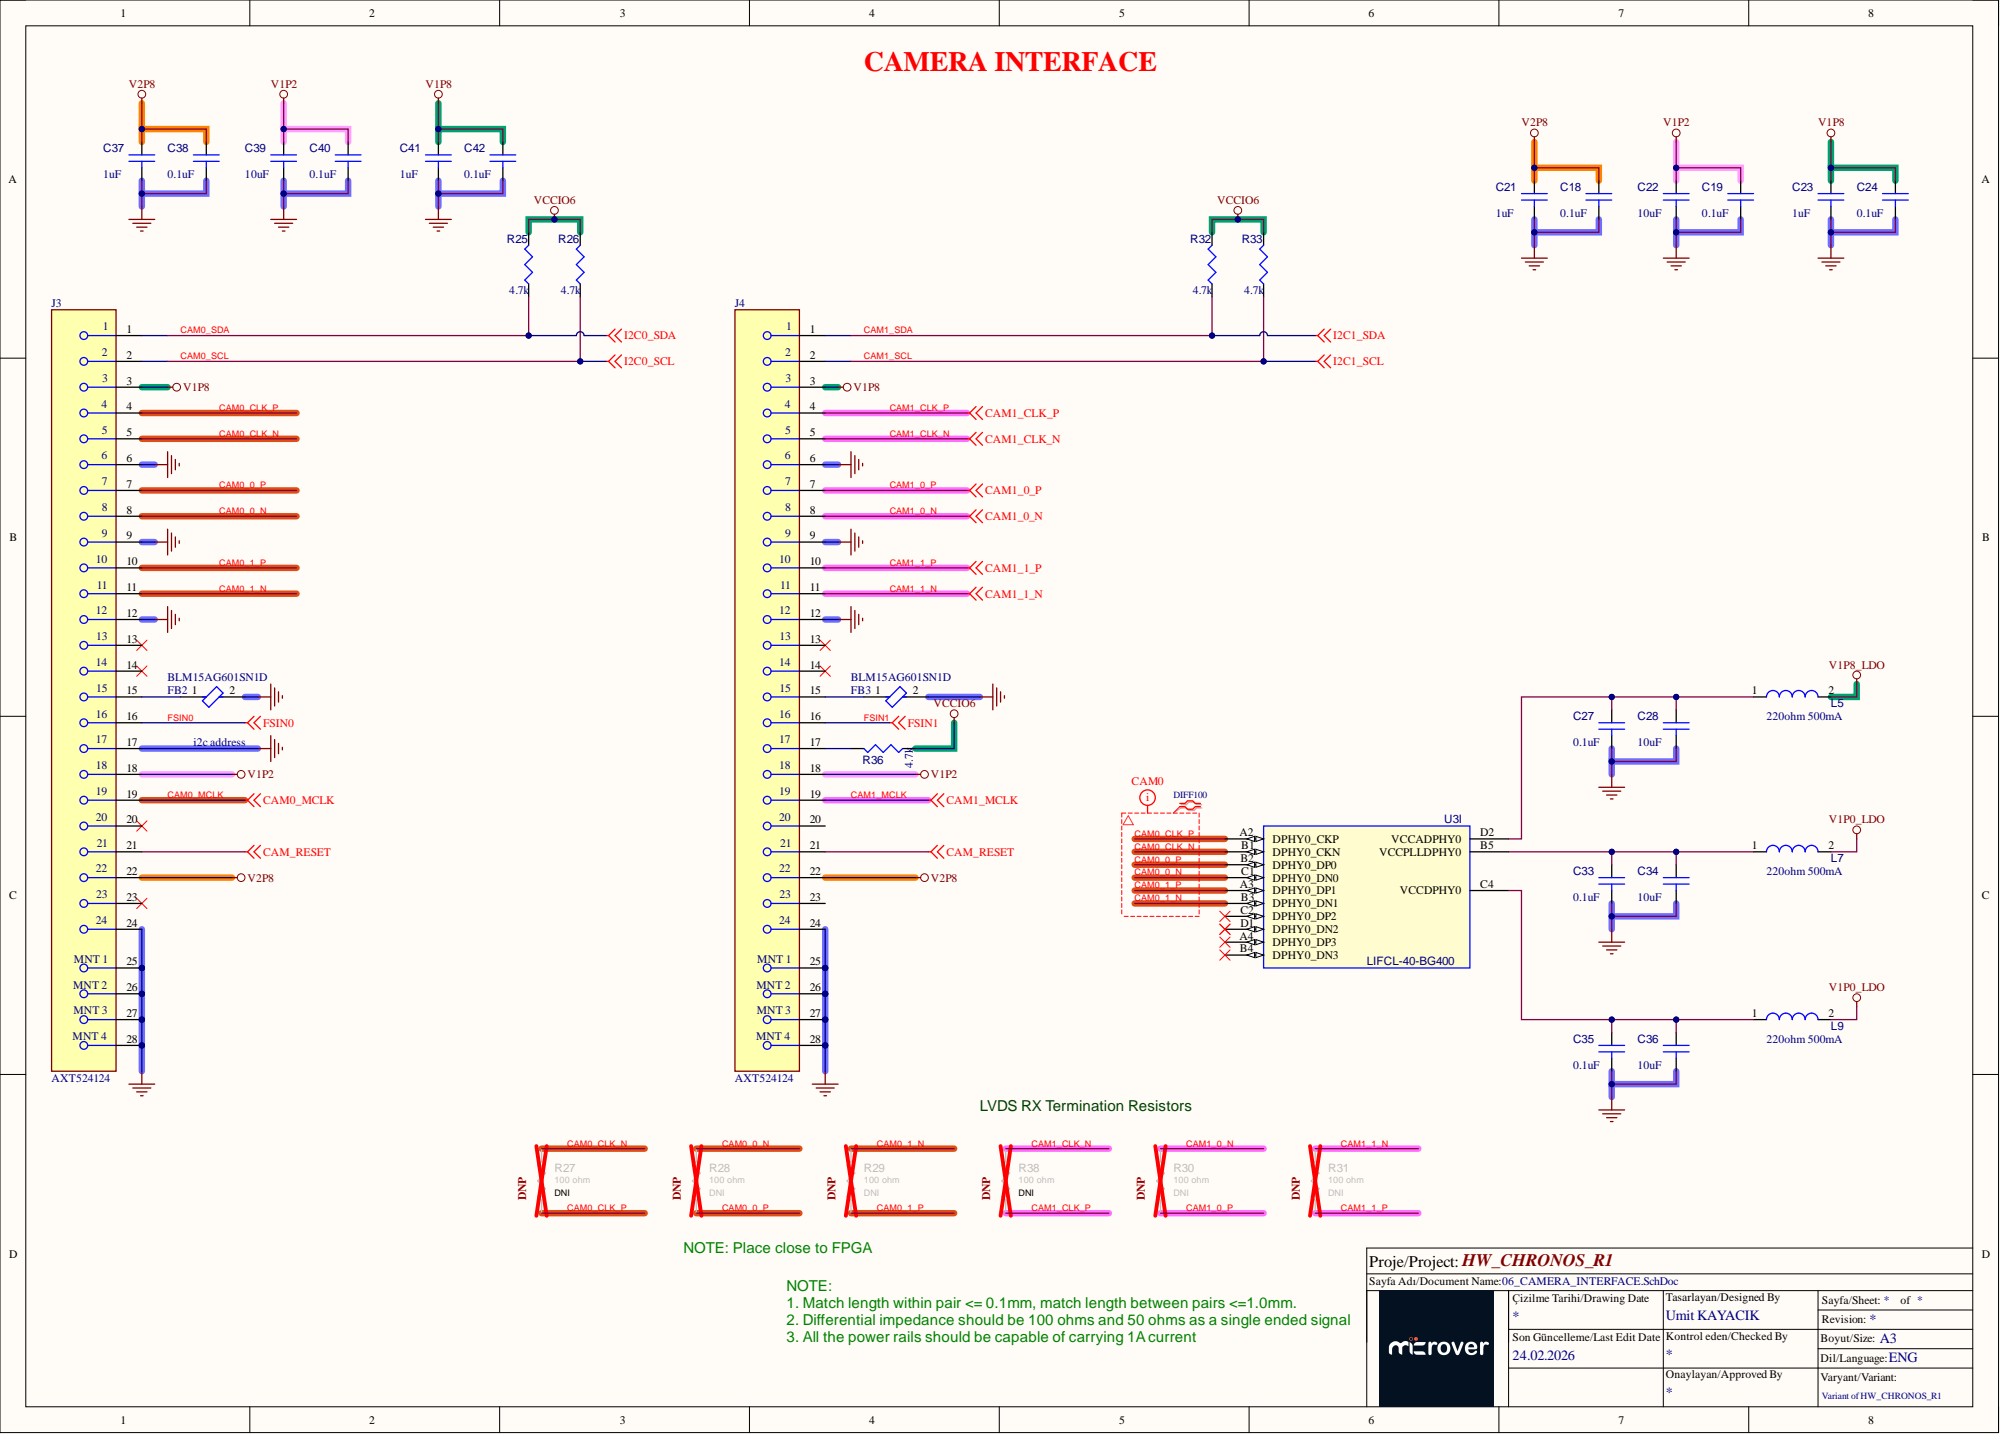
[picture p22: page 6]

LVDS RX Termination Resistors

NOTE: Place close to FPGA

NOTE:
1. Match length within pair <= 0.1mm, match length between pairs <=1.0mm.
2. Differential impedance should be 100 ohms and 50 ohms as a single ended signal
3. All the power rails should be capable of carrying 1Acurrent

Sayfa Adı/Document Name:

06_CAMERA_INTERFACE.SchDoc
Çizilme Tarihi/Drawing Date

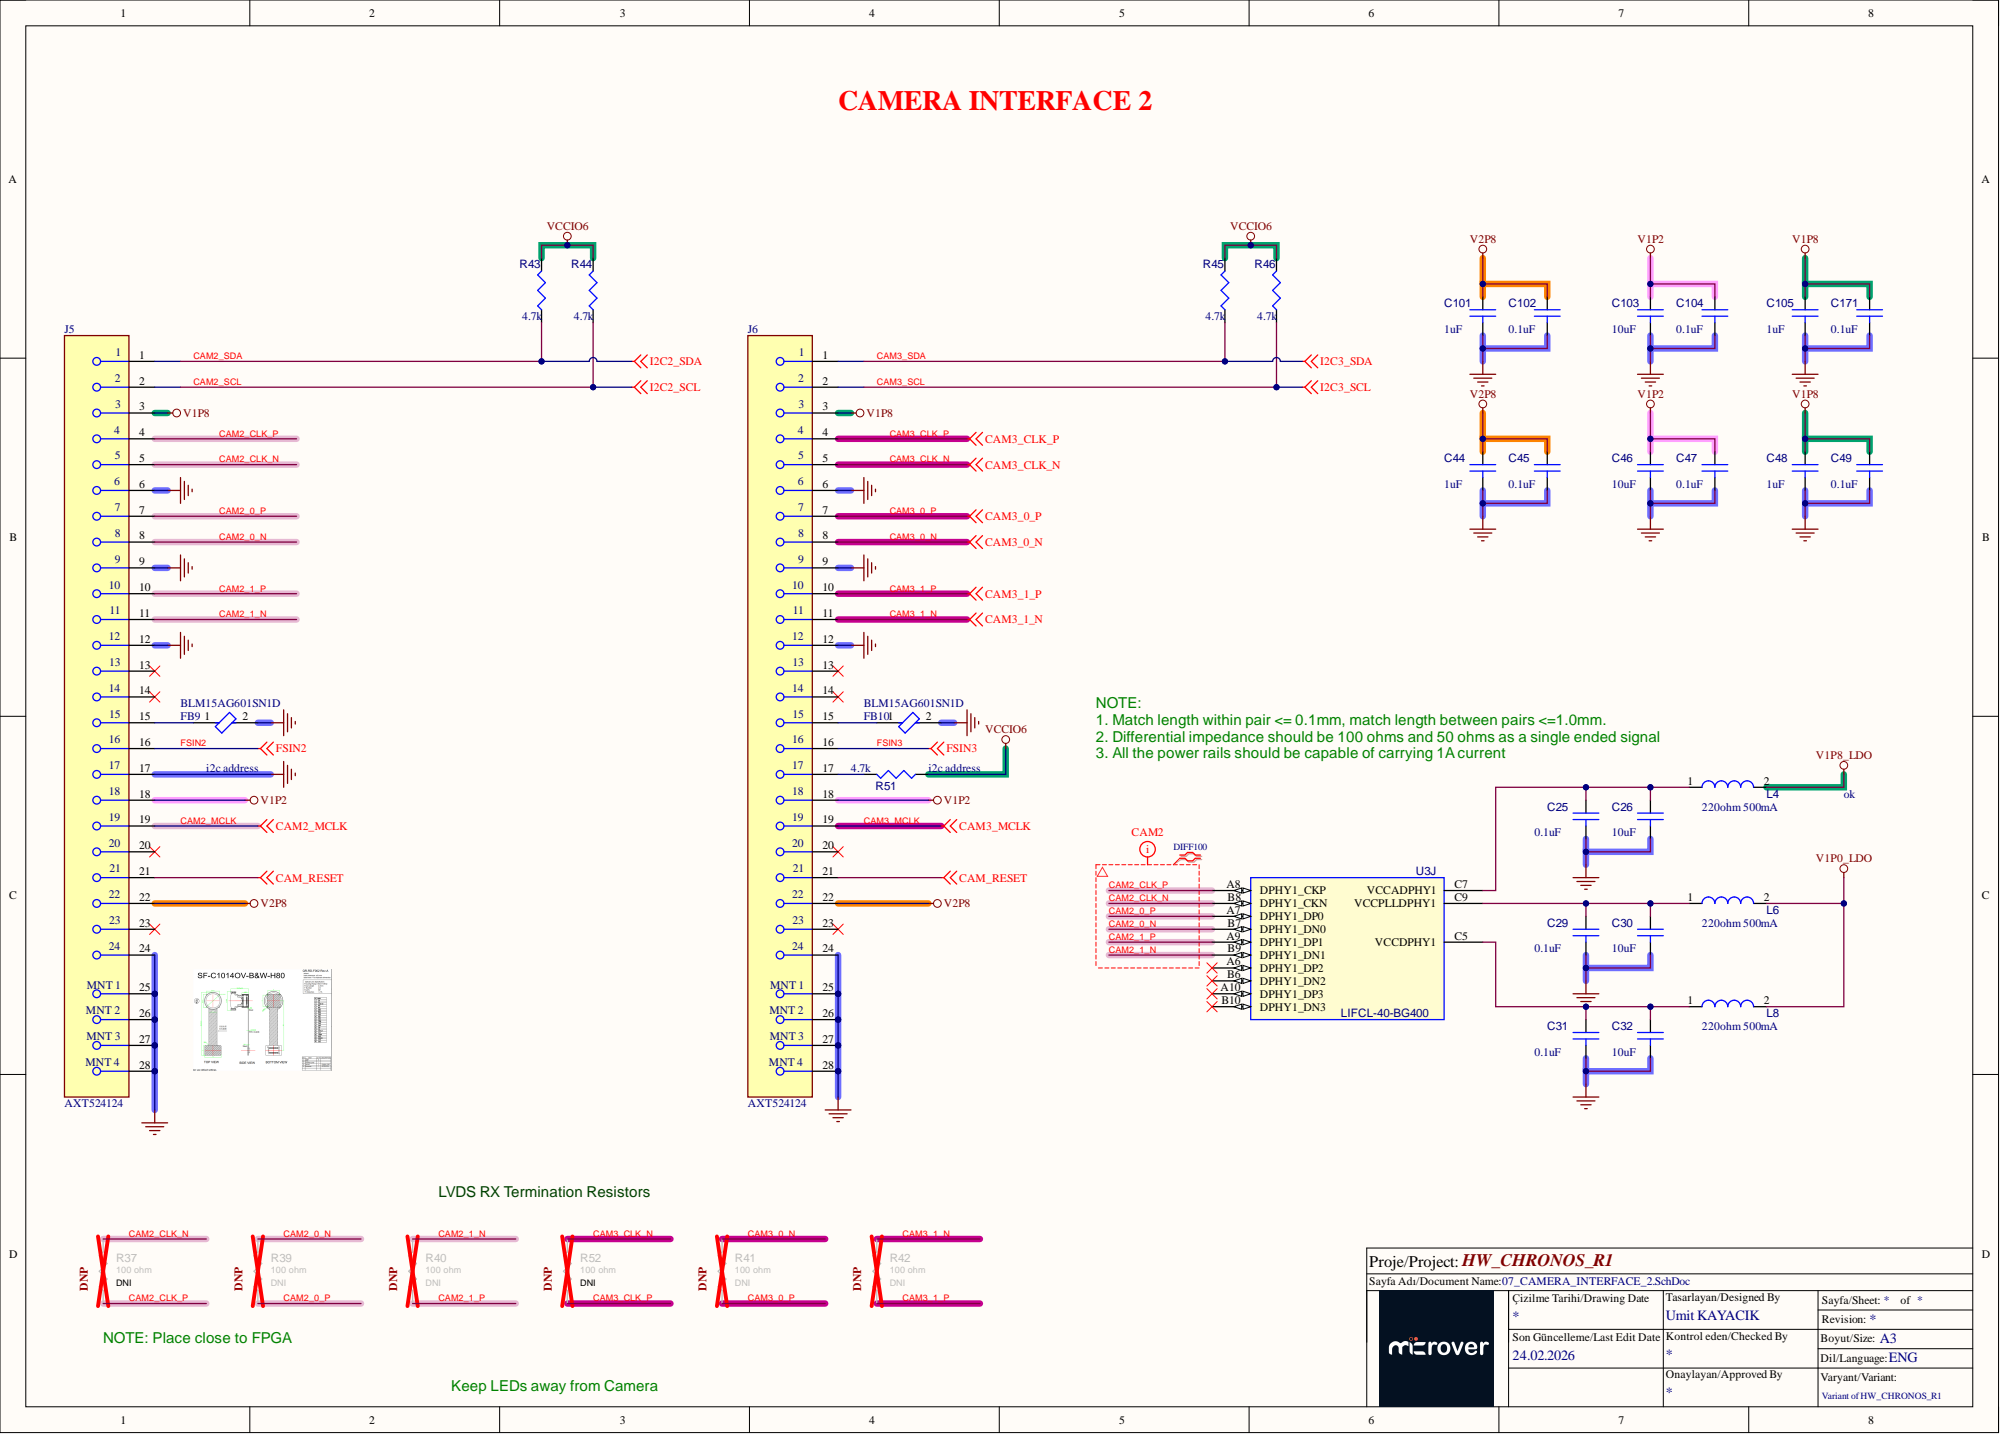
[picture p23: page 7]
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

LVDS RX Termination Resistors

Sayfa Adı/Document Name:

07_CAMERA_INTERFACE_2.SchDoc
Çizilme Tarihi/Drawing Date

NOTE: Place close to FPGA

Keep LEDs away from Camera

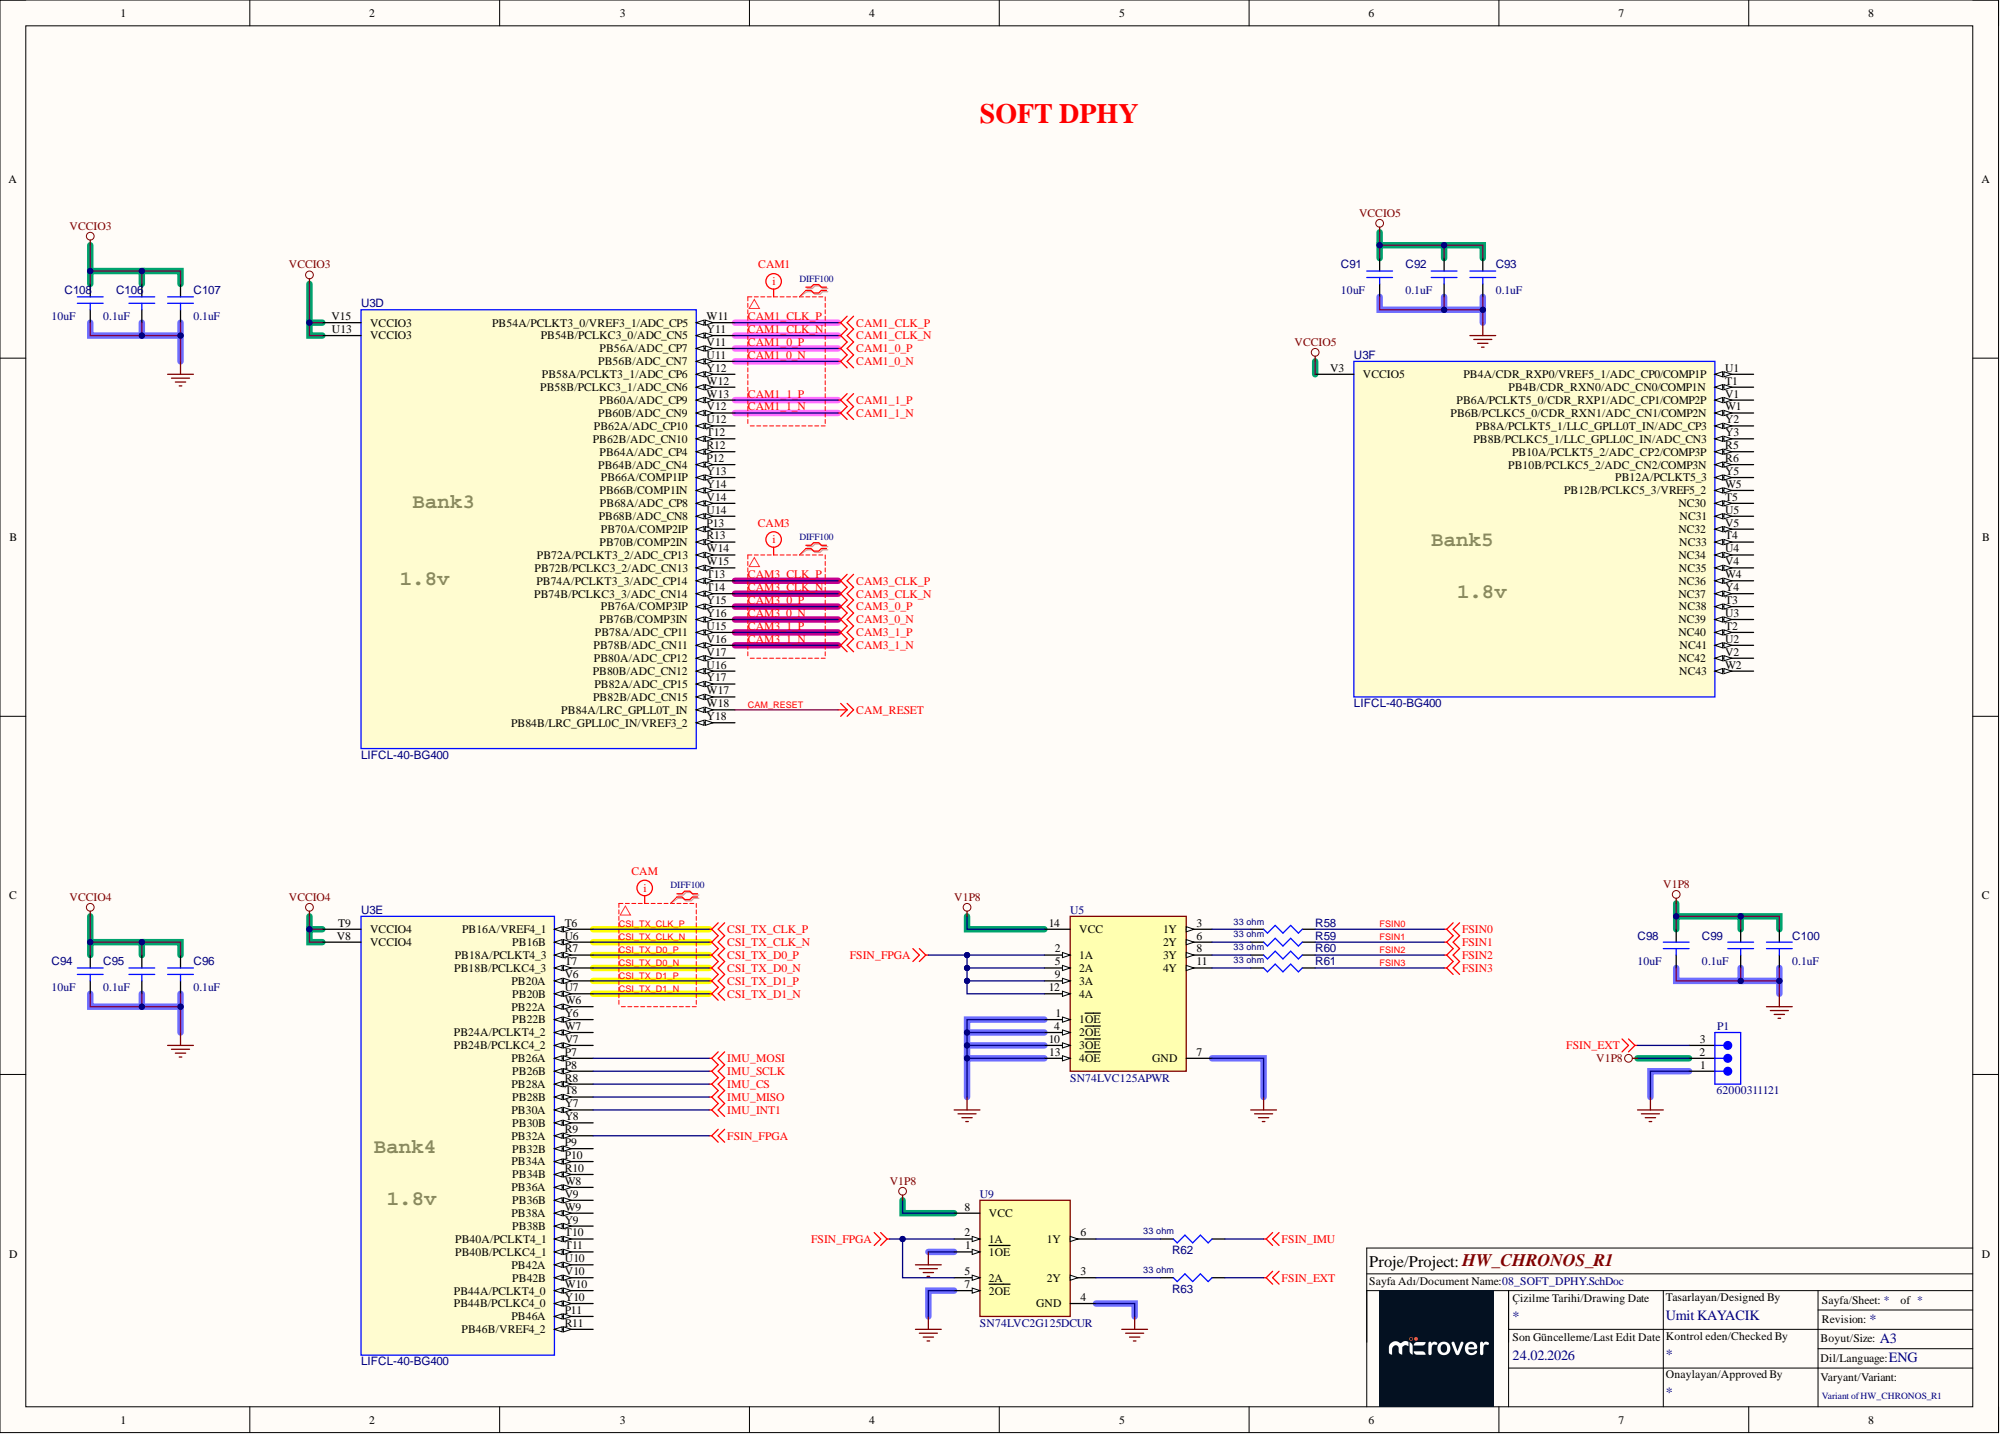
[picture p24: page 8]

2A 5
3A 9

Sayfa Adı/Document Name:

08_SOFT_DPHY.SchDoc
Çizilme Tarihi/Drawing Date

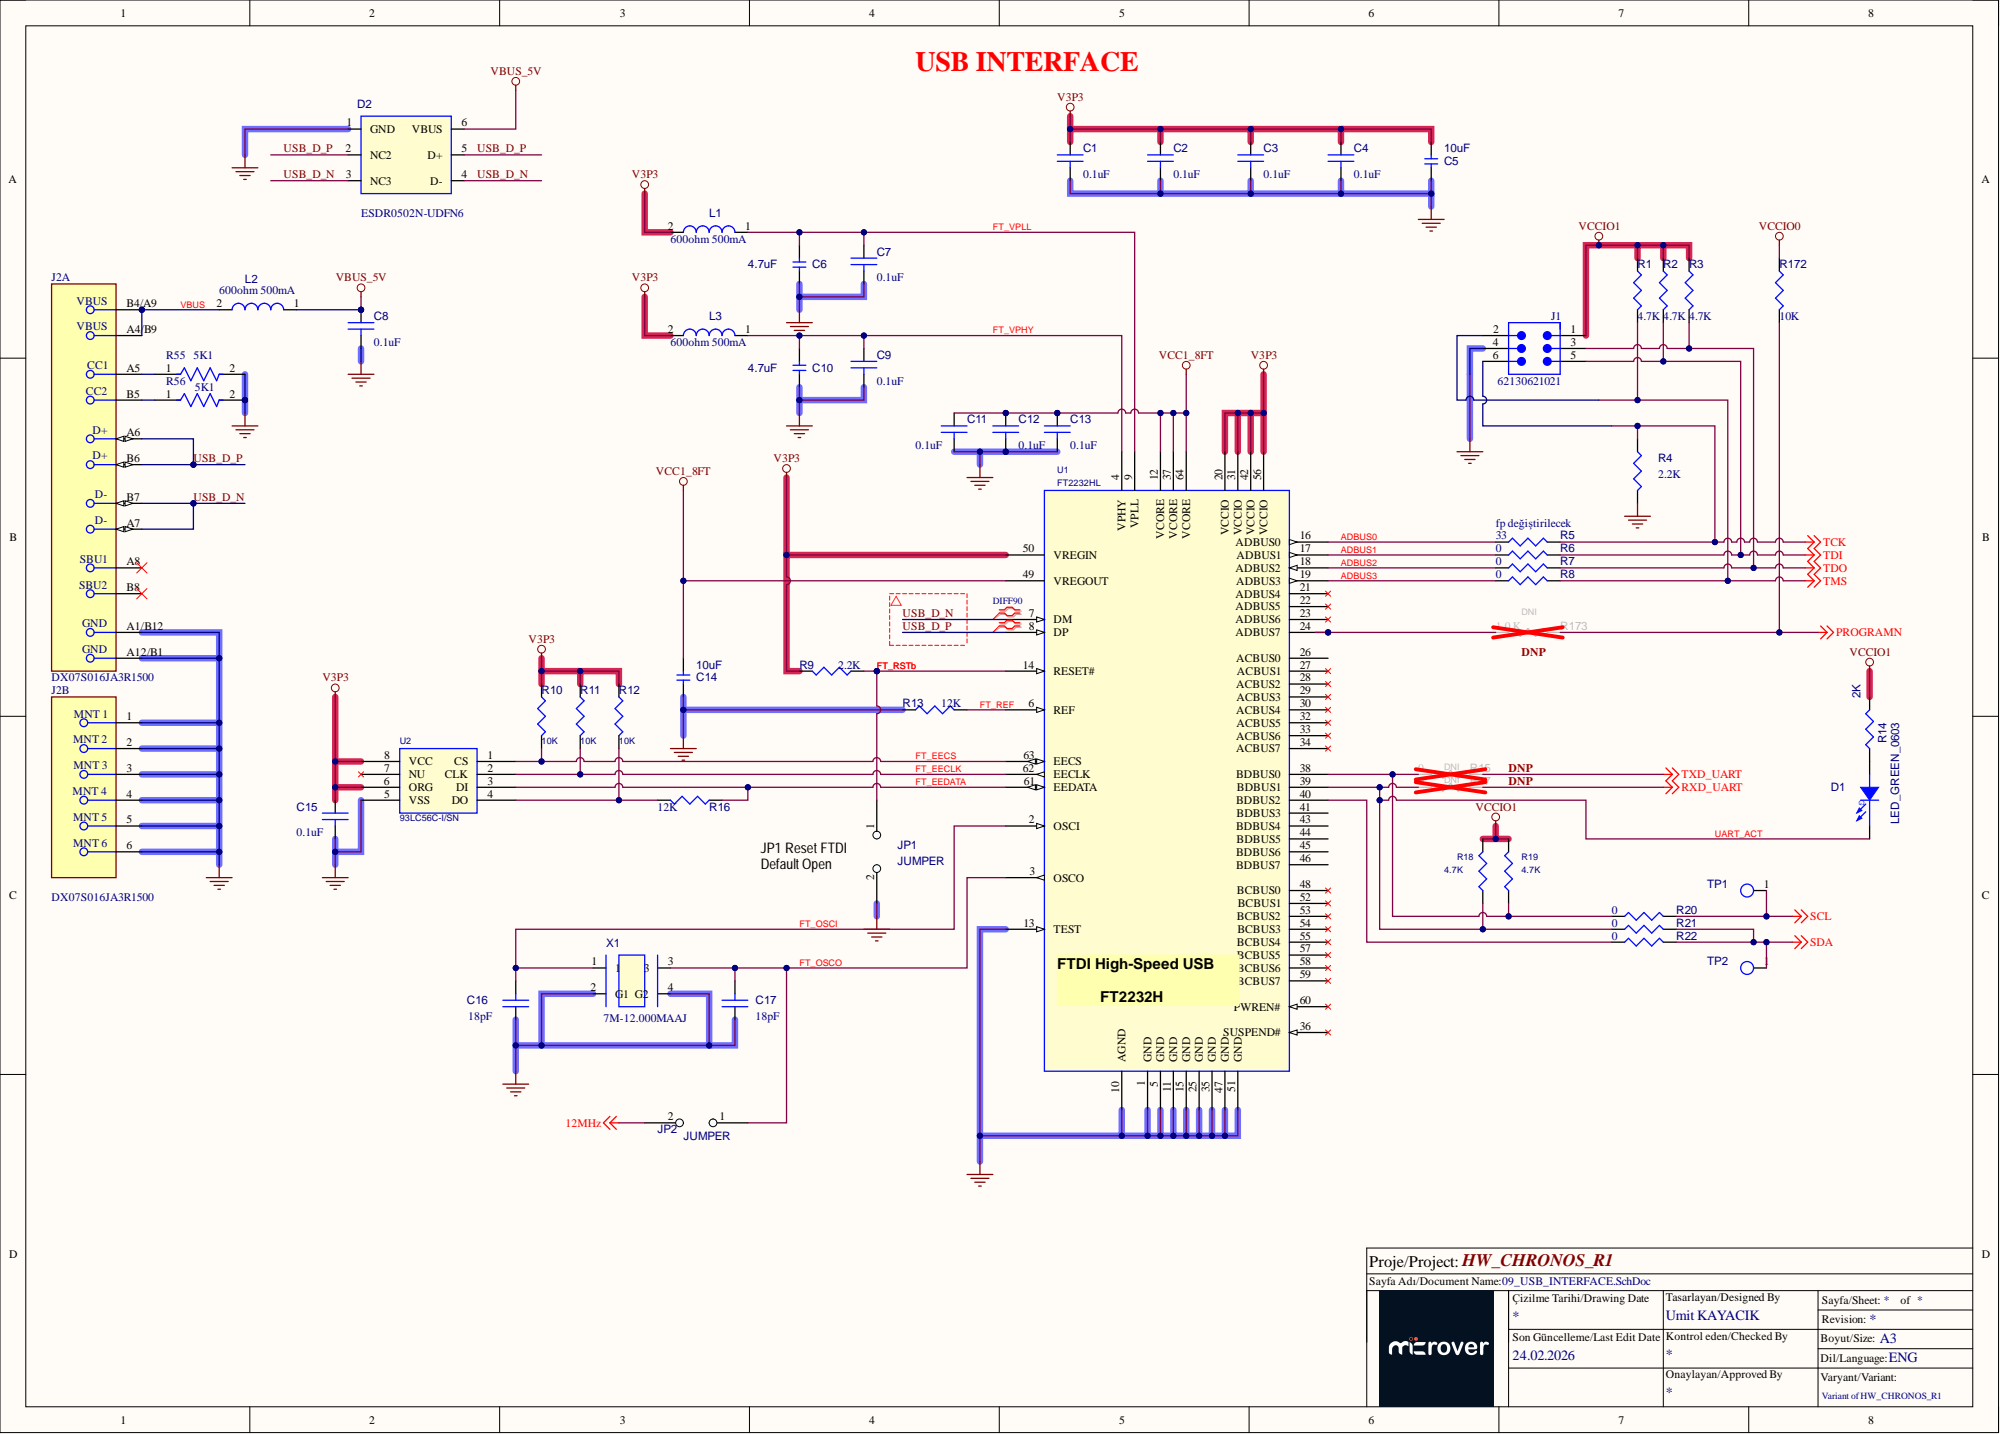
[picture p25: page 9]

C7 0.1uF FT_VPHY

OSCI 2

TEST 13

Sayfa Adı/Document Name:

09_USB_INTERFACE.SchDoc
Çizilme Tarihi/Drawing Date

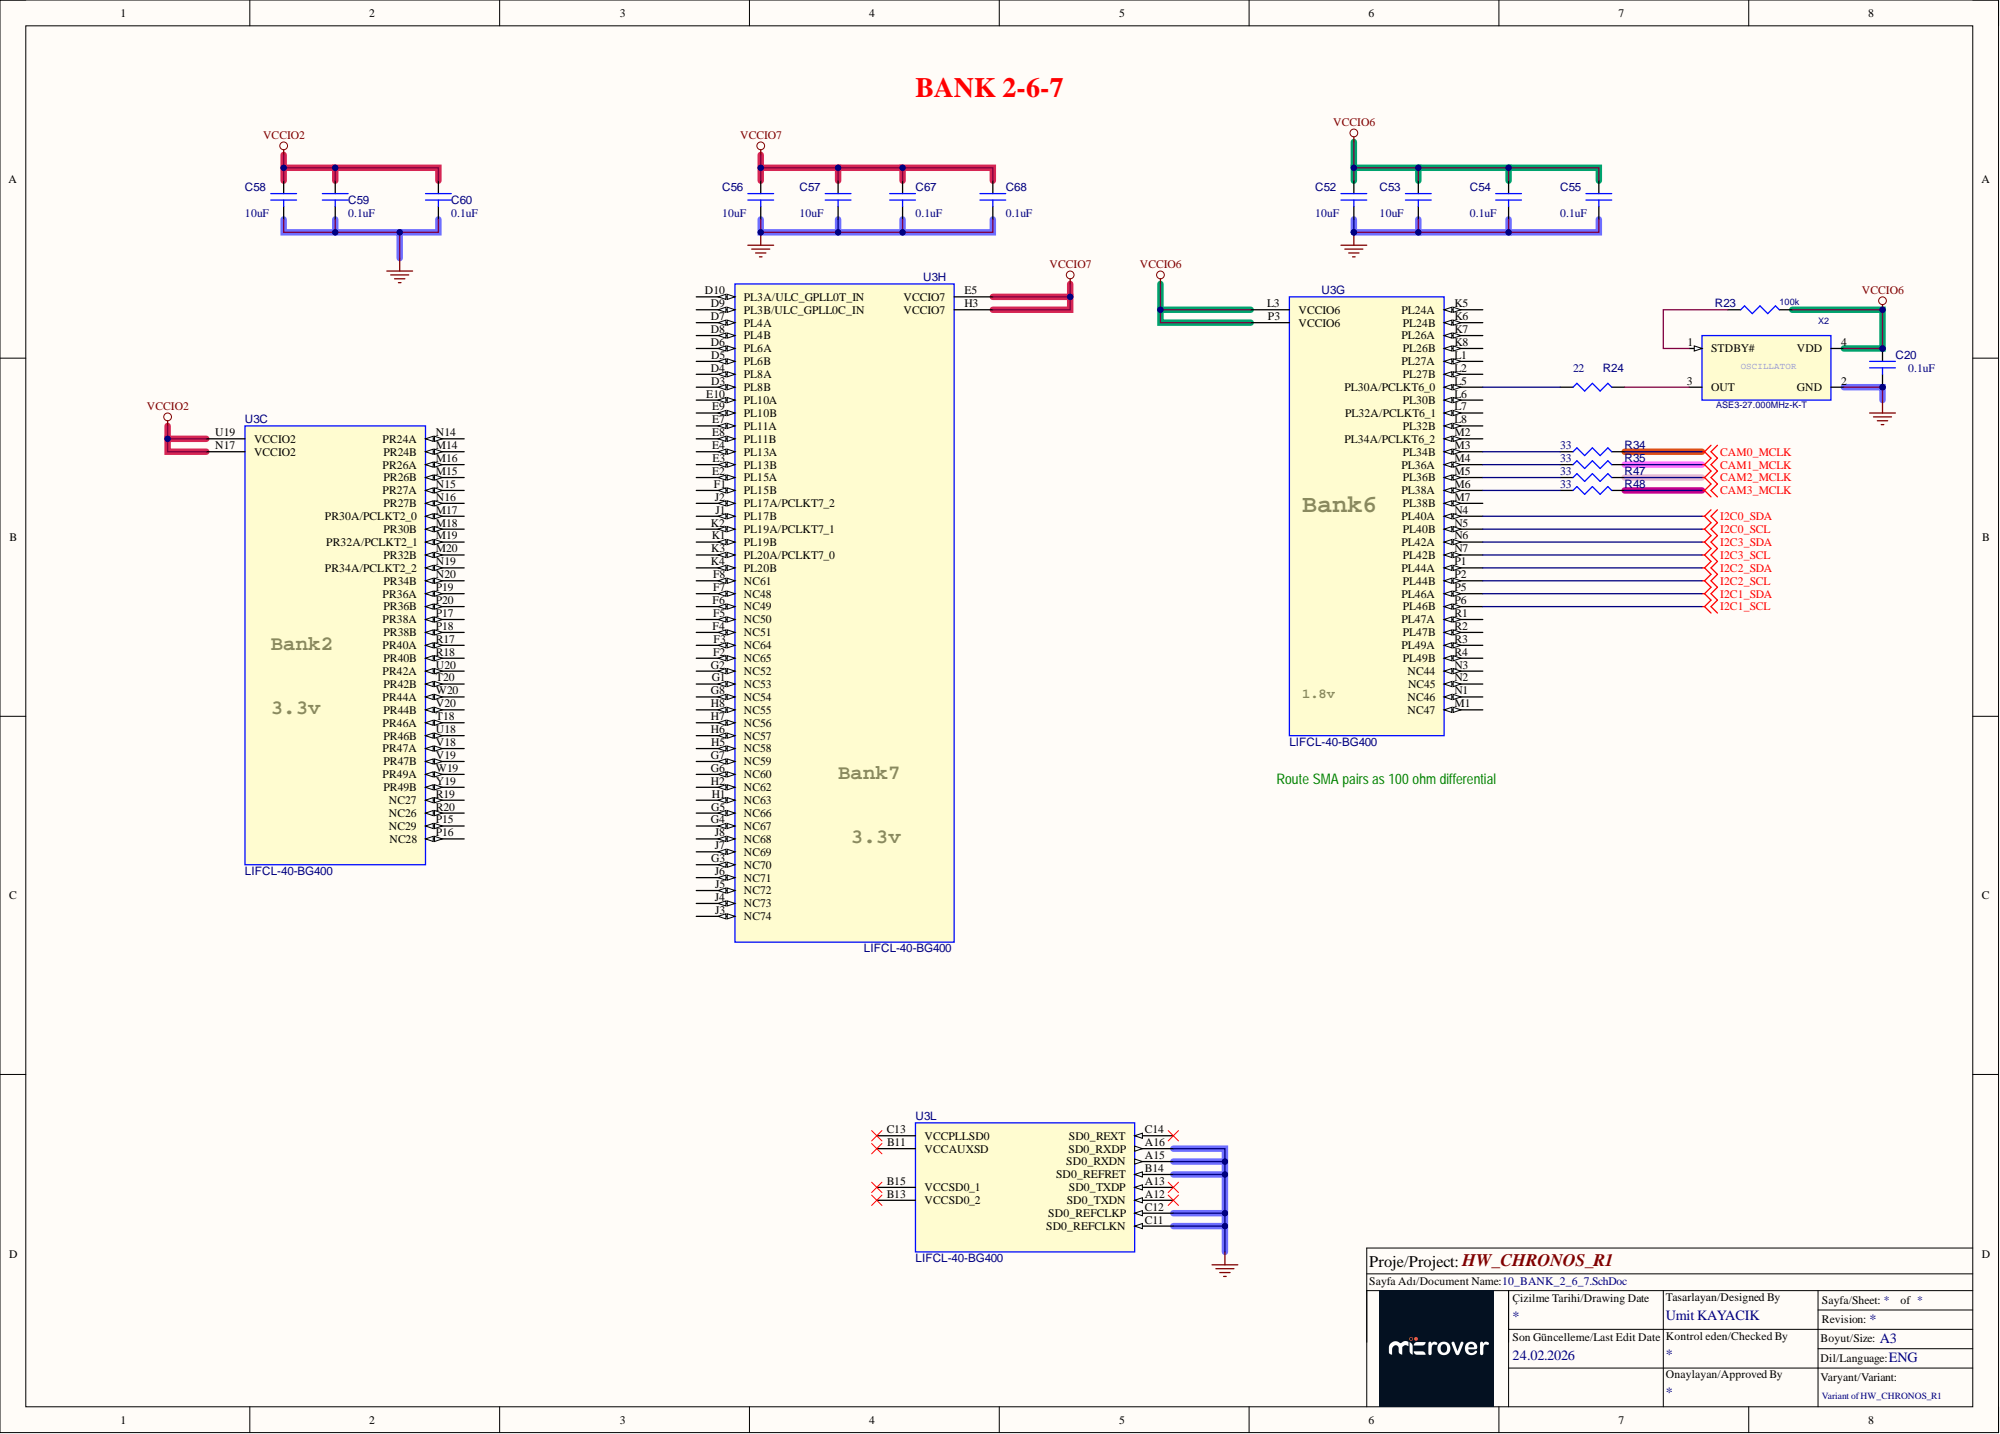
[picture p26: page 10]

Route SMA pairs as 100 ohm differential

Sayfa Adı/Document Name:

10_BANK_2_6_7.SchDoc
Çizilme Tarihi/Drawing Date

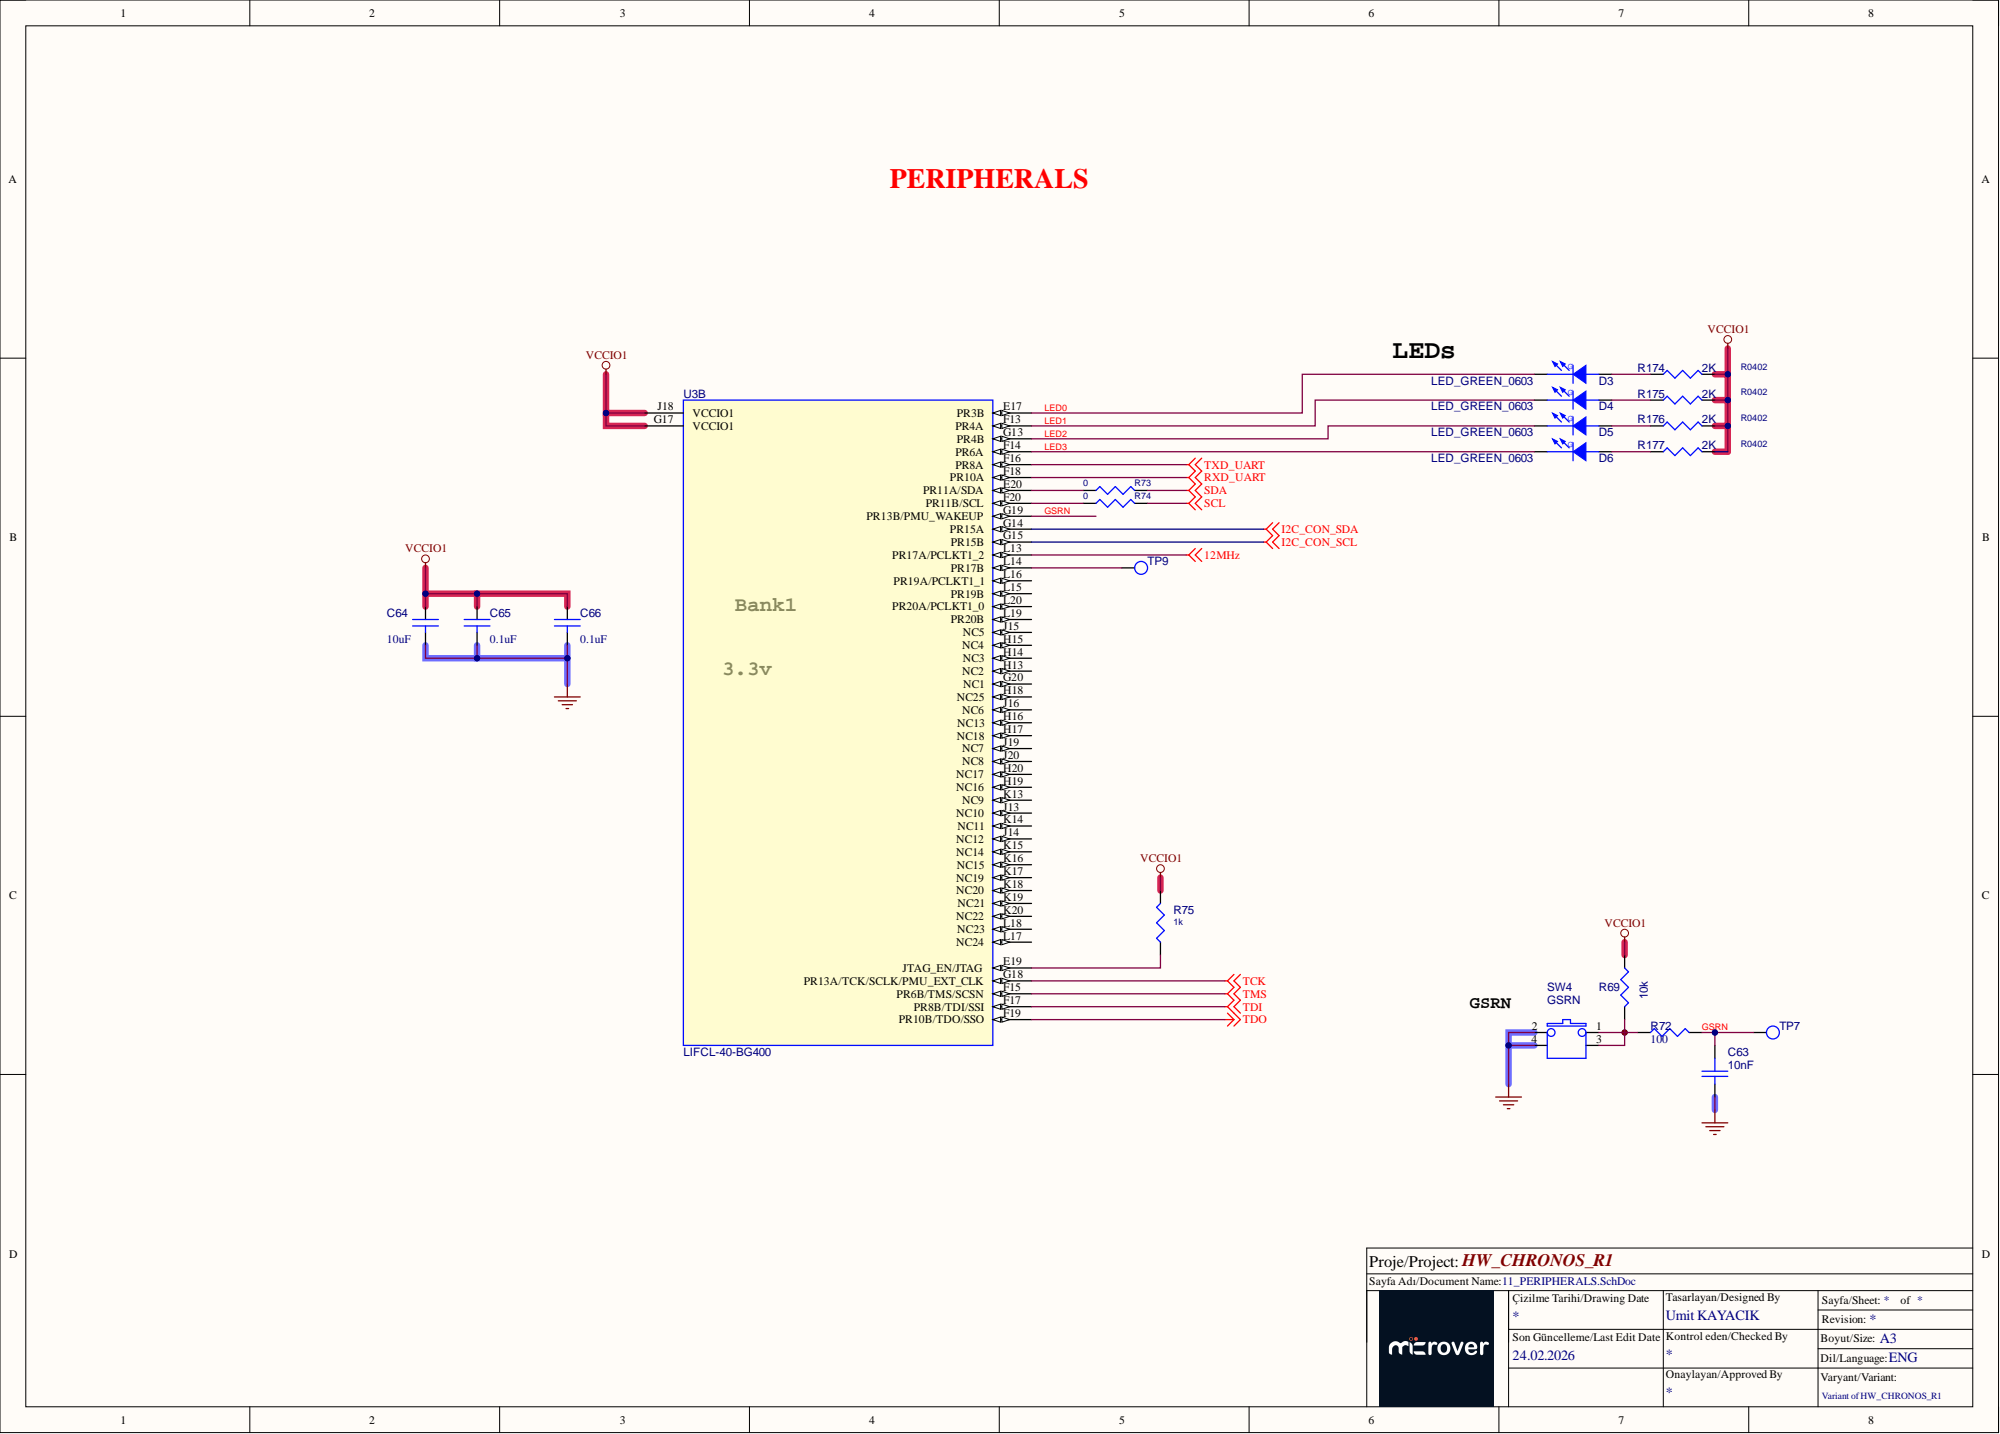
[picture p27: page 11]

LED_GREEN_0 6 0 3

G 1 3 | LED_GREEN_0 6 0 3


INITN indicator will light
if an error occurs during
configuration programming

DONE indicator will light when
configuration is successfully
completed

Parallel / SPI Config Header

Place close to Flash

Keep noisy signals away from ADC circuit

Sayfa Adı/Document Name:

12_CONFIGURATIN_AND_ADC.SchDoc
Çizilme Tarihi/Drawing Date


Sayfa Adı/Document Name:

13_IMU.SchDoc
Çizilme Tarihi/Drawing Date


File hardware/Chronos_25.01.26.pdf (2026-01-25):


Proje/Project: Power Regulators

Sayfa Adı/Document Name:

Son Güncelleme/Last Edit Date

Kontrol eden/Checked By


Proje/Project: Power CSI and Banks

Sayfa Adı/Document Name:

02 - Power CSI and Bank Power.SchDoc
ÇizilmeTarihi/DrawingDate

Son Güncelleme/Last Edit Date

Kontrol eden/Checked By


Proje/Project: Power Decoupling

Sayfa Adı/Document Name:

Son Güncelleme/Last Edit Date

Kontrol eden/Checked By


LVDS RX Termination Resistors

NOTE: Place close to FPGA

Proje/Project: Camera Interface (DPHYs)

NOTE:
1. Match length within pair <= 0.1mm, match length between pairs <=1.0mm.
2. Differential impedance should be 100 ohms and 50 ohms as a single ended signal
3. All the power rails should be capable of carrying 1A current

Sayfa Adı/Document Name:

Son Güncelleme/Last Edit Date

Kontrol eden/Checked By

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

LVDS RX Termination Resistors

Proje/Project: Camera Interface (DPHYs)

Sayfa Adı/Document Name:

NOTE: Place close to FPGA

Son Güncelleme/Last Edit Date

Kontrol eden/Checked By

Keep LEDs away from Camera


Proje/Project: Soft DPHY

Sayfa Adı/Document Name:

Son Güncelleme/Last Edit Date

Kontrol eden/Checked By


Route USBpair 90 ohm impedance

R9 2.2K FT_RSTb FT_RSTb | RESET# 14

Proje/Project: USB Interface

Sayfa Adı/Document Name:

Son Güncelleme/Last Edit Date

Kontrol eden/Checked By


Route SMA pairs as 100 ohm differential

Sayfa Adı/Document Name:

Son Güncelleme/Last Edit Date

Kontrol eden/Checked By


LED 0 L E D _ G R E E N _ 0 6 0 3

G 1 7 | F 1 3 | LED 1

G 1 3 | L E D _ G R E E N _ 0 6 0 3 LED 2


Parallel / SPI Config Header

INITN indicator will light
if an error occurs during
configuration programming

DONE indicator will light when
configuration is successfully
completed

Place close to Flash

Proje/Project: Configuration and ADC

Sayfa Adı/Document Name:

10 -Configuration And ADC.SchDoc
ÇizilmeTarihi/DrawingDate

Son Güncelleme/Last Edit Date

Kontrol eden/Checked By

Keep noisy signals away from ADC circuit


Sayfa Adı/Document Name:

Son Güncelleme/Last Edit Date

Kontrol eden/Checked By


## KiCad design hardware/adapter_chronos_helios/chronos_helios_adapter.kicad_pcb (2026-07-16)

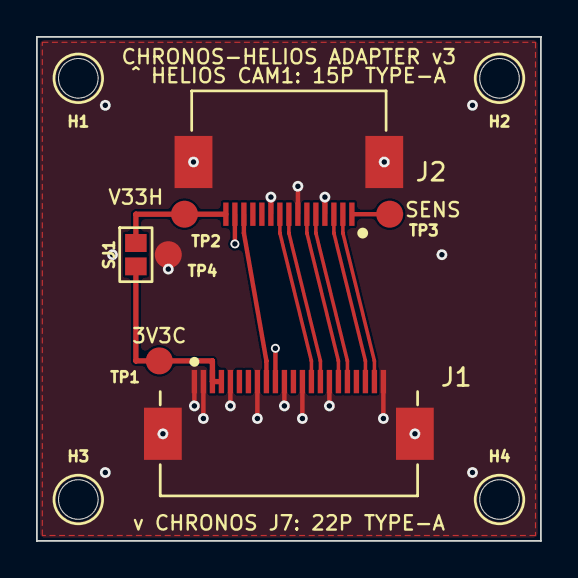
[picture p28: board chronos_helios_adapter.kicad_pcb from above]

Board: 4 copper layers, 28.0 x 28.0 mm, 11 parts (0 on the bottom side), 12 nets.

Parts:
H1, H2, H3, H4: M2; MountingHole_2.2mm_M2
J1: FPC-05F-22PH20; Hirose_FH12-22S-0.5SH_1x22-1MP_P0.50mm_Horizontal
J2: F0502-B-15-15T-R; Hirose_FH12-15S-0.5SH_1x15-1MP_P0.50mm_Horizontal
SJ1: OPEN; SolderJumper-2_P1.3mm_Open
TP1: 3V3_CHRONOS; TestPoint_Pad_D1.5mm
TP2: 3V3_HELIOS; TestPoint_Pad_D1.5mm
TP3: SENSE_H; TestPoint_Pad_D1.5mm
TP4: GND; TestPoint_Pad_D1.5mm

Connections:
CSI_CLK_N: J1.15, J2.8
CSI_CLK_P: J1.14, J2.9
CSI_D0_N: J1.21, J2.2
CSI_D0_P: J1.20, J2.3
CSI_D1_N: J1.18, J2.5
CSI_D1_P: J1.17, J2.6
GND: J1.1, J1.2, J1.5, J1.8, J1.11, J1.13, J1.16, J1.22, J1.MP, J2.4, J2.7, J2.10, J2.MP, TP4.1
I2C_SCL: J1.9, J2.13
I2C_SDA: J1.10, J2.14
SENSE_H: J2.1, TP3.1
V33_CHRONOS: J1.3, J1.4, SJ1.1, TP1.1
V33_HELIOS: J2.15, SJ1.2, TP2.1

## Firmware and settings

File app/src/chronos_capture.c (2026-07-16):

/*
 * Chronos Multi-Camera Capture Library Implementation
 *
 * Copyright (C) 2025 Chronos Project
 *
 * V4L2 MMAP capture with an optional CUDA device-copy path.
 *
 * Frames are captured into driver-owned MMAP buffers and the CPU pointer is
 * handed to the consumer directly.  Buffers are NOT re-queued until the
 * consumer calls chronos_release_frame_set(), so delivered frame data can
 * never be overwritten behind the consumer's back.  When built with
 * CHRONOS_WITH_CUDA, chronos_get_cuda_ptr() copies the frame into a
 * per-buffer cudaMalloc'd allocation (tight pitch) on demand.
 */

#include <stdio.h>
#include <stdlib.h>
#include <string.h>
#include <unistd.h>
#include <fcntl.h>
#include <errno.h>
#include <pthread.h>
#include <time.h>
#include <sys/ioctl.h>
#include <sys/mman.h>
#include <sys/select.h>
#include <linux/videodev2.h>
#include <linux/i2c-dev.h>

#include "chronos_capture.h"

#ifdef CHRONOS_WITH_CUDA
#include <cuda_runtime_api.h>
#endif

/* ============================================================================
 * Internal Structures
 * ============================================================================ */

/* Buffer state */
typedef enum {
    BUF_STATE_FREE,
    BUF_STATE_QUEUED,
    BUF_STATE_DEQUEUED,
} buffer_state_t;

/* Internal buffer structure */
typedef struct {
    void *cpu_ptr;              /* mmap()ed V4L2 buffer */
    size_t length;              /* mmap length */
#ifdef CHRONOS_WITH_CUDA
    void *cuda_ptr;             /* device-side copy destination */
    bool cuda_valid;            /* device copy is current for this frame */
#endif
    buffer_state_t state;
} internal_buffer_t;

/* Per-camera context */
typedef struct {
    int fd;                                     /* V4L2 device fd */
    char dev_path[32];                          /* Device path */
    internal_buffer_t buffers[CHRONOS_BUFFER_COUNT];
    uint32_t buf_count;
    uint32_t bytesperline;                      /* negotiated line pitch */
    uint32_t sizeimage;                         /* negotiated frame size */
    uint32_t last_sequence;                     /* for drop detection */
    bool have_sequence;
    bool has_gain_ctrl;                         /* driver exposes V4L2_CID_GAIN */
    int32_t gain_min;
    int32_t gain_max;
    bool streaming;
} camera_context_t;

/* IMU context */
typedef struct {
    int iio_fd;
    char dev_path[64];
    bool enabled;
    chronos_imu_data_t latest_data;
    pthread_mutex_t lock;
} imu_context_t;

/*
 * In-flight frame set bookkeeping.  Each delivered frame set records which
 * buffer indices it borrowed from each camera; chronos_release_frame_set()
 * looks the entry up and re-queues those buffers.  Worst case every buffer
 * of every camera sits in its own (incomplete) set.
 */
#define CHRONOS_MAX_INFLIGHT_SETS (CHRONOS_NUM_CAMERAS * CHRONOS_BUFFER_COUNT)

typedef struct {
    bool valid;
    uint32_t sync_sequence;
    int buf_idx[CHRONOS_NUM_CAMERAS];           /* -1 = no frame from that cam */
} inflight_set_t;

/* Main context */
typedef struct {
    camera_context_t cameras[CHRONOS_NUM_CAMERAS];
    imu_context_t imu;

    chronos_config_t config;
    chronos_stats_t stats;

    pthread_t capture_thread;
    pthread_mutex_t mutex;
    pthread_cond_t frame_ready_cond;
    pthread_mutex_t i2c_lock;

    chronos_sync_frame_set_t *pending_frame_set;
    bool frame_available;

    inflight_set_t inflight[CHRONOS_MAX_INFLIGHT_SETS];

    chronos_frame_callback_t callback;
    void *callback_user_data;

    bool initialized;
    bool running;

    /* Persistent FPGA control link (7-bit 0x3C on /dev/i2c-N) */
    int fpga_i2c_fd;

    /* Cached FPGA sync status (refreshed ~1 Hz by the capture thread) */
    bool fpga_status_known;
    bool fpga_sync_ok;

    /* Frame-rate measurement window */
    uint64_t fps_window_start_ns;
    uint32_t fps_window_frames;

#ifdef CHRONOS_WITH_CUDA
    bool cuda_enabled;
#endif
} chronos_context_t;

static chronos_context_t g_ctx = { .fpga_i2c_fd = -1 };

static uint64_t monotonic_ns(void)
{
    struct timespec ts;
    clock_gettime(CLOCK_MONOTONIC, &ts);
    return (uint64_t)ts.tv_sec * 1000000000ULL + (uint64_t)ts.tv_nsec;
}

/* ============================================================================
 * FPGA Control (I2C)
 * ============================================================================ */

/*
 * The FPGA register bank lives at 7-bit address 0x3C.  The bus fd is opened
 * once at chronos_init() (with I2C_SLAVE already set) and kept for the whole
 * session; read and write helpers share it under i2c_lock.
 *
 * The bus number is taken from CHRONOS_FPGA_I2C_BUS (default 1, matching the
 * Jetson Orin NX I2C2 instance that the device-tree overlay activates).
 */
#define CHRONOS_FPGA_I2C_ADDR  0x3C
#ifndef CHRONOS_FPGA_I2C_BUS
#define CHRONOS_FPGA_I2C_BUS   1
#endif

/* Register map – must stay in lock-step with config_regs.sv */
enum {
    FPGA_REG_CTRL          = 0x00,
    FPGA_REG_FRAME_RATE    = 0x01,
    FPGA_REG_PULSE_WIDTH_L = 0x02,
    FPGA_REG_PULSE_WIDTH_H = 0x03,
    FPGA_REG_CAM_ENABLE    = 0x04,
    FPGA_REG_DATA_TYPE     = 0x05,
    FPGA_REG_TRIG_DELAY_0  = 0x10,
    FPGA_REG_STATUS        = 0x20,
    FPGA_REG_ERROR         = 0x21,
    FPGA_REG_VERSION       = 0xF0,
    FPGA_REG_ID_L          = 0xFE,
    FPGA_REG_ID_H          = 0xFF,
};

/* CTRL register bits */
#define FPGA_CTRL_TRIGGER_ENABLE  0x01

/* Expected identity values */
#define FPGA_VERSION_EXPECTED  0x10
#define FPGA_ID_L_EXPECTED     0x05
#define FPGA_ID_H_EXPECTED     0xC4

static int fpga_i2c_open(void)
{
    char dev_path[32];

    if (g_ctx.fpga_i2c_fd >= 0)
        return 0;

    snprintf(dev_path, sizeof(dev_path), "/dev/i2c-%d", CHRONOS_FPGA_I2C_BUS);
    int fd = open(dev_path, O_RDWR);
    if (fd < 0) {
        fprintf(stderr, "FPGA I2C open %s failed: %s\n", dev_path, strerror(errno));
        return -1;
    }
    if (ioctl(fd, I2C_SLAVE, CHRONOS_FPGA_I2C_ADDR) < 0) {
        close(fd);
        return -1;
    }
    g_ctx.fpga_i2c_fd = fd;
    return 0;
}

static void fpga_i2c_close(void)
{
    if (g_ctx.fpga_i2c_fd >= 0) {
        close(g_ctx.fpga_i2c_fd);
        g_ctx.fpga_i2c_fd = -1;
    }
}

static int fpga_i2c_write(uint8_t reg, uint8_t val)
{
    if (g_ctx.fpga_i2c_fd < 0)
        return -1;

    uint8_t buf[2] = { reg, val };
    pthread_mutex_lock(&g_ctx.i2c_lock);
    int ret = write(g_ctx.fpga_i2c_fd, buf, sizeof(buf)) == sizeof(buf) ? 0 : -1;
    pthread_mutex_unlock(&g_ctx.i2c_lock);
    return ret;
}

static int fpga_i2c_read(uint8_t reg, uint8_t *val)
{
    if (g_ctx.fpga_i2c_fd < 0)
        return -1;

    int ret = -1;
    pthread_mutex_lock(&g_ctx.i2c_lock);
    if (write(g_ctx.fpga_i2c_fd, &reg, 1) == 1 &&
        read(g_ctx.fpga_i2c_fd, val, 1) == 1) {
        ret = 0;
    }
    pthread_mutex_unlock(&g_ctx.i2c_lock);
    return ret;
}
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

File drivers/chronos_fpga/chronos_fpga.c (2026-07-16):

// SPDX-License-Identifier: GPL-2.0-only
/*
 * Chronos FPGA control driver
 *
 * Copyright (C) 2026 Chronos Project
 *
 * The Chronos board (HW_CHRONOS_R1) aggregates four OV9281 cameras in a
 * Lattice CrossLink-NX FPGA and forwards them to the Jetson Orin NX on a
 * single 2-lane MIPI CSI-2 link using virtual channels VC0..VC3.  The FPGA
 * is the only device on this board the Jetson can control: it exposes an
 * I2C slave (7-bit 0x3C) implementing the register file described in
 * fpga/rtl/config_regs.sv.  The sensors are on FPGA-private SCCB buses and
 * are initialised by the FPGA itself; the ICM-42688-P IMU is wired to the
 * FPGA only.
 *
 * This driver:
 *   - binds to the "chronos,fpga-ctrl" node on the Jetson camera I2C bus,
 *   - verifies the ID/VERSION registers (warns but does not fail on
 *     mismatch, so bring-up with older bitstreams still works),
 *   - exposes the control/status registers through sysfs,
 *   - exports a small in-kernel API used by the chronos_csi bridge to
 *     start/stop the FSIN trigger generator when streaming starts/stops.
 */

#include <linux/bits.h>
#include <linux/device.h>
#include <linux/i2c.h>
#include <linux/module.h>
#include <linux/mutex.h>
#include <linux/of.h>
#include <linux/regmap.h>
#include <linux/sysfs.h>

#include "chronos_fpga.h"

struct chronos_fpga {
	struct i2c_client *client;
	struct regmap *regmap;
	/* Serialises multi-register sequences (16-bit L/H pairs). */
	struct mutex lock;
};

/*
 * 0x20..0x37 (status, error, frame counters) and 0xF0..0xFF (version/ID)
 * change under hardware control and must never be served from cache.
 * CTRL (0x00) is volatile too because bit 1 (soft reset) self-clears.
 */
static const struct regmap_range chronos_volatile_ranges[] = {
	regmap_reg_range(CHRONOS_REG_CTRL, CHRONOS_REG_CTRL),
	regmap_reg_range(CHRONOS_REG_STATUS, CHRONOS_REG_FRAME_CNT_H(3)),
	regmap_reg_range(CHRONOS_REG_VERSION, CHRONOS_REG_ID_H),
};

static const struct regmap_access_table chronos_volatile_table = {
	.yes_ranges = chronos_volatile_ranges,
	.n_yes_ranges = ARRAY_SIZE(chronos_volatile_ranges),
};

static const struct regmap_config chronos_fpga_regmap_config = {
	.reg_bits = 8,
	.val_bits = 8,
	.max_register = 0xFF,
	.volatile_table = &chronos_volatile_table,
	.cache_type = REGCACHE_RBTREE,
};

/* ---------------------------------------------------------------------------
 * In-kernel API (used by the chronos_csi bridge)
 * ------------------------------------------------------------------------- */

int chronos_fpga_trigger_enable(struct i2c_client *client, bool enable)
{
	struct chronos_fpga *priv;

	if (!client)
		return -ENODEV;

	priv = i2c_get_clientdata(client);
	if (!priv)
		return -ENODEV;

	return regmap_update_bits(priv->regmap, CHRONOS_REG_CTRL,
				  CHRONOS_CTRL_TRIG_EN,
				  enable ? CHRONOS_CTRL_TRIG_EN : 0);
}
EXPORT_SYMBOL_GPL(chronos_fpga_trigger_enable);

int chronos_fpga_set_frame_rate(struct i2c_client *client, u8 fps)
{
	struct chronos_fpga *priv;

	if (!client)
		return -ENODEV;

	priv = i2c_get_clientdata(client);
	if (!priv)
		return -ENODEV;

	if (fps < CHRONOS_FRAME_RATE_MIN || fps > CHRONOS_FRAME_RATE_MAX)
		return -EINVAL;

	return regmap_write(priv->regmap, CHRONOS_REG_FRAME_RATE, fps);
}
EXPORT_SYMBOL_GPL(chronos_fpga_set_frame_rate);

int chronos_fpga_read_status(struct i2c_client *client, u8 *status)
{
	struct chronos_fpga *priv;
	unsigned int val;
	int ret;

	if (!client || !status)
		return -EINVAL;

	priv = i2c_get_clientdata(client);
	if (!priv)
		return -ENODEV;

	ret = regmap_read(priv->regmap, CHRONOS_REG_STATUS, &val);
	if (ret)
		return ret;

	*status = val;
	return 0;
}
EXPORT_SYMBOL_GPL(chronos_fpga_read_status);

/**
 * chronos_fpga_get_client - resolve an "fpga" phandle to the bound client
 * @np: device node of the FPGA control device (chronos,fpga-ctrl)
 *
 * Returns the i2c_client with a device reference held (drop it with
 * put_device(&client->dev)), ERR_PTR(-EPROBE_DEFER) if the node exists but
 * this driver has not bound yet, or ERR_PTR(-ENODEV) on bad input.
 */
struct i2c_client *chronos_fpga_get_client(struct device_node *np)
{
	struct i2c_client *client;

	if (!np)
		return ERR_PTR(-ENODEV);

	/*
	 * of_find_i2c_device_by_node() looks the node up on the I2C bus and
	 * runs i2c_verify_client() on the match, so a non-NULL result is
	 * guaranteed to be a real client (reference taken on its device).
	 */
	client = of_find_i2c_device_by_node(np);
	if (!client)
		return ERR_PTR(-EPROBE_DEFER);

	/* Not bound (or bound to something else) yet: defer, don't crash. */
	if (!i2c_get_clientdata(client) ||
	    !client->dev.driver ||
	    strcmp(client->dev.driver->name, "chronos-fpga")) {
		put_device(&client->dev);
		return ERR_PTR(-EPROBE_DEFER);
	}

	return client;
}
EXPORT_SYMBOL_GPL(chronos_fpga_get_client);

/* ---------------------------------------------------------------------------
 * sysfs
 * ------------------------------------------------------------------------- */

static ssize_t trigger_enable_show(struct device *dev,
				   struct device_attribute *attr, char *buf)
{
	struct chronos_fpga *priv = dev_get_drvdata(dev);
	unsigned int val;
	int ret;

	ret = regmap_read(priv->regmap, CHRONOS_REG_CTRL, &val);
	if (ret)
		return ret;

	return sysfs_emit(buf, "%d\n", !!(val & CHRONOS_CTRL_TRIG_EN));
}

static ssize_t trigger_enable_store(struct device *dev,
				    struct device_attribute *attr,
				    const char *buf, size_t len)
{
	struct chronos_fpga *priv = dev_get_drvdata(dev);
	bool enable;
	int ret;

	ret = kstrtobool(buf, &enable);
	if (ret)
		return ret;

	ret = chronos_fpga_trigger_enable(priv->client, enable);
	if (ret)
		return ret;

	return len;
}
static DEVICE_ATTR_RW(trigger_enable);

static ssize_t frame_rate_show(struct device *dev,
			       struct device_attribute *attr, char *buf)
{
	struct chronos_fpga *priv = dev_get_drvdata(dev);
	unsigned int val;
	int ret;

	ret = regmap_read(priv->regmap, CHRONOS_REG_FRAME_RATE, &val);
	if (ret)
		return ret;

	return sysfs_emit(buf, "%u\n", val);
}

static ssize_t frame_rate_store(struct device *dev,
				struct device_attribute *attr,
				const char *buf, size_t len)
{
	struct chronos_fpga *priv = dev_get_drvdata(dev);
	u8 fps;
	int ret;

	ret = kstrtou8(buf, 0, &fps);
	if (ret)
		return ret;

	ret = chronos_fpga_set_frame_rate(priv->client, fps);
	if (ret)
		return ret;

	return len;
}
static DEVICE_ATTR_RW(frame_rate);

static ssize_t pulse_width_show(struct device *dev,
				struct device_attribute *attr, char *buf)
{
	struct chronos_fpga *priv = dev_get_drvdata(dev);
	unsigned int lo, hi;
	int ret;

	mutex_lock(&priv->lock);
	ret = regmap_read(priv->regmap, CHRONOS_REG_PULSE_WIDTH_L, &lo);
	if (!ret)
		ret = regmap_read(priv->regmap, CHRONOS_REG_PULSE_WIDTH_H, &hi);
	mutex_unlock(&priv->lock);

	if (ret)
		return ret;

	return sysfs_emit(buf, "%u\n", (hi << 8) | lo);
}
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

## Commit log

2026-01-25 Complete Chronos firmware implementation with modern README files - FPGA firmware, Linux drivers, capture library, demo apps, and documentation
2026-02-09 Hardware updated
    [01- Power Regulators.SchDoc, 01- Title Page.SchDoc, 0154010.DR.STEP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]
2026-02-17 Hardware updated according to review items
    [12 - JETSON_CON.SchDoc]
2026-02-23 Hardware production files are ready.
    [01- Power Regulators.SchDoc, 03- Power Decoupling.SchDoc, 04 - Camera Interface.SchDoc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]
2026-05-30 fpga: add blinky bring-up project for LIFCL-40 ES
    Minimal blinky used to prove the Radiant 2.0 SP1 bitstream + SPI-flash programming path on the CrossLink-NX ES silicon, including the ES IDCODE patch helper. Generated Radiant build outputs are gitig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
2026-05-30 fpga: rebuild MIPI CSI-2 subsystem on Lattice D-PHY IP
    Replace the placeholder D-PHY/skeleton datapath with a working 4-camera aggregator: soft D-PHY RX x4 and hard D-PHY TX wrappers, a shared csi2_pkg (ECC/CRC/SOP), corrected csi2_rx/csi2_tx packet layers, FWFT async frame_buffer, round-robin tx_arbiter with VC tagging, FWFT sync_fifo, CDC helpers, and an I2C/SCCB master + OV9281 init sequencer to replace the cam_scl/sda tie-offs. Design point locked at 4 cams @ 30 fps (FSIN-triggered slave mode); see DESIGN_DECISIONS.md and fpga/ip/README.md.
2026-05-30 fpga/sim: add CSI-2 datapath loopback testbench and D-PHY models
    Behavioral mipi_dphy_rx/tx models plus a self-checking loopback testbench (csi2_rx -> frame_buffer -> tx_arbiter -> csi2_tx) that injects a synthetic OV9281 frame and verifies data type, VC tagging, 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
2026-05-30 fpga: update pinout/timing constraints for rebuilt MIPI hierarchy
    Point create_clock/set_max_delay at the real generate-block hierarchy (per-camera recovered RX byte clocks, hard-TX byte clock), drop the stale PLL-derived clk_byte, refresh set_clock_groups for the 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
2026-05-30 drivers: swap IMU to ICM-42688 and fix CSI multi-camera streaming
    Replace the BMI088 IMU driver with an ICM-42688 driver (Makefile + device tree updated to match). In the chronos_csi V4L2 driver, enable the FPGA frame-sync generator when the first of any channel starts streaming instead of only VC0, so independently opened cameras still receive FSIN. Device tree refreshed for the rebuilt MIPI aggregator.
    [chronos_csi.c, icm42688_chronos.c]
2026-05-30 app: update chronos_capture for rebuilt multi-camera pipeline
    Rework the capture library to align with the corrected CSI driver/FPGA datapath (per-channel streaming and VC handling).
    [chronos_capture.c]
2026-05-30 docs: add hardware/firmware audit and project memory
    Add the hardware/firmware audit notes and a CLAUDE.md capturing the board, toolchain (Radiant 2.0 SP1 ES path), and MIPI subsystem decisions for future sessions; minor README touch-up.
2026-05-30 hardware: add HW_CHRONOS_R1 BOM and schematic
    Add the R1 bill of materials and schematic PDF under BOM/ and Schematic/, replacing the loose top-level hardware_schematics.pdf.
    [Bill of Materials-HW_CHRONOS_R1(Variant of HW_CHRONOS_R1).xlsx]
2026-07-11 hardware: add Protel netlist export (Chronos.NET) and Altium project updates
    Netlist is the wiring source of truth used to re-verify the FPGA pinout: 27 MHz osc X2 -> L5, camera MCLKs on M3..M6, SID straps on J3..J6 pin 17, LED and VCCIO1 topology. Ignore Altium History/ back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
    [Chronos.PrjPcb]
2026-07-11 fpga: code-quality fixes from full RTL review
    csi2_rx: word aligner now locks the FIRST matching 0xB8 bit offset (loop previously let the highest offset win via last-NBA-wins). frame_buffer: drop unused gray2bin. i2c_slave: add default_nettype guards.
2026-07-11 fpga: netlist-driven fixes for SF-AOV9281 bring-up
    chronos_top: forward 27 MHz X2 clock (new clk_27m input, L5) to per-camera XCLK outputs cam_mclk[3:0] (M3..M6) - the SF-AOV9281 has no oscillator and is dead without MCLK. Set SCCB DEV_ADDR per port from the SID straps (cam0/2=0x60, cam1/3=0x10). Invert led_status: user LEDs are active-low (anode to VCCIO1). PDC: add L5/M3..M6 sites and 27 MHz clock, move bank-1 UART/host-I2C to LVCMOS33 (VCCIO1=3.3V), fix LED comment.
2026-07-11 docs: switch camera to SincereFirst SF-AOV9281 (direct connect)
    Add SF-AOV9281 spec PDF and docs/sf_aov9281_direct_connect.md (pin map, SID address table, XCLK ownership, netlist-verified rails). Mark the Waveshare adapter doc obsolete and correct its guessed rail order. Refresh CLAUDE.md and DESIGN_DECISIONS.md with netlist facts and post-rebuild status.
2026-07-16 fpga: from-scratch review fixes; 192 MHz clock, i2c_slave rewrite, sims passing
    PLL 200->192 MHz (VCO was out of range, could never lock); i2c_slave rewritten with correct ACK timing + read prefetch; trigger_generator phase accumulator; csi2_rx combinational aligner lock + realign watchdog; tx_arbiter/csi2_tx truncated-packet escapes; dual-side FIFO resets; LED pulse stretchers; 3 testbenches passing under Icarus (run_sims.ps1).
2026-07-16 app+drivers: rework Jetson side to match real architecture
    app: V4L2 MMAP capture (NvBuffer/EGL removed), consumer-owned buffer requeue, FPGA CTRL/STATUS over persistent I2C fd, start/stop rollback via teardown_streams, optional CUDA. drivers: new chronos_fpga I2C driver (regmap+sysfs+in-kernel API), chronos_csi rewritten as async V4L2 subdev bridge, DTS rewritten with 4-VC bridge->NVCSI->VI graph, ov9281/imu quarantined.
    [chronos_capture.c, chronos_csi.c, chronos_fpga.c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]
2026-07-16 hardware: add Chronos J7 <-> Helios CAM1 adapter PCB (KiCad, JLC-ready)
    4-layer JLC04161H-7628, 100R diff pairs (0.20/0.174mm), I2C swap on board, supplies isolated (SJ1 open), polarity-safe SENSE pads + test points, M2 corner holes, LCSC C2856804 connectors (universal Hirose/XUNPU tab pads). fab/ contains Gerber zip + JLC BOM/CPL. DRC clean.
    [chronos_helios_adapter-B_Cu.gbl, chronos_helios_adapter-B_Mask.gbs, chronos_helios_adapter-B_Silkscreen.gbo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]
2026-07-16 docs: record full-review results, sim status and Jetson-side rework in CLAUDE.md
    Also picks up Altium autosaved touch of 12 - JETSON_CON.SchDoc from netlist inspection.
    [12 - JETSON_CON.SchDoc]
2026-07-16 hardware: adapter v2 - native 15p Helios side, crossover routed on board
    J2 changed from 22p RPi-mapped to a native 15-pin FH12 (XFCN F0502-B-15-15T-R, LCSC C2844857) so both cables are plain straight Type-A FFCs (Aerium 15p-22p cable no longer needed). Pin-1 sides differ between the boards, so the full pin-order reversal + I2C swap is routed inside the adapter: In2.Cu crossover lanes over a solid B.Cu GND plane, staggered 0.5/0.3 vias, I2C C-detour on the east side. Board grown to 28x28mm for the crossover field. DRC: 0 errors, 0 unconnected. Fab outputs, BOM/CPL, renders and README regenerated.
    [chronos_helios_adapter-B_Cu.gbl, chronos_helios_adapter-B_Mask.gbs, chronos_helios_adapter-B_Silkscreen.gbo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]
2026-07-16 hardware: adapter v3 - user-verified pin-1 sides, Helios link maps straight
    Physical check on the boards showed both pin 1s on the same absolute side (Helios CAM connector is opposite-handed vs standard FH12), so the 15p link maps straight (CAM.j <-> J2.j) instead of mirrored. All six CSI conductors now route as identical top-layer diagonals with zero vias; only the SDA/SCL swap crosses on In2.Cu. Added _check_map.py end-to-end signal-map verification (PASS). DRC 0 errors.
    [chronos_helios_adapter-B_Cu.gbl, chronos_helios_adapter-B_Mask.gbs, chronos_helios_adapter-B_Silkscreen.gbo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]
